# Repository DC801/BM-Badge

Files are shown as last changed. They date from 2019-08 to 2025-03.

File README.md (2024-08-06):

# DC801 Black Mage Badge

The DC801 Badge Platform for DC28+, featuring a [playable web build](https://dc801.github.io/BM-Badge/) to increase ease of access for content authorship workflows, as well as for archival access to the game when for the hardware is no longer available.

## Introducing Chapter 2 (for DC32)

A new expansion for the game has been added! Chapter 2 introduces King Gibson's castle and the badge's built-in USB-C serial interface. More characters, more puzzles, and more puns!

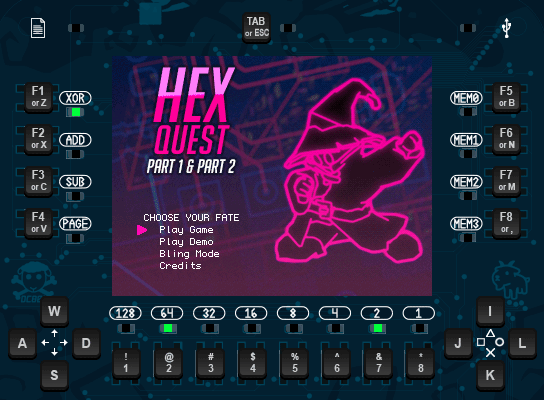
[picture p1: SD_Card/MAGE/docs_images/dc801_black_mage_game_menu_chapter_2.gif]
DC801 Black Mage Game 2024 main menu


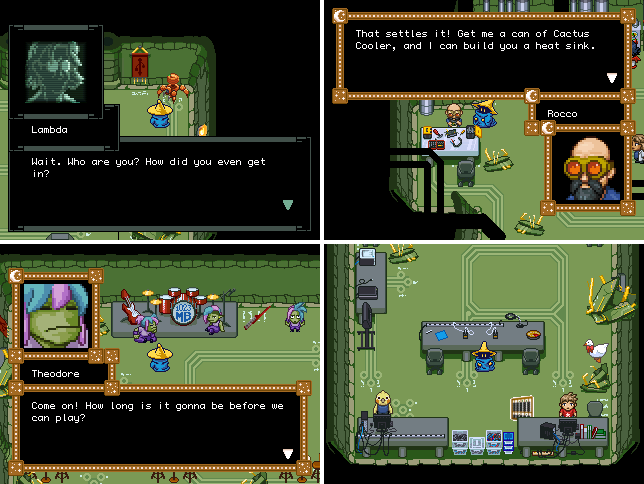
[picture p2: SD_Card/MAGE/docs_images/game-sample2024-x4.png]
DC801 Black Mage Game 2024 sample gameplay (screen only)


Use the terminal to engage with the world and solve puzzles:

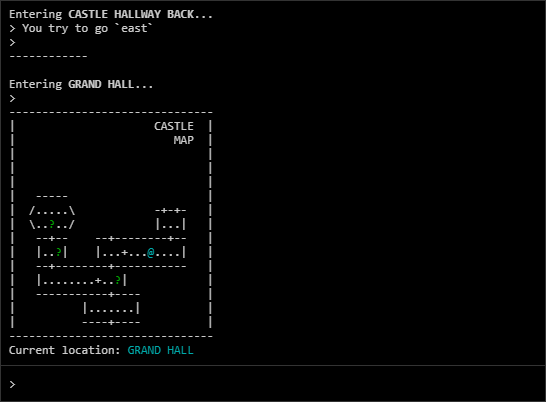
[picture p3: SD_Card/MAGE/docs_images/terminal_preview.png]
DC801 Black Mage Game 2024 sample terminal


Chapter 1 content is still available with this release, and both chapters are accessible from the main menu.

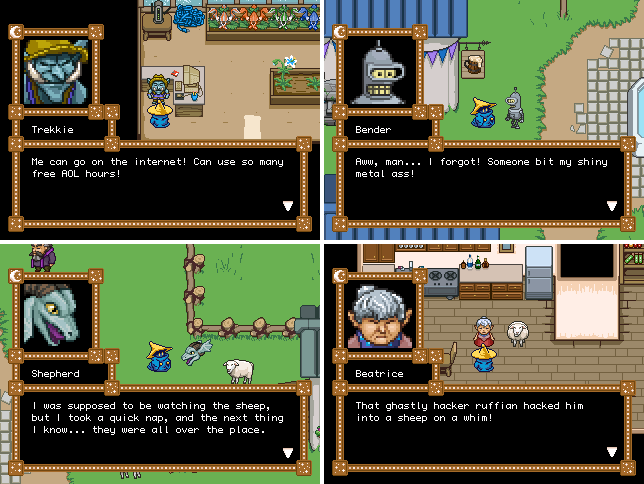
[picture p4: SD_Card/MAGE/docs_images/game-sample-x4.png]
DC801 Black Mage Game 2020 sample gameplay (screen only)


## Videos about the project

<a href="https://www.youtube.com/watch?v=QbsCsldlNKE" target="_blank">
Alex Chaveriat holds the DC801 Black Mage Badge up for your inspection<br />Watch Alex Chaveriat's review of the DC801 Black Mage Badge</a>

----

<a href="https://www.youtube.com/watch?v=-YtiRvzJ-uo" target="_blank">
Alex Chaveriat interviews Hamster at DEFCON 29 about the DC801 Black Mage Badge<br />Watch Alex Chaveriat interview Hamster at DEFCON 29 about the DC801 Black Mage Badge</a>

----

<a href="https://www.youtube.com/watch?v=cmqgIxQA0Sg" target="_blank">
Alex Chaveriat interviews Admiral Potato and Alamedyang about building the DC801 Black Mage Badge<br />Watch Alex Chaveriat interview Admiral Potato and Alamedyang about building the DC801 Black Mage Badge</a>

## Hardware

The DC801 BM-Badge brings you an expandable iteration of our robust platfom.

 - Core CPU is the Nordic nRF52840 SoC, on the u-blox BMD-340 module
   - [https://www.u-blox.com/en/product/bmd-34-series-open-cpu](https://www.u-blox.com/en/product/bmd-34-series-open-cpu)
   - 256k RAM, 1M internal flash, ARM® Cortex™ M4F CP @ 64Mhz
   - Bluetooth 5 with Bluetooth mesh and Zigbee support
   - Temperature sensor
 - 27 buttons with NKRO via a dedicated controller
   - Microchip ATiny1617 microcontroller, with UPDI programming support
   - [https://www.microchip.com/wwwproducts/en/ATtiny1617](https://www.microchip.com/wwwproducts/en/ATtiny1617)
 - 19 LEDs
 - SD card socket
 - 32MB of quad-spi flash
 - NAU8810 audio codec and speaker
 - 2.4" 240x320 TFT LCD screen with touch panel
 - LiPo battery with on-board charging
 - USB-C interface supporting USB endpoints
 - SAO 1.69bis and Saintcon MiniBadge expansion headers
 - Support for the DC801 ART front board expansion
 - JTAG via both standard ARM interface as well as Tag Connect
 - USB drag-and-drop programming via a UF2 interface (based on the [adafruit bootloader](https://github.com/adafruit/Adafruit_nRF52_Bootloader))
 - Exciting new artwork and sandwich design

Board design is in KiCad

See the [HW](/HW) directory for more info, schematics and etc

### ART - Asymmetric Resistive Token
Since this badge is a sandwich platform badge, we've include a template so that you can design your own front boards.

Check out the [Template](/HW/ART/Template) that you can create a new project in KiCad with.

## Software
 - Environment is GNU ARM GCC with your choice of IDE (We're currently using CLion and VSCode)
 - Need a J-Link Segger JTAG programmer to program the chip directly.
 - Custom game engine purpose-built for the badge that can automatically load custom games from the SD Card.
 - Included in the [SD_Card/MAGE](/SD_Card/MAGE) directory is a binary encoder that allows you to generate your own games with our engine using open source tools such as the Tiled Map Editor and our custom json scripting language.
 - Instructions to set up your own dev environment and desktop testing build of our game engine in [EnvironmentSetup.md](/EnvironmentSetup).
 - [Comprehensive engine documentation and content creation guide](SD_Card/MAGE/README.md)

## Gameplay Videos

<a href="https://vimeo.com/487527877" target="_blank">DC28 DC801 SAFEMODE badge, 2020-12-04 development update</a>

[DC28 DC801 SAFEMODE badge, 2020-12-04 development update](https://vimeo.com/487527877): Watch almost 6 minutes of 100% in-engine gameplay in our 2020-12-04 development update video!

<a href="https://vimeo.com/515088170" target="_blank">DC28 DC801 SAFEMODE badge, 2021-02-21 development update</a>

[DC28 DC801 SAFEMODE badge, 2021-02-21 development update](https://vimeo.com/515088170):
Watch one of our puzzles and see some of our new narrative focused engine scripting capabilities in our 2021-02-21 development update video!

----

## DC32 dev team

### Hardware

#### PCB Electronics
- @hamster

#### PCB Art
- corfidbizna
- alamedyang

#### Badge Design
- @admiral_potato
- @hamster

#### Art Board
- redactd

#### Joystick Covers
- @_Pexie

#### Software

#### Engine Lead
- @admiral_potato

#### Script System
- @admiral_potato

#### Script Tooling
- alamedyang
- @admiral_potato
- nibley

#### Programming Support
- Tawnos
- Solra Bizna
- Youssef Moosa
- Cedric Hutchings (cedric_h)

### Graphics

#### 2D Art
- alamedyang
- corfidbizna
- Hippi3Hack3r

#### 3D Art
- @admiral_potato
- nthday

### Story

#### Writing
- alamedyang
- Hippi3Hack3r

#### Scripting
- alamedyang
- ThatDeadGuy and CJDJ
- nibley
- mmedei
- korinakuma

#### Goose Facts Consultant
- lys

### Special Thanks
- 7thdrxn
- Aaron Freed
- anonbecause
- courtyen
- DisplayGFX
- flame3722
- HeyItsWaters
- hipu
- HumanDLC
- korinakuma
- laughdat
- Liam "junkmail" Thomas
- @MuxLuxx
- NewGnu
- @_Pexie
- Solra Bizna
- Spooks
- TuckleberryWinn
- And all the playtesters who we missed!

----

## DC28 dev team

Project owner
- [@nemus](https://twitter.com/Nemus801)

Software Team
- [@_bashNinja](https://twitter.com/_bashNinja)
- [@admiral_potato](https://twitter.com/admiral_potato)
- [@corfidbizna](https://twitter.com/corfidbizna)
- [kiyoshigawa](https://twa.ninja/)
- [@newzie1](https://twitter.com/newzie1)
- [@tazmodius](https://twitter.com/tazmodius)
- @alamedyang

Hardware Team
- [@dvdfreitag](https://twitter.com/dvdfreitag)
- [@hamster](https://twitter.com/hamster)

Honorable Mention
- [@pips801](https://twitter.com/pips801)

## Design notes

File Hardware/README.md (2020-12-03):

We will provide the hardware schematics and KiCAD files once we ship the final badge designs.

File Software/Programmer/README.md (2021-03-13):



## DC801 Production Badge Programmer ##

This app is designed to program both the attiny1617 and the BMD-340 using an Atmel ICE and a JLink device respectively

Programming is accomplished by running batch files in the data directory

Firmware is also in the data directory and is currently hard coded to use a certain version

### Usage

You can either just run the app in the Release\DC801 Badge Programmer directory, or use the installer to install a local application on your PC

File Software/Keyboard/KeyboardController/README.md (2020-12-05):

# Keyboard Controller

This is the keyboard controller for the DC801 BM-Badge platform.

# Hardware

The microcontroller is an [attiny1617](https://www.microchip.com/wwwproducts/en/ATTINY1617) ([datasheet](http://ww1.microchip.com/downloads/en/devicedoc/attiny3217_1617-data-sheet-40001999b.pdf))

Connected to this microcontroller is a 5x6 grid of physical buttons, one capacitive touch button, and a 4 wire resistive touch screen.

Communication with the main processor is via a GPIO for an interrupt line, and a I2C bus, configured as a slave device.

# Key Scanning

The grid consists of 5 rows and 6 columns, but there is only 26 buttons present.  Please refer to the board schematic for the specific layout.

The method for scanning the buttons is pretty simple:

- Set all rows as outputs and to a 'high' state
- Set all cols as inputs with pull up resistors
- Set one row to a 'low' state
- Scan all the cols for state
- If the stored state is different than the current state, emit a key interrupt on the GPIO
- Save the new state
- Lather, rinse, and repeat

# Cap Touch

The wizard's hat is configured as a capacitive touch button using the native Atmel PTC stuff.  There is a 1k resistor between the device and the button.

The button is read every scan for a touch, and will emit a key interrupt if the state changes.

# Resistive touch screen

The touch screen consists of 4 lines, labeled X+, X-, Y+, and Y-.  These lines are connected in a star pattern.  To determine a touch position:

- Set X+ high, and X- low
- Set Y+ and Y- as inputs with no pullups
- Configure the ADCMUX to sense with the Y+ pin
- Measure the voltage present on Y+

To measure for X, swap the X and Y lines in the above and read again.

Basically, you are setting up a voltage gradient across the screen, and where your finger touches the screen forms a voltage divider in proportion to the position across the gradient.

# Software

The software skeleton was created using [Atmel START](https://start.atmel.com/).  From there it was customized in [Atmel Studio](https://www.microchip.com/mplab/avr-support/atmel-studio-7) to support the specific functions required.

# Usage

The chip listens on I2C slave address 0x23.  You don't need to set a register or write to the device first, just start reading data.

The data returned is a snapshot of the current state of the buttons and touch panel.  It is in the format of 6 bytes - the first 4 are treated as a 32 bit value.  Each bit offset in this value describes the state of a button.

See the bm_board.h file for the bit offsets.

Bytes 5 and 6 are the X and Y positions of the touch screen.  Note that even when not touching, it will return a value that is not zero.

You don't need to read all 6 bytes if you don't care about the touch screen, just read 4 bytes.

The Key Interrupt GPIO will strobe low when a key changes state.  It is typically at a 'high' level.  
It will stay low for at least 10ms.  You will then need to read the I2C bus to find out the key state.  In practice it takes about 50ms to toggle a button on and off tapping as quick as you can.

Since the Key Interrupt is tied to the nRF52840 pin for nRESET, it is set to be normally high.  If you don't want your application to reset when a key interrupt comes in, you need to make sure you remove "CONFIG_GPIO_AS_PINRESET" from your application Makefile. See [this page](https://devzone.nordicsemi.com/f/nordic-q-a/18170/how-can-i-disable-reset-of-p0-21) for further info.

Keypresses are not stored or buffered, you must read the state before it changes or ignore the keypress.

Touch screen touch events do not generate an interrupt.

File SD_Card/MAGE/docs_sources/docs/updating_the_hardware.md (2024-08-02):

# Updating the Hardware

Steps for updating a physical Black Mage Game badge.

::: tip Note
The `game.dat` engine version must match the Mage Game Engine (MGE) being run. If you update the engine without updating the `game.dat`, for example, the badge will bluescreen.
:::

## Game Engine

Perform this step if you must upgrade the game engine itself. This is necessary if testing new engine features or if you are updating your badge from Chapter 1 to Chapter 2. (If you are testing new scenario data on the same engine version, this step is not necessary.)

::: warning
Purple "bootleg" badges do not carry the firmware to update in this way. Instead, you will need to have a JTAG Programmer, and will need to know how to use it. Please contact the DC801 Black Mage Badge game team if you want help updating a purple badge.
:::

To start the game in bootloader mode, hold down the hex digit `1` button while you power on the hardware. If bootloader mode was successfully triggered, the screen will be white and the LEDs will blink in a circular pattern.

If the hardware is plugged into a computer while it is in bootloader mode, it will appear as a drive called `DC801BOOT` or `NRF52BOOT`. Copy the new game engine UF2 (the filename doesn't matter) onto the drive.

Once the UF2 is copied, the drive will disconnect. If the badge does not restart automatically at this point, you may restart it now.

### Tips

- Plug into the badge on the USB-C port. This port is on the front, on the upper right side, near the capacitive button that looks like a hat. Do not use the micro USB port (available on some back plates) as this is for programming the lights.
- If the copy seems to be taking a long time (more than 2 minutes) or appears to suffer from other kinds of I/O problem, try using a different USB-C cable.
- Macs with Apple Silicon may display an error message when the drive unmounts, like `The operation can’t be completed because the device disappeared` or `The Finder can’t complete the operation because some data in “bm_badge.uf2” can’t be read or written. Error code -36` You may ignore these.

## `game.dat`

To install new scenario data on the hardware, prepare a microSD card (FAT32) with a folder called `MAGE` in the root directory. Copy the new `game.dat` into `MAGE/`, then insert the card into the slot on the hardware. (The microSD card slot is on the top of the badge, opposite the USB-C port.)

If the hardware determines its `game.dat` is different from the one on the microSD card (or if you hold `MEM3` when turning on the badge), you will see:

```
The file `game.dat` on your SD card does not match
what is on your badge ROM chip.

 SD hash: [game.dat checksum #1]
ROM hash: [game.dat checksum #2]

Would you like to update your scenario data?
------------------------------------------------

> Press MEM0 to cancel

> Press MEM3 to update the ROM
```

Press `MEM3` (the lowest button on the right side of the screen) to tell the hardware to flash the new data. The time it takes to copy will depend on the size of the `game.dat` file, but it may take a few minutes. (The Chapter 2 `game.dat`, released August 2024, takes about 90 seconds.)

The badge should reboot automatically once the write is completed.

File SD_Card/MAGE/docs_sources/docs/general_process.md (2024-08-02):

---
tags: [ 'spritesheets', 'json', 'entities', 'entity', 'animations', 'character', 'tile', 'tileset', 'tiled', 'portraits', 'entity_type', 'collisions', 'vector objects', 'scripts', 'dialogs', 'serial dialogs', 'doors', 'doorways', 'cutscenes', 'encoder' ]
---

# General Process

An example production pipeline. The exact order can vary a bit, and previous steps might be revisited at any point.

## Entities

Prepare entities. For each entity:

1. Acquire or produce [spritesheets](tilesets).
2. In Tiled, [make a tileset JSON file](tilesets#creating-a-tileset-json-file).
	1. Put it in `scenario_source_files/entities/`.
	2. For [character entities](entity_types#character-entity), set the `Class` property for all tiles to what you want the entity's `entity_type` name to be.
	3. Set frames and timings for your [animations](animations), if any.
		1. For [character entities](entity_types#character-entity), prepare [animations](animations) for at least idle, walking, and action.
3. For each [character entity](entity_types#character-entity):
	1. Use the [web encoder](encoder#web-encoder) to [assign animations and NSEW directions](tilesets/entity_management_system).
	2. Paste updated entity data into [`entity_types.json`](mage_folder#entity_types-json).
4. Prepare dialog portraits.
	1. In Tiled, [make a tileset JSON file](tilesets#creating-a-tileset-json-file) for the talk portrait images.
		1. Put it in `scenario_source_files/entities/`.
	2. Prepare [`portraits.json`](mage_folder#portraits-json).
	3. Assign portraits to their entities in [`entity_types.json`](mage_folder#entity_types-json) if the portrait name does not match an [entity_type](entity_types#character-entity) name.

## Maps

Prepare map(s). For each map:

1. Acquire or produce [tilesets](tilesets).
2. In Tiled, [make a tileset JSON file](tilesets#creating-a-tileset-json-file).
	1. Put it in `scenario_source_files/tilesets/`.
	2. Set [tile collisions](tilesets#tile-collisions) for each tile.
3. In Tiled, [create a map](maps) using the tileset(s) from above.
4. Place entities on the map.
	1. Set [entity properties](entity_properties), e.g.
		1. `Name`
		2. `is_player`
		3. [`on_tick`](script_slots#on-tick) script
		4. [`on_interact`](script_slots#on-interact) script
		5. [`on_look`](script_slots#on-look) script
5. [Draw vector shapes](vector_objects), (see [Doors](techniques/doors)) e.g.
	1. Walk paths
	2. Doorways
	3. "Walking out the door" paths
	4. Camera targets
6. Add the map to [`maps.json`](mage_folder#maps-json), and supply properties like its [`on_load`](script_slots#on-load) and [`on_tick`](script_slots#on-tick) scripts.

## Dialog Skins

Prepare dialog skin(s). For each skin:

1. Acquire or produce [tilesets](tilesets).
2. In Tiled, [make a tileset JSON file](tilesets#creating-a-tileset-json-file).
	1. Put it in `scenario_source_files/tilesets/`.
3. Add dialogSkin file(s) to [`scenario.json`](mage_folder#scenario-json).

## Game Logic

Prepare game behavior. You can either use MGS or JSON for this, or even a mix.

1. For MGS files: write [MGS Natlang](mgs/mgs_natlang). (See the natlang docs!)
2. For JSON files (note: you must also add each JSON file to [`scenario.json`](mage_folder#scenario-json) or the game encoder won't see it):
	1. Prepare [dialogs](dialogs) inside `scenario_source_files/dialogs/`.
	2. Prepare [serial dialogs](serial_dialogs) inside `scenario_source_files/serial_dialogs/`.
	3. Prepare [scripts](scripts) inside `scenario_source_files/scripts/`.
		1. Plan logic with flowcharts (optional)

## Encode Game

Encode the `game.dat` using the [encoder](encoder) (either the [web](encoder#web-encoder) version or the [CLI](encoder#cli-encoder) version).

## Play Test

Test the game in one of three ways:

1. [Web build](web_build):
	1. Remember to use the web build appropriate for the version of the encoder you're using!
	2. Drag the new `game.dat` into the browser window.
	3. Run the game.
2. Desktop build (see [MGE VM](mge_vm)):
	1. Move `game.dat` to the right place.
	2. Run the game.
3. Verify on real badge hardware. See: [Updating the Hardware](updating_the_hardware)
	1. Copy `game.dat` onto a microSD card.
	2. Insert the microSD card into hardware.
	3. Flash the game.
	4. Run the game.

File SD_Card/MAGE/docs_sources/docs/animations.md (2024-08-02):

---
tags: [ 'spritesheets', 'tilesets', 'tiled', 'entity', 'entity management system', 'entity_types.json', 'handlers', 'frames' ]
---

# Animations

In Tiled, animations are assigned to tiles within a [spritesheet](tilesets). To an assign an animation to a tile, select a tile — preferably something indicative of what the animation will be, such as a first step for a walking animation — and press the button for the animation editor, which looks like a movie camera:

the fourth icon is a movie camera

You will then see a second window for assigning frames to your animation. Set the frame duration (in milliseconds), then double click on the desired tile to add it as a frame to the animation. You can adjust the timing of the frames or move/remove frames as you like, and you'll be able to see your changes live in the preview directly below.

## MGE Animation Considerations

For [character entities](entity_types#character-entity), you need not prepare an animation for all cardinal directions — e.g. there is only a fright/shock animation in *Chrono Trigger* for the south direction.

The [encoder](encoder) accommodates animation flipping with its [entity management system](entity_management_system), so you don't need sprite tiles for both left-facing and right-facing sprites if you're comfortable with mirroring your left-facing and right-facing sprites.

The Mage Game Engine (MGE) animation system requires that each animation have at least two frames, though, so for animations that aren't actually "animated," you might set two of the same frame back-to-back. #researchthis

## Animation Types

Three types of animations are built into the MGE for [character entities](entity_types#character-entity), and they are triggered in straightforward and predictable ways. [`entity_types.json`](mage_folder#entity_types-json) defines which animations are of which type, and they can be defined and adjusted within the [encoder](encoder) or manually with a text editor.

### Idle

This is what the character entity does by default.

Usually the idle consists of long periods of stillness, followed by a brief fidget: a blink, a small movement of the head, a sheep chewing its cud etc. For flying entities, the idle will likely consist of the entity hovering in place.

The idle animation does not include things like turning around to face different things, nor should it include multiple kinds of fidgets that interact with complex timing. If you want an entity to do more complex behaviors when idle, including facing somewhere specific or playing back other kinds of animations once in a while (a sheep that performs a chewing animation twice a second but lowers its head to chomp a fresh mouthful of grass every 15 seconds), consider using an [`on_tick`](script_slots#on-tick) script to [handle](techniques/handlers) this instead.

Entities look far more alive with an idle animation, even if it's just an occasional blink. Regardless, while the entity need not *appear* to have an idle animation, the MGE still expects one, so you should define one, even if it's just the same two frames back-to-back.

Idle animations are expected to loop seamlessly.

::: tip Best Practice
To avoid robotic synchronization between entities, try to stagger their animation timings by setting the `current_frame` property for that entity on their Tiled map or via [SET_ENTITY_CURRENT_FRAME](actions/SET_ENTITY_CURRENT_FRAME) inside a [script](scripts).
:::

### Walking

This animation plays when entities move within the game. For flying or hovering entities without an explicit walk cycle, you can simply re-use the idle animation.

Walking animations are expected to loop seamlessly.

### Action

This animation plays for the player character when the player presses the "action" button. It can also be deliberately triggered for arbitrary character entities via a script.

::: tip Best Practice
The engine uses the modulo of the animation index for playback, so if there is no action animation defined, likely the idle animation will play instead. If the idle animation is quite long, this means the entity will be frozen in place, doing apparently nothing, for some time. (For the player character, this also prevents the player from moving or doing anything else until the animation is finished.) Therefore, it's best to provide an action animation, even if there aren't sprite tiles prepared specifically for an action animation. Our recommendation is to copy the fidget portion of the idle and to keep it brief.
:::

Action animations are not expected to loop. Instead they are expected to interrupt the idle/walk animation, play once, and then the idle/walk animation will resume.

### Additional Animations

You can add additional animations after the first three, too, as you like.

These animations can only be triggered by scripts, either for an arbitrary number of loops with [PLAY_ENTITY_ANIMATION](actions/PLAY_ENTITY_ANIMATION), or indefinitely with [SET_ENTITY_CURRENT_ANIMATION](actions/SET_ENTITY_CURRENT_ANIMATION).

Any animation set this way will be overridden by the walk animation if the character entity is compelled to move, and the entity will return to its idle after the walk motion is completed. (Teleports are an exception because entities don't switch animations when teleported.)

## Animation Transitions and Vamping

An action animation cannot be started and held (or [vamped](https://en.wikipedia.org/wiki/Ostinato#Musical_theater)) for an indeterminate length of time. If you want an action animation to behave this way, you'll need to split the animation into three pieces: the start transition, the "vamp," and the end transition. Trigger each with a script:

- [PLAY_ENTITY_ANIMATION](actions/PLAY_ENTITY_ANIMATION) with a `play_count` of `1` for the start transition
- [SET_ENTITY_CURRENT_ANIMATION](actions/SET_ENTITY_CURRENT_ANIMATION) for the "vamp," or the portion you want to repeat for an indeterminate amount of time
- [PLAY_ENTITY_ANIMATION](actions/PLAY_ENTITY_ANIMATION) with a `play_count` of `1` for the end transition

See Strong Bad in the Bob-Only Club cutscene in Chapter 1 of the Black Mage Game for an example of this approach.

## MGE Animation Timing

Requirements:

- Animations must have less than 256 frames.
- Frames must be less than 65,535 milliseconds long.
- (Don't worry, these are very difficult limits to hit!)

Animation frames will play for a minimum of one game frame regardless of duration (which, on the badge hardware, is currently in the ballpark of 130 ms, or 8 fps), so animations might play back very slowly in practice if you are frequently using short durations.

::: tip Best Practices
Because animations are not aborted when a character entity faces a new direction (it picks up where it left off in the new direction), it is beneficial to keep each animation of the same type completely uniform in terms of frame count and frame duration. This includes animations with fewer unique frames than others of its type, such as an animation from behind (where the face is obscured).

In addition, we recommend making sure each animation of the same type uses the same tile rows for each frame, even if some of the tiles within the column are technically identical, so that future changes to any of the previously identical frames will not create the need for timing adjustments.
:::

## Assigning Animations to Character Entities

For [character entities](entity_types#character-entity), animations are assigned to an animation type (idle, walk, etc.) and a cardinal direction (north, east, etc.) elsewhere; this cannot be done with Tiled. The [entity management system](entity_management_system) in the [web encoder](encoder#web-encoder) can help you assign animations to character entities if you don't want to do it by hand.

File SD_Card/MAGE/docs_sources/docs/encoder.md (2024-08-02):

---
next: hex_editor.md
---

# Encoder

There are two versions of the encoder, but both produce exactly the same `game.dat` file.

What gets encoded:

1. Everything listed in [`scenario.json`](mage_folder#scenario-json):
	- [scripts](scripts)
	- [dialogs](dialogs)
	- [serial dialogs](serial_dialogs)
	- dialogSkins
3. Portraits found in [`portraits.json`](mage_folder#portraits-json)
4. Entities found in [`entity_types.json`](mage_folder#entity_types-json)
5. Maps found in [`maps.json`](mage_folder#maps-json)
6. All [MGS files](mgs/mgs_natlang) within [`scenario_source_files`](mage_folder#scenario_source_files)

These items are encoded if they're being used by the game in some way; a script that isn't used by any maps, entities, or referenced any included script will be ignored. In other words, entities must be placed on at least one map to be encoded.

Superfluous JSON properties are completely ignored by the encoder. This is the only way documentation or notes can be written in JSON, since JSON doesn't support comments.

```json
"show_dialog-example": [
  {
    "name": "SHOW_DIALOG",
    "dialog": "dialog-example-start",
    "summary": "Oh, hi player! This is an example dialog summary!"
  },
  {
    "name": "SET_ENTITY_INTERACT_SCRIPT",
    "entity": "%SELF%",
    "script": "show_dialog-example-end",
    "to do": "redo with save flags so the branching persists"
  }
]
```

## `game.dat`

The `game.dat` file is the binary file containing all your game scenario content, including images.

Note that [save data](variables#save_data) will persist when using the same `game.dat` file. (Will reflashing the `game.dat` on the hardware wipe the save data explicitly? Probably. #verifyme — this is correct on the web at least.)

There is currently no way to bring save data from an old version of the `game.dat` to a new one, as the data structure of the save data is unlikely to be consistent between versions.

#### Run Your `game.dat`

- [Web build](web_build): Open the web build in your browser, then drag the `game.dat` into the browser window.
	- NOTE: If you play the game a little then drag the same `game.dat` in again, the game will appear to restart afresh — but in fact, save flags and the like may not be reset, **even when you didn't explicitly save inside the game**. Refresh the browser window to wipe existing game state.
- [Desktop build](desktop_build): If you use the [CLI encoder](#cli-encoder) to build the game, the `game.dat` will already be in the appropriate place to run the game. Otherwise, you must move your new `game.dat` to the [`MAGE` folder](mage_folder).
- Badge: see [Updating the Hardware](updating_the_hardware)

Also see: [debug tools](debug_tools)

## CLI Encoder

If you have Node.js installed, you can run the shell script `regenerate_dat_file.sh` to generate a new `game.dat` file. There are two versions of this file:

1. BM-Badge version:
	- `cd` into `MAGE/`.
	- Run the shell script. The `game.dat` will be made from the `scenario_source_files/` in `MAGE/`.
2. [Sample repo](mge_vm) version:
	- first argument: the `scenario_source_files/` folder to read from
	- second argument: where to write the `game.dat`
	- This version of the shell script also launches the game automatically.

This encoder is more useful than the web version when you want to test rapid iterations of your game data, as it is less involved. It is also much faster due to its ability to cache encoded graphics.

## Web Encoder

Open `SD_Card/MAGE/editor/index.html` with a web browser.

Once the page is open, you can either:

1. Drag your [`scenario_source_files`](mage_folder#scenario_source_files) folder into the window.
2. Click the "browse" button and choose the `scenario_source_files` using your operating system's file browser.

Confirm that you want to upload the contents of the folder to your browser, and the encoder will do its magic. If successful, click the "Download game.dat" button, and you're done!

The `game.dat` will be sent to your default download location, so to play it on the desktop build, you'll first have to move it to the correct place by hand or run the shell script `replace_dat_file_with_downloaded.sh`. (`cd` into the `SD_Card/MAGE/` folder before using the shell script!)

This encoder is more useful for times you need to [debug something](debug_tools), or when you want to manage an entity's animations (see below).

### Entity Manager

A special feature of the web version of the encoder is the [entity management system](tilesets/entity_management_system), which you can use to assign animations to [character entities](entity_types#character-entity).

## Debugging

(Don't forget that the game has a built-in [hex editor](hex_editor), too!)

### Encoder Console

Both versions of the encoder will tell you when something has gone wrong during the encoding process, and many errors should be self explanatory, e.g. `"No object named X could be found on map Y!"`

The error `Script: X could not be found in scenario.json` does not necessarily mean there is something wrong with [`scenario.json`](mage_folder#scenario-json), only that the encoder couldn't find a [script](scripts) by that name in any MGS file or in any of the script JSON files `scenario.json` knows about.

If you get the error "unexpected token" it means one of your files has invalid JSON, and you'll need to check your JSON files for invalid syntax. (A good text editor should have some kind of color coding to help you spot such errors.)

### Inspecting WIP Data

You can use the web encoder and your browser's JavaScript console to inspect various aspects about how the encoder interpreted your game files. (You could even interrupt the encoder *while* it collects and processes the data.)

- List of all [save flags](variables#save-flags)
- Number of colors in each tileset's pallet. If trying to reduce the file size of your `game.dat`, it can help to identify which tilesets have more colors than intended.
- …all the rest #expandme

This is most useful when the encoder throws an exception, because you can examine the state of data involved in triggering the error — the console messages alone might not identify which script or variable was causing the problem.

### Kaitai

Kaitai ([ide.kaitai.io](https://ide.kaitai.io)) is a tool that can parse and analyze binary data formats.

Available inside your [`MAGE` Folder](mage_folder) is a file called `mage_dat.ksy`. You can drag this in a Kaitai window, along with your `game.dat`, to analyze in great detail the encoded structure of your game.

This tool lets you easily see the relationship between the hex value of a script/entity_type/dialog/etc. and its name. E.g. if an [entity](entities)'s [`on_tick`](script_slots#on-tick) was being changed unexpectedly, but you only knew the hex value that it's being changed to (perhaps using the [hex editor](hex_editor), using Kaitai to find the name of the script in question can help you track down the problem.

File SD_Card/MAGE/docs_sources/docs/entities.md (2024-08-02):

---
tags: [ 'entity types', 'entity properties', 'hex editor', encoder', 'maps' ]
prev: vector_objects.md
---

# Entities

Entities are a basic element of the Mage Game Engine (MGE).

- All animated graphics must be entities, as ordinary [map](maps) tiles cannot change appearance or move.
- Any single tile object placed in one of a [map](maps)'s object layers will be one of the three [entity types](entity_types), automatically determined by the type of tile being placed.
- All entities have all the same [entity properties](entity_properties) available to them (visible as a pair of rows on the [hex editor](hex_editor) in the game — 32 bytes total). They will all therefore have an [`on_interact`](script_slots#on-interact) and [`on_tick`](script_slots#on-tick) [script slot](script_slots), various render flags, etc.
	- These properties are defined when placed in a Tiled map, but they can be modified during gameplay with [script](scripts) [actions](actions) or by the player via the [hex editor](hex_editor).
- Entities need not have a name, nor a unique name. Scripts targeting an entity by name will simply use the first the [encoder](encoder) found with that name.
- All entity state (apart from the player's name) is reset when a [map load](map_loads) occurs.

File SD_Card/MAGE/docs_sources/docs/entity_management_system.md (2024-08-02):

---
tags: [ 'entity_types.json', 'game.dat', 'character entity', 'entities', 'web encoder', 'idle', 'walk', 'action' ]
next: 'maps.md'
---

# Entity Management System

The Entity Management System is a tool to assign [animations](animations) (created with Tiled) to [character entities](entity_types#character-entity). This allows entity behavior to change its current animation, e.g. walking vs idle, pointing north/east/south/west.

To use the Entity Management System, launch the [web encoder](encoder#web-encoder) and upload your [`scenario_source_files`](mage_folder#scenario_source_files) folder.

::: warning
Changes you make using these tools are not automatically perpetuated to the encoded `game.dat`, nor are they automatically saved to your filesystem. To make your changes permanent:

1. Click the "Copy" button in the red box to put the new [`entity_types.json`](mage_folder#entity_types-json) content into your clipboard.
2. Manually paste into your [`entity_types.json`](mage_folder#entity_types-json) file, replacing all previous content.
3. Run the encoder again.
:::

## New `entity_type`

To assign animations to a new [character entity](entity_types#character-entity):

1. Place a tile from the tileset somewhere in one of your game maps. This ensures the encoder will find it.
2. Open the Entity Management System.
3. In the "Entity Type Editor," type the name of the new `entity_type` (character entity) you wish to create, then click "Create."
4. Select the tileset you wish to use from the drop-down list.
5. The animations pane and tileset pane will now appear.

## Existing `entity_type`

To edit an existing `entity_type` ([character entity](entity_types#character-entity)), choose one with the drop-down list, and then the animation and tileset panes will appear.

## Animations Pane

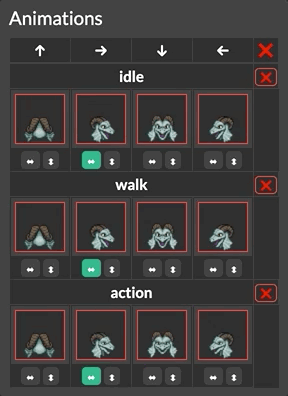
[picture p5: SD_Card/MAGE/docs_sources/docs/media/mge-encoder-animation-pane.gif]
the web encoder's animations pane


- There is one animation tile slot for each cardinal direction: north, east, south, west.
- You can click the arrows underneath the tile to horizontally or vertically flip it. Click again to reverse the flip.
- An entity's first three animations will be interpreted as their idle, walk, and action animations. Each entity should have at least these three.
	- To add another animation, press the "Add Animation" button at the bottom of the animations pane. Note that the Entity Management System will not add more after a certain point, but more may be added by hand, and these *can* be managed with the Entity Management System.
	- Click the red X at the right of an animation to remove it.
- Animation names cannot be changed with this tool.
	- Scripts cannot target animations by name, so naming them is not strictly necessary. It's often useful to be able to identify which one is which, however, so you may want to edit their names by hand.

## Tileset Pane

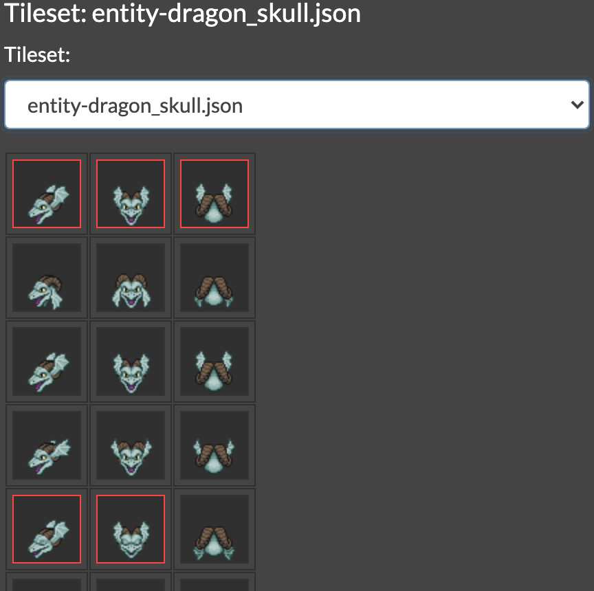
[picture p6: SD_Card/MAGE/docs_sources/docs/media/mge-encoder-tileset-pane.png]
the web encoder's tileset pane


The tileset pane will show every tile in the tileset JSON file. Animation tiles are outlined in red.

You can change the tileset at any time with the drop-down list.

## Assigning Animations

Animations will use the first tile in the tileset by default.

To assign tiles to entity animation slots, click on animation tile in the animations pane (on the left), then click a tileset tile in the tileset pane (on the right).

Selected tiles are outlined in green.

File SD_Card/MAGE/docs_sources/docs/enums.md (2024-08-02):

---
tags: [ 'joystick', 'actions', 'badge', 'hardware', 'lights', 'operators', 'mutate', 'multiply', 'add', 'subtract', 'divide', 'modulo', 'rng' ]
---

# Enums

Some [actions](actions) will only be satisfied by a value from a limited set of words. In such cases, invalid values are reported by the [encoder](encoder).

## Button IDs

[Enum](enums) for [actions](actions) that check the button state.

::: warning INFO
We found that the joystick clicks were aggressive on the hardware, and would trigger at what felt like arbitrary times. While the engine is capable of detecting these clicks, we recommend not using them.
:::

- `MEM0`
- `MEM1`
- `MEM2`
- `MEM3`
- `BIT128`
- `BIT64`
- `BIT32`
- `BIT16`
- `BIT8`
- `BIT4`
- `BIT2`
- `BIT1`
- `XOR`
- `ADD`
- `SUB`
- `PAGE`
- `LJOY_CENTER`
- `LJOY_UP`
- `LJOY_DOWN`
- `LJOY_LEFT`
- `LJOY_RIGHT`
- `RJOY_CENTER`
- `RJOY_UP`
- `RJOY_DOWN`
- `RJOY_LEFT`
- `RJOY_RIGHT`
- `TRIANGLE`
- `X` or `CROSS`
- `O` or `CIRCLE`
- `SQUARE`
- `HAX` (capacitive touch button on the PCB)
- `ANY`

## LED IDs

[Enum](enums) for [actions](actions) that involve the badge lights.

- `LED_XOR`
- `LED_ADD`
- `LED_SUB`
- `LED_PAGE`
- `LED_BIT128`
- `LED_BIT64`
- `LED_BIT32`
- `LED_BIT16`
- `LED_BIT8`
- `LED_BIT4`
- `LED_BIT2`
- `LED_BIT1`
- `LED_MEM0`
- `LED_MEM1`
- `LED_MEM2`
- `LED_MEM3`
- `LED_HAX` (capacitive touch button on the PCB)
- `LED_USB`
- `LED_SD`
- `LED_ALL` (will turn on/off all the lights)

## Comparators

[Enums](enums) used with certain `CHECK_` [actions](actions). (See: [Conditional Gotos](conditional_gotos))

symbol | meaning
---|---
`<`  | less than
`<=` | less than or equal to
`==` | equal to
`>=` | greater than or equal to
`>`  | greater than

There is no `!=` comparator as far as the JSON is concerned. To invert a `==`, set the `expected_bool` to `false`.

## Operations

[Enums](enums) used with the [MUTATE_VARIABLE](actions/MUTATE_VARIABLE) and [MUTATE_VARIABLES](actions/MUTATE_VARIABLES) [actions](actions).

op | meaning
---|---
`SET` | set the variable to that value
`ADD` | add that value to the variable
`SUB` | subtract that value from the variable
`MUL` | multiply that value with the variable
`DIV` | divide that variable by the value (integer division; rounds down to whole number)
`MOD` | apply that modulo to the variable (≈ division remainder)
`RNG` | set that variable to a random number between 0 and 1 + the given value

::: warning
Seriously, don't forget to subtract one when using `RNG`! If you want a random number between `0` and `9`, you want to put `RNG 10`!)
:::

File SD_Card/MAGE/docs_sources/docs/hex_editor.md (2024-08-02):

---
prev: encoder.md
---

# Hex Editor

The hex editor is a unique feature of the Mage Game Engine (MGE) that allows you to view and edit [entity properties](entity_properties) for [entities](entities) in the live game.

If hex editor control is turned off, the hex editor will not open and values cannot be changed.

## Opening the Hex Editor

Press the capacitive button (the hat) on the top of the physical badge to open the hex editor. (On the web, press `ESC` or `TAB` or click the button in the upper-left corner.) Repeat to close the hex editor again.

Remember that you can select a byte in the hex editor and watch its value change (or change it yourself) live in the overworld — you need not open the hex editor all the time to monitor a single value while playing the game.

## Selecting a Value

There are several methods:

1. Once inside the hex editor, use the arrow joystick (on the web, use the arrow keys or the WSAD keys) to control which byte is selected.
2. In the overworld, you can face an entity and press the triangle button to open the hex editor and jump to the first byte of that entity's struct.
3. Use the `MEM0` through `MEM3` buttons to jump to a saved byte offset within the currently-selected entity struct.
	- These saved offsets can be changed by holding `PAGE` and pressing the target `MEM` button.

## Changing a Value

The `XOR`, `ADD`, and `SUB` buttons on the left side of the screen change the operator mode for the bit buttons below the screen. E.g. to add 4 to the value, set the mode to `ADD` and press the `4` bit button.

While inside the hex editor you can also increment and decrement the selected value by 1 using the triangle and X buttons.

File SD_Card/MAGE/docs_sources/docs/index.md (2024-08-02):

# Mage Game Engine (MGE) Documentation and Content Creation Guide

Content creation guide for the "Mage Game Engine" (MGE), and other information for working with the "Black Mage Game" for DC801's party badge.

## Table of Contents

- [What You'll Need](what_youll_need)
- [General Process](general_process)
- [`MAGE` Folder](mage_folder)

### Assets

- [Tilesets](tilesets)
	- [Animations](animations)
	- [Entity Management System](tilesets/entity_management_system)
- [Maps](maps)
	- [Map Loads](map_loads)
	- [Map Properties](map_properties)
	- [Vector Objects](vector_objects)
- [Entities](entities)
	- [Entity Properties](entity_properties)
	- [Entity Types](entity_types)
	- [Relative References](entities/relative_references)

### Structure

- [Comments](comments)
- [Variables](variables)
	- [Printing Current Values](variables#printing-current-values)
	- [Enums](enums)
- [Dialogs](dialogs)
- [Serial Dialogs](serial_dialogs)
- [Scripts](scripts)
	- [Script Slots](script_slots)
	- [null_script](scripts#null_script)
	- [Scripting Techniques](techniques/scripting_techniques)
		- [Actors](techniques/actors)
		- [Coordinate Considerations](techniques/coordinate_considerations)
		- [COPY_SCRIPT Uses](techniques/copy_script_uses)
		- [Cutscenes](techniques/cutscenes)
		- [Doors](techniques/doors)
		- [Handlers](techniques/handlers)
		- [Hiding an Entity](techniques/hiding_an_entity)
		- [Map Initialization Scripts](techniques/map_initialization_scripts)
		- [One Script, Multiple Behaviors](techniques/one_script_multiple_behaviors)
		- [Spawn Points](techniques/spawn_points)
- [Action Dictionary](actions)

### MGS Natlang

- [MGS Natlang](mgs/mgs_natlang)
	- [MGS Natlang Structure](mgs/mgs_natlang_structure)
		- [Blocks](mgs/blocks)
		- [Variables (MGS)](mgs/variables_mgs)
	- [Advanced Syntax](mgs/advanced_syntax)

### Technical

- [Encoder](encoder)
- [Debug Tools](debug_tools)
- [Updating the Hardware](updating_the_hardware)

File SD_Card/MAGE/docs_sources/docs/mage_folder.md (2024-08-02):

---
tags: [ 'web encoder', 'game.dat', 'shell script', 'mage_dat.ksy', 'mgs natlang', 'tiled', 'json', 'tiles', 'tilesets', 'map properties' ]
next: 'tilesets.md'
---

# `MAGE` Folder

There'll be a bunch of stuff in the `MAGE/` folder, but relevant to creating new content are:

| File | Purpose |
|:--|:--|
| `editor/index.html` | The [web encoder](encoder#web-encoder).
| `game.dat` | Encoded game data. Your `game.dat` must be here for the [desktop build](desktop_build) to see it. (The [CLI encoder](encoder#cli_encoder) will update the `game.dat` in place.)
| `replace_dat_file_with_downloaded.sh` | Grabs the latest `game.dat` from your Downloads folder and moves it to your current directory.
| `regenerate_dat_file.sh` | The [CLI encoder](encoder#cli-encoder). There are two versions depending on which repo you started with; the version from the [MGE VM](mge_vm) is slightly different. Requires `node.js`.
| `mage_dat.ksy` | For debugging your `game.dat` with [Kaitai](encoder#kaitai).
| `scenario_source_files/` | Raw game assets, scripts, etc. (See below!)

## `scenario_source_files`

::: tip JSON at its core
[MGS Natlang](mgs/mgs_natlang) has dramatically simplified game scripting, but JSON remains the true underlying structure of game scenario data.
:::

The folders described below provide the only means for the encoder to tell JSON files apart. (In contrast, MGS files contain multiple types of data, so all MGS files anywhere in the `scenario_source_files` folder are treated the same way.)

JSON file names should be prefixed with the type of MGE data they contain, even when they're placed inside the corresponding folder. This will make them easier to debug.

Make sure all Tiled files are in the correct place before working on them or references to them will break when you move them.

## Folders

Folders inside `scenario_source_files`:

| folder | file types | purpose |
|---|---|---|
| `dialog/` | MGE [dialog](dialogs) files (JSON) | RPG-style dialog messages for the main game screen |
| `entities/` | Tiled [tilesets](tilesets) (JSON), [spritesheets](tilesets) (PNG/GIF) | [entity](entities) assets |
| `maps/` | Tiled [maps](maps) (JSON) | map data (not including tilesets) |
| `mgs/` | [MGS Natlang](mgs/mgs_natlang) files (MGS) | these files need not be anywhere specific, but they're best kept together if nothing else |
| `serial_dialog/` | MGE [serial dialog](serial_dialogs) files (JSON) | words to be printed on the serial terminal |
| `scripts/` | MGE [script](scripts) files (JSON) | determines the bulk of the behavior of the game |
| `tilesets/` | Tiled [tilesets](tilesets) (JSON), [spritesheets](tilesets) (PNG/GIF) | non-entity assets, such as graphics for maps, dialog borders, etc. |

## Files

JSON files inside `scenario_source_files`:

### `scenario.json`

This file tells the [encoder](encoder) which JSON files to include for its scripts, dialogs, maps, and dialogSkins processing.

It will look something like this:

```json
{
  "scriptPaths": [
    "scripts/script-example-1.json",
    "scripts/script-example-2.json"
  ],
  "dialogPaths": [
    "dialog/dialog-example.json",
    "dialog/dialog-definitely-an-example.json",
    "dialog/dialog-examples-for-days.json"
  ],
  "serialDialogPaths": [
    "serial_dialog/serial_dialog-example.json"
  ],
  "dialogSkins": {
    "default": "tilesets/tileset-dialog_moon.json",
    "codec": "tilesets/tileset-dialog_codec.json",
    "menu": "tilesets/tileset-dialog_transparent_menu.json"
  }
}
```

`scriptPaths`, `dialogPaths`, and `serialDialogPaths` each contain a list (JS array) of all file paths you want the game encoder to see.

`dialogSkins` is a list (JS object) of dialog skin names mapped to the file path of their tileset JSON file. The "name" is what you'll use to target that dialog skin. A `dialogSkin` called `default` is mandatory.

### `entity_types.json`

Identifies [character entities](entity_types#character-entity) and assigns them various properties, such as:

- `tileset`: their tileset JSON file path
- `portrait`: the name of their portrait image, if not the same as their `entity_type` name (optional)
- `animations`: their [animation assignments](tilesets/entity_management_system) (idle, walk, action, etc. — and north, south, west, east)

As an example (keeping in mind that the animation arrays have been closed so the overall structure is more clear):

```json
{
  "mage": {
    "tileset": "entity-mage.json",
    "animations": {
      "idle": [],
      "walk": [],
      "action": []
    }
  },
  "bender_sadbutt": {
    "tileset": "entity-bender_sadbutt.json",
    "portrait": "bender",
    "animations": {
      "idle": [],
      "walk": [],
      "action": [],
      "bite": []
    }
  }
}
```

Animations are much easier to do using the [web encoder](encoder#web-encoder)'s [entity management system](entity_management_system), but if you want to make changes to an entity's animations by hand, the structure is as follows:

```json
"idle": [
  { "tileid": 18, "flip_x": false },
  { "tileid": 16, "flip_x": true },
  { "tileid": 17, "flip_x": false },
  { "tileid": 16, "flip_x": false }
]
```

When animations are created within Tiled, they are assigned to a tile on the tileset. So for the above definitions, `tileid` refers to which tile the animation has been assigned to.

To find the `tileid`, count left-to-right and top-to-down, but remember to count starting from 0 instead of 1. Alternatively, you can select the correct tile in Tiled and see the tile ID that way.

`flip_x` will flip the sprites horizontally (and `flip_y` will flip vertically), but will otherwise make no changes to the animation on that tile.

The order of the object literals in the animation is fixed:

- North
- East
- South
- West

Each character entity should at least have an idle, walk, and action animation. (See: [Animations](animations))

### `maps.json`

This file is new for the chapter 2 version of the MGE.

[Map properties](map_properties) defined in a map's Tiled JSON file (as was done in chapter 1) are still honored (for now!), but it's recommended to move such properties to this file for easier access.

The first map given is the map run when the game is opened.

```json
{
  "sample1": {
    "path": "maps/map-sample1.json",
    "on_load": "on_load-sample",
    "on_look": "on_look-sample",
    "on_tick": "on_tick-sample",
    "directions": {
      "north": "on_go-sample-map",
      "south": "on_go-sample-map"
    }
  },
  "sample2": {
    "path": "maps/map-sample2.json"
  }
}
```

### `portraits.json`

Data for portraits, which reference tileset JSON files from the `entities/` folder. Portrait names should match associated [entity_type](entity_types#character-entity) names, if any.

```json
{
  "baker": {
    "tileset": "portraits-people.json",
    "emotes": {
      "default": {
        "tileid": 15,
        "flip_x": true
      }
    }
  },
  "bender": {
    "tileset": "portraits-people.json",
    "emotes": {
      "default": {
        "tileid": 21,
        "flip_x": true
      },
      "laugh": {
        "tileid": 22,
        "flip_x": true
      }
    }
  }
}
```

`tileset` is the file path for the [tileset JSON file](tilesets) with the portrait image.

`tileid` is how you define which tile in the tileset you want to use. You can simply count the tiles in the tileset left-to-right and top-to-down, beginning from `0`, but it might be easier to select the appropriate tile within Tiled and see what it says the "ID" is.

Game portraits are determined to be in their default position when alignment is `BOTTOM_LEFT` (or `TOP_LEFT`). For normal RPG-style contexts, you'll want your entities facing the center of the screen, which means your graphics should face the right in the tileset file. (These graphics are flipped automatically when used in the `BOTTOM_RIGHT` or `TOP_RIGHT` position.) If the portraits in your tileset image aren't facing the right, you should set `flip_x` to `true`.

You should at least have a `default` emote, but you can define any others as you like. Emotes are currently identified by their index / `id`.

The MGE supports animated emotes. To animate an emote, create an animation for that tile the same way you would [make an entity animation](animations).

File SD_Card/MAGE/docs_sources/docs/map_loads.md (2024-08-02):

---
tags: [ 'maps.json', 'cutscene', 'on_load', 'debug mde', 'save data', 'entity', 'entities', 'script slots', 'terminal', 'serial', 'COPY_SCRIPT' ]
---

# Map Loads

The first [map](maps) listed in [`maps.json`](mage_folder#maps-json) is the map the game will load when first turned on.

Maps can be assigned an [`on_load`](script_slots#on-load) [script](scripts), which will run once when a map is loaded.

## To Reload the Current Map

Do one of the following to reload the current map:

1. Toggle [debug mode](debug_tools#debug-mode): `XOR` + `MEM1` (or `F1` + `F6` on desktop)
2. Soft reset current map: `XOR` + `MEM3` (or `F1` + `F8` on desktop)
3. Target the current map with [LOAD_MAP](actions/LOAD_MAP). (This behavior is equivalent to #2)

## Game State

### Preserved

[Save data](variables#save_data), including the player name, persists between map loads.

### Not Preserved

All [entity](entities) state is reset (apart from the player name). This includes every entity's appearance, [script slots](script_slots) (both their script assignments and their progress within their scripts), and location.

All registered [terminal](terminal) [commands](commands) are reset. For a command that needs to persist throughout the game, you must initialize them afresh at the beginning of the map load. (We recommend using [COPY_SCRIPT](actions/COPY_SCRIPT) on a separate [map initialization script](techniques/map_initialization_scripts) so that such logic checks can be shared between all relevant maps.)

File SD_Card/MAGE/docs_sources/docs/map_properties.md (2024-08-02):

---
tags: [ 'maps.json', 'tiled', 'save flags', 'doors', 'game tick', 'entities', 'entity', 'doorways', 'terminal', 'command', 'look', 'register', 'go', 'exits', 'registration' ]
---

# Map Properties

Map properties reside either inside [`maps.json`](mage_folder#maps-json) (preferred) or inside a JSON map file (legacy). (To see the map's properties within Tiled, go to "Map > Map Properties….")

Example `maps.json`:

```json
{
  "sample1": {
    "path": "maps/map-sample1.json",
    "on_load": "on_load-sample",
    "on_look": "on_look-sample",
    "on_tick": "on_tick-sample",
    "directions": {
      "north": "on_go-sample-map",
      "south": "on_go-sample-map"
    }
  },
  "sample2": {
    "path": "maps/map-sample2.json"
  }
}
```

## `path`

Where the map JSON file is located and what it's called.

## `on_load`

The [`on_load`](script_slots#on-load) script plays when the map is first loaded, and will only run once.

This is best used for checking [save flags](variables#save-flags) and restoring state that is meant to be permanently changed.

## `on_tick`

The [`on_tick`](script_slots#on-tick) script will execute, allow all other scripts to take a turn, and then execute again on the next game tick.

Because the player cannot use the [hex editor](hex_editor) to directly alter which script is run in a map's `on_tick` slot like they can an entity's `on_tick` slot, this slot is fairly well protected — useful for doors.

## `on_look`

The [`on_look`](script_slots#on-look) script plays when you run the `look` [command](commands) in the [terminal](terminal) without any arguments.

NOTE: You can override this script if you [register](actions/REGISTER_SERIAL_DIALOG_COMMAND_ARGUMENT) a `look` command manually.

## `directions`

These scripts run when the command `go` is run with the named argument, e.g. `go north`.

These directions will be listed after a maps `on_look` script is triggered (e.g. `exits are...`). Unfortunately, this can result in confusion if you want multiple names per exit (e.g. `go north` and `go tunnel`), so here you should only include directions you want explicitly printed, and use manual [registrations](actions/REGISTER_SERIAL_DIALOG_COMMAND_ARGUMENT) for everything else.

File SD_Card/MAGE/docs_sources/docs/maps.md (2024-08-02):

---
tags: [ 'tiled', 'json', 'animations', 'doors', 'doorways', 'coordinate overflow', 'entity properties' ]
prev: 'entity_management_system.md'
---

# Maps

## Creating a Map JSON File

Within Tiled:

1. Go to "File > New Map…"
2. Set the following properties:
	- Orientation: Orthogonal
	- Tile layer format: CSV
	- Tile render order: Right Down
3. Map size can be changed later, so don't worry about setting it correctly right now.
	- The map size limit for the MGE is quite large. Don't worry about surpassing this limit. (What is the limit though? #researchthis )
4. For Tile size, use the tile size for the tileset you intend to use for this map. (Black Mage Game tilesets are 32x32.)
5. Save the map file:
	- Set the format to JSON.
	- Make sure the file name ends with `.json`.
	- Set the correct destination folder: `scenario_source_files/maps/`. (Careful, as Tiled will default to the file path of the last file currently open. You don't want to move this file later!)

You will be using the Tileset view a lot when working on a map, which you can make visible (if invisible) via "View > View and Toolbars > Tileset."

For MGE maps, you'll be using tile layers and object layers alone:

## Tile Layers

Placing tiles is fairly intuitive, but know that you can press **X** to flip and **Z** to rotate a tile you are about to place. See [Tiled's documentation](https://doc.mapeditor.org/en/stable/manual/editing-tile-layers/) for more information.

In the MGE, the topmost tile layer is drawn on top of entities. All others are drawn underneath. (Entities themselves are Y-indexed when drawn.)

::: warning Appearance in Tiled vs MGE
Animations placed on a tile layer will *not* play back within the MGE, regardless of how things may appear within Tiled.

Similarly, placing a tile of the incorrect size on a map will result in divergent behavior between Tiled and the MGE. Make sure all tiles placed are the same size as the map's tileset.
:::

### MGE Tile Layer Considerations

Each additional layer adds overhead to the draw time. Currently, it's recommended to limit tile layers to three or less: one for the top (to appear above entities), and one or two for underneath (to appear below entities).

For the Black Mage Game, we use two base layers: one for the base terrain, and one for terrain doodads with alpha.

In addition, because each tile increases the draw time, it's best to remove tiles that are completely obscured by fully opaque tiles.

## Object Layers

Vector polygons and points are placed on object layers, but tiles can be placed this way, too, if you use the "Insert Tile" button on the vector section of the toolbar (shortcut **T**) — and this is how entities are added to a map.

Vector objects are susceptible to [coordinate overflow](vector_objects#coordinate-overflow), so try to keep objects and all their vertices inside the map coordinate space (unless you actually want to yeet an entity to outer space).

::: tip Best Practice
Particularly on maps with a lot going on, it's best to place objects on separate layers so you can easily hide or reveal specific objects, e.g.:

- the entities themselves
- door and exit paths
- cutscene paths and camera points

It doesn't matter how many layers there are in terms of accommodating the [encoder](encoder), but it's best to place the layer for entities just below the topmost tile layer, at least, for the most accurate visual preview.
:::

### Placing Entities

Entities are placed as tiles on an object layer with the "Insert Tile" button (shortcut **T**). The [type of entity](entity_types) placed and a few of its [entity properties](entity_properties) are determined by which tile you use, but other entity properties must be explicitly set.

Entities are Y-indexed in the MGE, meaning they are rendered in front of or behind other entities according to their Y position. For entities being used as environment props, this can result in odd behavior (e.g. the player appearing underneath a bundle of cables if they walk too far behind it).

Each map can have a maximum of 64 entities.

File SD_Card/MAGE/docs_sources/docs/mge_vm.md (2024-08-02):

---
tags: [ 'google drive', 'visual studio code', 'chromium', 'repo' ]
---

# MGE VM

::: warning
This VM image was prepared for the Chapter 1 version of the Mage Game Engine (MGE), back before there was a web build to use.

Seriously, just use the [web build](web_build) now! It's so much easier!
:::

## Download the VM image

The [VM image](https://drive.google.com/file/d/1S3qmwfSq9DD3EdxqE4Bh8B2QsWe1d85-/view?usp=sharing), available to download from Google Drive, is approximately 6GB.

In case you need to `sudo` anything:

```
username: dc801
password: helga
```

## VirtualBox

1. Install [VirtualBox](https://www.virtualbox.org/).
2. Go to File > Import Appliance, then find the .ova file you downloaded previously.
	- The expanded VM image will be about 12GB, but can become as large as 32GB (depending on what you do inside it), so keep that in mind when choosing where to put it.

## To Run the Game

### First Time

Double click `pull_latest_and_build.sh` to download and compile the latest version of the MGE. The game will launch itself. Close the window when finished.

### Thereafter

To run the game without compiling it again, double click `start_game.sh`.

## Game Development

You could do all your game development in your host OS, but you might have to be a bit clever to get the encoded `game.dat` inside the VM environment. Instead, consider doing your game development 100% inside the VM:

- Double click `open_ide.sh` to launch Visual Studio Code, which has been set up for you.
- Launch Chromium by clicking the "whisker menu" in the top-left corner of the screen, then click "Web Browser." (You'll need Chromium to use the [web encoder](encoder#web-encoder).)

## Raw Game Data Folders

The VM already contains the raw game data for the Black Mage Game, which you could copy to use as a template for your own project, but we have also prepared a bare-bones [sample project repo](https://github.com/AdmiralPotato/mage_game-external_scenario_source_files), which has all of the necessary structure but without the bloat of the finished game.

The [encoder](encoder) is capable of generating a `game.dat` file from an arbitrary `scenario_source_files/` folder, so having multiple project folders is not a problem.

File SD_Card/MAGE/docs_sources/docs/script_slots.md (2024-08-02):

---
tags: [ 'entity', 'entities', 'game tick', 'scripts', 'command', 'null_script', 'terminal', 'RUN_SCRIPT' ]
next: actions.md
---

# Script Slots

Multiple [scripts](scripts) can run at the same time (strictly speaking, they all take turns one after the other during any single game tick), but you cannot arbitrarily run an indefinite number of scripts. Instead, entities and maps have "script slots" that are each able to run one script.

- Each [entity](entities) has:
	- one [`on_interact`](#on-interact) slot
	- one [`on_tick`](#on-tick) slot
	- one [`on_look`](#on-look) slot
- The currently-loaded [map](maps) has:
	- one [`on_load`](#on-load) slot
	- one [`on_tick`](#on-tick) slot
	- one [`on_look`](#on-look) slot
- There is also [command](commands) slot for the serial [terminal](terminal).

#verifyme — do the `on_look` slots use the `command` slot? They have their own space on the entity struct, so....

## `on_interact`

If the player presses the interact button and the interact hitbox hits another entity, that entity's `on_interact` script will run. (You can watch this happen with [vector view](debug_tools#vector-view).)

Scripts run in the `on_interact` slot will stop once they reach the end of their list of actions. Very commonly, a [character entity](entity_types#character-entity)'s `on_interact` script will be the start script of their [dialog](dialogs) tree.

If the script in this slot jumps to another script at some point, interacting with that entity again will result in the last-used script being run again, not whatever the original `on_interact` script was. Therefore, if you wish an entity to begin all interactions with the first script in its interact tree, you must explicitly [reset](actions/SET_ENTITY_INTERACT_SCRIPT) its `on_interact` script at the end of each of its script [branches](techniques/beginnings_middles_and_ends).

## `on_tick`

`on_tick` scripts continuously evaluate every game tick. Once an `on_tick` script reaches the end of its list of [actions](actions), the script will return to the beginning of the currently set script and run again on the next game tick.

::: danger
This means that if you [goto](actions/RUN_SCRIPT) the same script you started from as the `on_tick` script's last action, the script slot will NEVER give up its turn! You probably want to use [SET_ENTITY_TICK_SCRIPT](actions/SET_ENTITY_TICK_SCRIPT) or [SET_MAP_TICK_SCRIPT](actions/SET_MAP_TICK_SCRIPT) instead, which will set the target script for that slot but NOT immediately execute like [RUN_SCRIPT](actions/RUN_SCRIPT) would.
:::

A map's `on_tick` script slot is a logical place for a script that watches for whether the player enters a [doorway](techniques/doors), but `on_tick` scripts are useful for other kinds of watch scripts, too, such as changing an entity's idle behavior after a condition has been met.

`on_tick` slots are what you should use if you want to be able to interrupt or abort a script at an arbitrary place or time e.g. with a button press, or when the player crosses a [collision trigger](vector_objects), etc.

To terminate an `on_tick` script, it must [goto](actions/RUN_SCRIPT) [null_script](scripts#null_script) as one of its actions, or another script must tell it to switch to `null_script`.

## `on_load`

A maps's `on_load` script runs when a map is first loaded. Like an `on_interact` script, once the script reaches the end of its list of actions, the script stops.

These are useful for identifying and re-implementing the "permanent" changes the player has done on that map, as well as making decisions as to whether a [cutscene](techniques/cutscenes) should be played on that map upon [load](map_loads) (e.g. at the beginning of the game).

## `on_look`

`on_look` scripts are run when the player uses the `look` command in the [terminal](terminal).

`look` on its own triggers the maps's `on_look` script. `look` + the [current name](variables#printing-current-values) of an entity will trigger that entity's `on_look` script.

`on_look` scripts can be overridden with a manual [command](commands) registration.

## One Slot, One Script

Importantly, a script slot can only run one script — if a script jumps to another script (either with [RUN_SCRIPT](actions/RUN_SCRIPT) or by [script jumping via some kind of logic check](conditional_gotos)) the current script is *completely abandoned* and the new script is run instead. It is therefore important to check the order in which actions are given, as any action listed after a script jump will be ignored.

There is no call stack — no means for a script to jump to another script and then pick back up where it left off.

Nor is it possible to do more than one logic check simultaneously. If you want to check multiple conditions at once, you must branch to a different script for each aspect of the fail condition and let the remainder of the original script contain the actions for the success condition. [MGS Natlang](mgs/mgs_natlang) simplifies this by allowing multiple conditions to be written per behavior block, but these conditions can only be linked with OR (`||`) not AND (`&&`) for this reason.

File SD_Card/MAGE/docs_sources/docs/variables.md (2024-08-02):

---
tags: [ 'action', 'script', 'map loads', 'save data', 'strings', 'booleans', 'integers', 'negative numbers', 'doors', 'spawn points', 'cutscenes', 'on_load', 'given name' ]
prev: relative_references.md
---

# Variables

There are only a few Mage Game Engine (MGE) variables available for [scripts](scripts) to use. All variables are equally accessible to all scripts at all times (globals).

Variables don't have to be declared before they can be used; simply using an [action](actions) that sets or checks one will cause the encoder to include it in the `game.dat`.

::: warning
This means that typos in variable names can be hard to spot. If you set `birthdayparty` but check `birthday_party`, the encoder will create and store both variables as if they were separate things.

If you find a variable isn't triggering logic checks in the ways you expect, check your spelling!
:::

All variables are persistent between [map loads](map_loads) because all are all included in the [save data](variables#save-data).

::: details For some dubious alternatives...
Every [property](entity_properties) on every [entity](entities) is available for scripts to read and/or change, and might be used like normal variables. However, in practice, these might have limited utility because the player can [change these values directly](hex_editor) and these values are reset upon [map load](map_loads).
:::

## `warp_state`

This is a single **string** that is designated for controlling player spawn behavior on a map's [`on_load`](script_slots#on-load) script. When you [leave a room](techniques/doors) (or otherwise trigger a new [map](maps) to load), the `warp_state` string should be set to something that indicates the exit/entrance point so the next map can teleport the player entity to the appropriate [spawn point](techniques/spawn_points).

Handling player spawn points is the original purpose for `warp_state`, but there's nothing stopping you from using it for other things, too.

## Integer Variables

**Integer** variables are `uint16_t`, meaning they can be any whole number between `0` and `65535`. (No negative numbers, no `NaN`.) You may have up to 255 of these.

The default value is `0`.

## Save Flags

Save flags are **booleans** with arbitrary names (strings) that can be used for various logic checks. You may have up to 65535 of these.

Common use cases for save flags include tracking whether the player has:

- heard specific entities' backstories
- seen specific [cutscenes](techniques/cutscenes)
- completed specific puzzles
- found specific secrets

You will likely need to employ [chains of small checks](techniques/chains_of_small_checks) at the beginning of your [map](maps)'s [`on_load`](script_slots#on-load) [script](scripts) to initialize the map based on the states of save flags like those above.

## Printing Current Values

The values of [integer variables](variables#integer-variables) and the **current names** of any [entity](entities) can be inserted into a dialog message, dialog label, or similar places.

### Current Variable Value

Enclose the name of the variable in dollar signs, like this: `$appleCount$`

```mgs
exampleScript {
  mutate appleCount = 10;
  show serial dialog { "I have $appleCount$ apples for sale today!" }
}
```

The above script will produce:

```
I have 10 apples for sale today!

>_
```

[MGS Natlang](mgs/mgs_natlang) will wrap text automatically, but if wrapping by hand, it's recommended to count these as taking up 5 characters.

### Current Entity Name

Wrap an entity's **given name** (the name assigned to it in Tiled) in percent signs (`%`) to insert the entity's name as it currently exists in RAM: `"Hi, there! My name is %Bob%!"`

Unlike with [relative entity references](entities/relative_references) (like [`%SELF%`](relative_references#self) and [`%PLAYER%`](relative_references#player)), this usage will not work when trying to target an entity with an action.

[MGS Natlang](mgs/mgs_natlang) will wrap text automatically, but if wrapping by hand, it's recommended to count these as taking up 12 characters.

## Other State

These states are not preserved in game saves, but do persist through map loads (#verifyme). Control these with the actions listed:

- **player control**: whether the player can move, interact with entities, use the hex editor, or perform other actions ([SET_PLAYER_CONTROL](actions/SET_PLAYER_CONTROL))
- **hex editor control**: whether the player can open the hex editor ([SET_HEX_EDITOR_CONTROL](actions/SET_HEX_EDITOR_CONTROL))
- **hex editor clipboard control**: whether the player can use the hex editor clipboard ([SET_HEX_EDITOR_CONTROL_CLIPBOARD](actions/SET_HEX_EDITOR_CONTROL_CLIPBOARD))
- **auto lights control**: whether the LEDs around the screen are controlled automatically or manually ([SET_LIGHTS_CONTROL](actions/SET_LIGHTS_CONTROL))
- **serial dialog control**: whether the player can enter anything into the serial console ([SET_SERIAL_DIALOG_CONTROL](actions/SET_SERIAL_DIALOG_CONTROL))

A few other states can be checked and manipulated, but due to their nature, these are not included in game save data, nor do they persist between map loads:

- whether a dialog is open
- whether a serial dialog is open
- whether debug mode is on

## Save Data

The state that is preserved when a game is saved includes:

- The [warp_state](variables#warp-state) value
- All [save flag](variables#save-flags) values (booleans)
- All [integer variable](variables#integer-variables) values (uint16)
- The player's name (string)
- `MEM` button offsets (the player can change the `MEM` button mapping)
- hex editor clipboard contents (up to 32 bytes)
- current map id (NOTE: this is saved, but not currently used upon load; player position is captured and restored manually in the Black Mage Game)

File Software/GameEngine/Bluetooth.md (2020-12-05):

# Defcon Badge Bluetooth Protocol

So you might have noticed that multiple badges talked to each other this year.  How did we do that?  Well, the magic is in the BLE advertising packet.

This packet can be up to 31 bytes long, and consists of a series of 'blocks'.  Each block starts with a byte that indicates how many bytes follow in this block, next byte is the block type, then the rest of the bytes are the block content.

The key parts of the Defcon Badge protocol before it are the Appearance value, according the table below, and the manufacturer block, which defines which badge this is.  The rest of the packet can be whatever you want it to be.

Badge year (appearance value)
 - Defcon 25 - 0xDC19
 - Defcon 26 - 0xDC26
 - Defcon 27 - 0xDC27
 - Defcon 28 - 0xDC28

Here's a visual of a packet that my DC801 badge broadcasted:

Advertising Layout

Let's break this down:

General notes:  This is the order the DC801 badge sent the blocks, but in reality the order doesn't matter.

First off, Appearance. 4 total bytes, but the length byte doesn't count, so 03 bytes long.  Type is 0x19 to indicate this is a BLE Appearance block, then the Appearance ID of DC26.  If it was a DC25 badge, the ID would be DC19 - yeah, we changed it up a little

Next up, Flags.  The Flags mark what kind of advertisement this is.  With our flags of 06 we indicate we are general connectable and that we'll show up in bluetooth scans.  Open your phone and look for nearby devices - your DC801 badge will show up there.  We don't offer any actual services, so connecting to the badge is a bit of a honeypit to slow down people attempting to figure out the game protocol.

Next block, Manufacturer.  This block is a little special.  The first two bytes is the manufacturer ID, which is byte swapped 'on the wire' as it were: 0108 is 0801.  Some groups actually registered with the BLE group and got a real ID - check out Bender or Queercon.  We didn't get the paperwork done in time, so we used a fake ID that was not in use for 0801.  Now, there are some bytes that follow.  Those bytes can be any length (up to the 31 total, remember), and can mean anything you want them to mean.  In our case for Defcon 25:

0108 - DC801 is the manufacturer
8 bytes - which contains your score, your clan, and a checksum of your score with some bytes scrambled:
 - 0: Command to DCFurs badges - 0x35 indicates rabies infection
 - 1: Score byte 0
 - 2: Score byte 3
 - 3: CRC high byte
 - 4: Score byte 2
 - 5: CRC low byte
 - 6: Score byte 1
 - 7: Clan ID
 
The score can be as big as 32 bytes, unsigned.  I put it through a 'custom' CRC seeded with the polynum 0x0801 to verify that the score hasn't been tampered with - but I know someone is gonna figure that out, but I'm slowing you down a little.  Same for swapping up the bytes of the score.

However, bytes 1-6 are different if the badge is a 'god mode' badge sending a command - see [godmode.c](godmode.c) for more specific info, but we support these commands:

 - Sheep mode - user badge gets stuck in a loop showing sheep pictures
 - Party mode - user badge gets stuck showing an animated sheep and some LEDs
 - Score points - send the user badge some points, + or -
 - Score modifier - send the user a score percentage modifier
 - Beep - make the user badge beep

Last block is a type 09, which is the Long Name.  This part of the BLE stack will show up as the name if you scan for a device.  Again, it's 8 chars, always, padded with 00 if shorter.  Other badges didn't even look at this, it was just for showing up in bluetooth scans.  68616d7374657200 is ASCII 'hamster'.

How did you like it?  Let me know!  [@hamster](http://twitter.com/hamster)

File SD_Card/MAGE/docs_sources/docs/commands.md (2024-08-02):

---
tags: [ 'alias', 'aliases', 'register', 'unregister', 'command', 'verb', 'argument', 'arguments' ]
---

# Commands

Commands can be [registered](actions/REGISTER_SERIAL_DIALOG_COMMAND), after which the player can type the command into the serial [terminal](terminal) to run a script.

The first word is considered to be the command itself, a.k.a. the **verb**. Everything afterward is considered to be the command's **argument**. (You may register a script to be run in the event a command is attempted with an invalid argument.)

All custom command registrations are lost upon a map load.

## MGE Command Interpretation

- Words are split by whitespace when interpreted. The number of spaces does not matter. `GO      NORTH` is equivalent to `GO NORTH`.
- Case is ignored. `go north` is equivalent to `GO NORTH` (and `gO nOrTh`).
- The second word in a command is ignored if it is "AT" or "TO". `LOOK AT BOB` is equivalent to `LOOK BOB`
- Non-ASCII characters are not explicitly handled, so the MGE may interpret complex characters as one (or more) entirely different characters.

## Default Commands

These commands are built into the MGE.

Importantly, none of these default command words are reserved, so you may register custom arguments, e.g. `GO DENNIS` for a map without a "DENNIS" exit. Just know that these custom registrations will not appear in the list of exits provided by LOOK.

### Universal

- **HELP**: lists all commands that are currently registered, excluding:
    - Commands that have been [hidden](actions/SET_SERIAL_DIALOG_COMMAND_VISIBILITY)
    - Command aliases (e.g. `I` for `INVENTORY`)

### Per Map

A map's exits and script slots are defined in the map's [`maps.json` definition](mage_folder#maps-json).

- **LOOK**: runs the map's `on_look` script, and prints the names of exits associated with that map.
- **LOOK + entity's current name**: runs the script in that entity's `on_look` slot.
- **GO + name of one of the map's exits**: runs the script associated with that exit name.
    - Abbreviations of the cardinal directions are built into GO, so `GO N` will try to run `GO NORTH`. This also applies to the diagonals, e.g. `GO SW` for `GO SOUTHWEST`.

## Relevant actions

- [REGISTER_SERIAL_DIALOG_COMMAND](actions/REGISTER_SERIAL_DIALOG_COMMAND)
- [UNREGISTER_SERIAL_DIALOG_COMMAND](actions/UNREGISTER_SERIAL_DIALOG_COMMAND)
- [REGISTER_SERIAL_DIALOG_COMMAND_ARGUMENT](actions/REGISTER_SERIAL_DIALOG_COMMAND_ARGUMENT)
- [UNREGISTER_SERIAL_DIALOG_COMMAND_ARGUMENT](actions/UNREGISTER_SERIAL_DIALOG_COMMAND_ARGUMENT)
- [REGISTER_SERIAL_DIALOG_COMMAND_ALIAS](actions/REGISTER_SERIAL_DIALOG_COMMAND_ALIAS)
- [UNREGISTER_SERIAL_DIALOG_COMMAND_ALIAS](actions/UNREGISTER_SERIAL_DIALOG_COMMAND_ALIAS)
- [SET_SERIAL_DIALOG_COMMAND_VISIBILITY](actions/SET_SERIAL_DIALOG_COMMAND_VISIBILITY)

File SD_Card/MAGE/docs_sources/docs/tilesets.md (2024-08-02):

---
tags: [ 'dialog skins', 'dialogskins', 'transparent', 'colors', 'tiled', 'encoder', 'entity', 'entity_type', 'vertex', 'vertices', 'vector objects', 'pixels' ]
prev: 'mage_folder.md'
---

# Tilesets

A tileset is a series of images on a grid of uniform size used to modularly create larger images.

## Map Tilesets

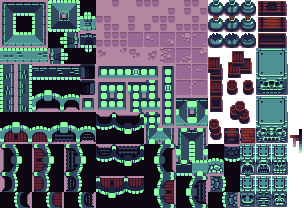
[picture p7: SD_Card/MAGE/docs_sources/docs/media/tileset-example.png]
example tileset


Map tilesets contain square blocks of terrain which can be used for building the [world](maps). There is no required structure for how the tiles should be arranged, but ordinarily, similar tiles are placed near each other. A map tileset is not expected to be animated.

All **tileset tiles need to be perfect squares** because tiles can be rotated or flipped on either axis when building maps.

## Spritesheets

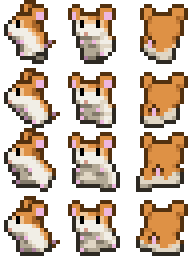
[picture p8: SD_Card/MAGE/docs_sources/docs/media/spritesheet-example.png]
example spritesheet


**Spritesheets** are tilesets that contain every iteration of a sprite needed for its animations.

Spritesheets are handled like tilesets within Tiled and the [encoder](encoder). They are not required to be square, strictly speaking, but non-square spritesheets currently (as of August 2024) crash the game when the tile goes partially offscreen, so best to keep everything square for now.

## Other Kinds of Tilesets

You'll need to make tilesets in Tiled for dialog box skin(s) and entity talk portraits, too.

Beyond making sure the tiles are the right size, you do not need to do anything special to these files.

Put dialogSkin files in `tilesets/` and entity portraits in `entities/`. (See: [`scenario_source_files`](mage_folder#scenario_source_files))

## MGE Considerations

### Tile Size

For tilesets and spritesheets, tiles **should not exceed 128x128 in size** or the game may not run on the badge hardware.

If you need to play animations larger than this, such as an animated logo on a menu screen, you can split the tile into several pieces and place them on a map in such a way that they appear to be a single unit. (This may work poorly for entities that need to move around on their own, however.)

### Transparency

**You cannot have partially transparent pixels**. Semi-transparent pixels are assigned by the encoder to be either fully opaque or fully transparent at a 50% threshold.

To encode alpha, the MGE repurposes the least-significant green bit in the RGB565 color encoding scheme. Because of this, the color 0x0200 (hex #004000, or rgb 0,64,0) will actually manifest as transparent within the MGE. Avoid using this color (or any color that becomes 0x0200 when converted to RGB565).

### Pallet

The [encoder](encoder) indexes the pallets of each image, and there is therefore a **maximum of 255 colors per tileset image** (excluding transparency, which is always included, making it 256 colors total). The encoder will let you know if one of your tilesets is over the color limit.

::: tip
If you're having trouble keeping your pallets under control, consider using the PNG-8 and GIF file formats, as they cannot contain more than 256 colors. Just remember that at least one of these colors must be transparent!
:::

If you need extra colors, consider splitting the tileset into multiple files — maps will quite happily use tiles from multiple tilesets with no trouble, provided the tiles are of uniform size.

::: tip Best Practice
On embedded, pixel data is streamed from the ROM chip, but the tileset pallets must be held in RAM. Because RAM is very, very precious, **please combine tilesets if there isn't a compelling reason to keep them in separate files**. Entity sprite sheets are typically kept separate, for instance, but you might combine spritesheets for similar entities, or combine all character entity portraits. (And naturally, tilesets with differing tile sizes must be separate!)
:::

### Updating Tileset Images on the Fly

When you save changes to an image that Tiled is actively using, including changing its dimensions, the graphical changes are instantly reflected in all maps, tilesets, etc. within Tiled. This way, you can rapidly iterate on how something looks.

However, changes in image dimensions are *not* automatically perpetuated to the tileset's declared properties, and since the [encoder](encoder) relies on those values to determine the tileset's size, this will cause problems: for tiles past the tileset's declared bounds, the pixel data will behave correctly, but random [tile collisions](tilesets#tile-collisions) will be applied.

**Solution**: Make any change whatsoever to the tileset inside of Tiled to have it recalculate those properties, then save. Alternatively, change the numbers yourself in a text editor.

## Creating a Tileset JSON File

The [encoder](encoder) cannot use image files outright — there must be an associated JSON file (made with Tiled) that explicitly defines the image file path and various other properties.

Within Tiled:

1. Go to "File > New Tileset…"
2. Name the file. Prefix the name with `tileset-` or `entity-` as appropriate.
3. For "source," use the file explorer to choose the sprite sheet or tileset you want to use. (Please make sure the image file is in its final destination ahead of time. Moving it after assigning it can be a bit of a hassle.)
4. Set the tile width and height to the tile size of your image.
5. Save the tileset file:
	- Set the format to JSON.
	- Set the correct destination folder: `scenario_source_files/entities/` for entities and their portraits, and `scenario_source_files/tilesets/` for everything else. (Keep in mind that Tiled will default to the file path of the last file currently open!)

**Alternative method (advanced)**: if you are making pallet variations of the same sprite, and every other aspect (apart from the name and the image) are the same, you might copy the original tileset JSON file and manually change whatever is different between them.

### For Character Entities

All tiles within a [character entity](entity_types#character-entity) tileset must have the `Class` (formerly `Type`) property set to its `entity_type` name. You can find the "Class" property in the Properties view (i.e. panel/pane/frame), which you can make visible (if currently invisible) via "View > View and Toolbars > Properties."

::: tip
You can skip this part if you don't need the entity to be a character entity — if you want to leave it as an animation entity, such as a flickering candle or waving grass, it doesn't need to have an `entity_type` name at all.

See: [Entity Types](entity_types)
:::

### Tile Collisions

[Map](maps) [tilesets](tilesets) should have collision polygons set for each relevant tile. This is done by selecting a tile and clicking the collision editor within Tiled:

the second icon is a pair of polygons

For the MGE, each tile can have only one vector shape, and each vertex must fall within the bounds of the tile itself. (Vertices falling outside the tile will cause erratic collision behavior.)

It's helpful to turn on pixel snapping before drawing collision polygons ("View > Snapping > Snap to Pixels").

::: tip Best Practices
Precise collision shapes are possible, but avoid very concave shapes and avoid diagonals for tiles that are expected to be placed adjacent to other tiles with collision.

When defining your collision polygons and designing your maps, test the tiles in their map contexts and determine whether the player character is able to push themselves inside one of these shapes.
:::

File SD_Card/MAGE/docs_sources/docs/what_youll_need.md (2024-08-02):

---
tags: [ 'VSCode', 'VS Code', 'Visual Studio Code', 'word processor', 'mac', 'windows', 'aseprite', 'opengameart.org', 'json', 'sublime merge', 'jetbrains' ]
---

# What You'll Need

The MGE is data driven, meaning you won't need special hardware or a compiler to generate game content for your Black Mage Badge. All you'll need are:

## Text Editor

You will need a text editor. (NOTE: a word processor like Apple's Pages or Microsoft Word will not suffice!)

What will work best is an IDE with project management features like syntax parsing and Git integration. Our recommendation, especially for beginners, is [Visual Studio Code](https://code.visualstudio.com/) (Mac, Linux, or Windows), which is free and open source. Importantly, we have prepared a VSCode Marketplace plugin for [MGS Natlang](mgs/mgs_natlang) [syntax highlighting](mgs/mgs_natlang#syntax-colors), which will make it much easier to work with MGS game script files.

`.mgs` syntax highlighting can be manually added to a handful of other text editors, too. (See [Syntax Colors](mgs/mgs_natlang#syntax-colors) for up-to-date details and instructions.) The following can manage decent support as of August 2024:

- [Sublime Text](https://sublimetext.com)
- [JetBrains' IDEs](https://www.jetbrains.com/) (excellent IDE but not inexpensive)
- [TextMate](https://macromates.com) (Mac only)

## Graphics Editor

Any graphics program capable of pixel art can be used to make sprite sheets or [tilesets](tilesets). But if you need custom [animation](animations), we recommend investing in [Aseprite](https://www.aseprite.org/), which is about $20. It specializes in sprite animations, and it makes previewing animations and exporting sprite sheets quite painless.

If you don't want to make art from scratch, a good source of premade tilesets is [OpenGameArt.org](https://OpenGameArt.org).

## Tiled

Tiled, which can be found at [mapeditor.org](https://www.mapeditor.org), is a free, cross-platform map and [tileset](tilesets) editor that can export and edit JSON files. This how the bulk of [maps](maps), [tilesets](tilesets), [entity](entities) [animations](animations), [tile collisions](tilesets#tile-collisions), and [geometry](vector_objects) for [choreography](techniques/cutscenes) are defined.

::: warning Use Tiled 1.9.2!
Newer versions of Tiled use a slightly different file structure that is not compatible with the current [encoder](encoder)! Please make sure to download version 1.9.2 specifically. Get it from their [Github releases](https://github.com/mapeditor/tiled/releases/tag/v1.9.2).
:::

## Git

~~While strictly optional, it's always nice to version control your projects,~~ If you are not using Git to version control your projects, you bring dishonor and suffering on your house, especially if working with multiple people. We recommend [Sublime Merge](https://www.sublimemerge.com/) if you're just getting started with Git, particularly if you're using VSCode, as VSCode's version control interface is limited. If you're already using one of [JetBrains' IDEs](https://www.jetbrains.com/), you can use their excellent built-in Git tools.

## Web Browser

The [web encoder](encoder#web-encoder) can be run with Node.js (see below) or in a web browser. They will both take the game files from your [`scenario_source_files`](mage_folder#scenario_source_files) folder and export a `game.dat` for the Mage Game Engine to use.

The web version of the encoder, however, also has an [entity management system](entity_management_system) for managing animation assignments, so while you might use the Node encoder most of the time, chances are you'll still want to use the web version regularly.

You will likely also want to use the [web build](web_build) of the MGE to test your game data, as this is much simpler than setting up a Linux environment to run the game natively and much faster than using a microSD card to test the `game.dat` on the real badge after every revision.

## Node.js (optional)

If you find yourself constantly making small changes to your content and regenerating your `game.dat` very frequently, it may be worthwhile to install [Node.js](https://nodejs.org) so you can use the [CLI version of the encoder](encoder#cli-encoder) instead.

We recommend using Node's long-term support (i.e. even numbered) versions.

## MicroSD Card (optional)

To put a new `game.dat` onto the badge, you'll need a microSD card formatted to FAT32. (This is only necessary if you're using the real badge hardware; the [web build](web_build) is sufficient for most cases.)

## Linux (optional)

The tools listed above can be run in any environment, but at the moment (August 2024), you need Linux to run the game natively on your computer.

A virtual machine will be sufficient for this. For your convenience, we have prepared a VM image with project files and tooling in place for you to start a new MGE project (see: [MGE VM](mge_vm)) — but know that you will likely need to update everything, as the VM was prepared for the chapter 1 engine.

## `MAGE/` Folder

Content creation will involve creating, modifying, and using files within the `MAGE` folder (inside the `SD_Card` folder, inside the project repo). See: [`MAGE` Folder](mage_folder)

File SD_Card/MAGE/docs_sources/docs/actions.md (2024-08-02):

---
prev: script_slots.md
---

# Actions

**Actions** are a basic element of the Mage Game Engine (MGE).

Actions are individual units of script behavior, such as a logic check or state management, given one after the other within a single [script](scripts). They each have predefined arguments, and their names are written in "SCREAMING_SNAKE_CASE." In the final encoded data, they are 8 bytes apiece.

Through [MGS Natlang](mgs/mgs_natlang), they can be written as one or more "natural language" patterns.

## Game Management

Handle the general state of the game, such as [loading maps](map_loads), timing game actions, enabling and disabling player input, and managing save states.

- [BLOCKING_DELAY](actions/BLOCKING_DELAY)
- [NON_BLOCKING_DELAY](actions/NON_BLOCKING_DELAY)
- [SET_PLAYER_CONTROL](actions/SET_PLAYER_CONTROL)
- [LOAD_MAP](actions/LOAD_MAP)
- [SLOT_SAVE](actions/SLOT_SAVE)
- [SLOT_LOAD](actions/SLOT_LOAD)
- [SLOT_ERASE](actions/SLOT_ERASE)
- [SHOW_DIALOG](actions/SHOW_DIALOG)
- [CLOSE_DIALOG](actions/CLOSE_DIALOG)
- [SET_LIGHTS_CONTROL](actions/SET_LIGHTS_CONTROL)
- [SET_LIGHTS_STATE](actions/SET_LIGHTS_STATE)

## Hex Editor

Enable or disable player control of specific game features, and otherwise manage the hex editor state.

- [SET_HEX_EDITOR_STATE](actions/SET_HEX_EDITOR_STATE)
- [SET_HEX_EDITOR_DIALOG_MODE](actions/SET_HEX_EDITOR_DIALOG_MODE)
- [SET_HEX_EDITOR_CONTROL](actions/SET_HEX_EDITOR_CONTROL)
- [SET_HEX_EDITOR_CONTROL_CLIPBOARD](actions/SET_HEX_EDITOR_CONTROL_CLIPBOARD)

## Serial Console

Manage serial features and create serial output.

- [SET_SERIAL_DIALOG_CONTROL](actions/SET_SERIAL_DIALOG_CONTROL)
- [SHOW_SERIAL_DIALOG](actions/SHOW_SERIAL_DIALOG)
- [CLOSE_SERIAL_DIALOG](actions/CLOSE_SERIAL_DIALOG)
- [SET_CONNECT_SERIAL_DIALOG](actions/SET_CONNECT_SERIAL_DIALOG)
- [REGISTER_SERIAL_DIALOG_COMMAND](actions/REGISTER_SERIAL_DIALOG_COMMAND)
- [UNREGISTER_SERIAL_DIALOG_COMMAND](actions/UNREGISTER_SERIAL_DIALOG_COMMAND)
- [REGISTER_SERIAL_DIALOG_COMMAND_ARGUMENT](actions/REGISTER_SERIAL_DIALOG_COMMAND_ARGUMENT)
- [UNREGISTER_SERIAL_DIALOG_COMMAND_ARGUMENT](actions/UNREGISTER_SERIAL_DIALOG_COMMAND_ARGUMENT)
- [SET_SERIAL_DIALOG_COMMAND_VISIBILITY](actions/SET_SERIAL_DIALOG_COMMAND_VISIBILITY)
- [REGISTER_SERIAL_DIALOG_COMMAND_ALIAS](actions/REGISTER_SERIAL_DIALOG_COMMAND_ALIAS)
- [UNREGISTER_SERIAL_DIALOG_COMMAND_ALIAS](actions/UNREGISTER_SERIAL_DIALOG_COMMAND_ALIAS)

## Camera Control

Manipulate the camera's position or perform tricks like shaking the camera or fading the screen in and out to an arbitrary color.

- [SET_CAMERA_TO_FOLLOW_ENTITY](actions/SET_CAMERA_TO_FOLLOW_ENTITY)
- [TELEPORT_CAMERA_TO_GEOMETRY](actions/TELEPORT_CAMERA_TO_GEOMETRY)
- [PAN_CAMERA_TO_ENTITY](actions/PAN_CAMERA_TO_ENTITY)
- [PAN_CAMERA_TO_GEOMETRY](actions/PAN_CAMERA_TO_GEOMETRY)
- [PAN_CAMERA_ALONG_GEOMETRY](actions/PAN_CAMERA_ALONG_GEOMETRY)
- [LOOP_CAMERA_ALONG_GEOMETRY](actions/LOOP_CAMERA_ALONG_GEOMETRY)
- [SET_SCREEN_SHAKE](actions/SET_SCREEN_SHAKE)
- [SCREEN_FADE_OUT](actions/SCREEN_FADE_OUT)
- [SCREEN_FADE_IN](actions/SCREEN_FADE_IN)

## Script Control

Set a specific [`on_tick`](script_slots#on-tick) or [`on_interact`](script_slots#on-interact) script, run another script, or recursively copy the actions inside another script.

- [RUN_SCRIPT](actions/RUN_SCRIPT)
- [GOTO_ACTION_INDEX](actions/GOTO_ACTION_INDEX)
- [COPY_SCRIPT](actions/COPY_SCRIPT)
- [SET_MAP_TICK_SCRIPT](actions/SET_MAP_TICK_SCRIPT)
- [SET_ENTITY_INTERACT_SCRIPT](actions/SET_ENTITY_INTERACT_SCRIPT)
- [SET_ENTITY_TICK_SCRIPT](actions/SET_ENTITY_TICK_SCRIPT)
- [SET_ENTITY_LOOK_SCRIPT](actions/SET_ENTITY_LOOK_SCRIPT)
- [SET_SCRIPT_PAUSE](actions/SET_SCRIPT_PAUSE)

## Entity Choreography

Move entities around the map using [vector objects](vector_objects) placed with Tiled.

NOTE: These actions can behave erratically if any of the vertices in the geometry object are subject to coordinate underflow.

- [SET_ENTITY_PATH](actions/SET_ENTITY_PATH)
- [TELEPORT_ENTITY_TO_GEOMETRY](actions/TELEPORT_ENTITY_TO_GEOMETRY)
- [WALK_ENTITY_TO_GEOMETRY](actions/WALK_ENTITY_TO_GEOMETRY)
- [WALK_ENTITY_ALONG_GEOMETRY](actions/WALK_ENTITY_ALONG_GEOMETRY)
- [LOOP_ENTITY_ALONG_GEOMETRY](actions/LOOP_ENTITY_ALONG_GEOMETRY)

## Entity Appearance

Many of these actions (the ones that don't have an explicit duration) will happen instantly. Therefore, if several are used back-to-back, they will all resolve on the same frame. If this is not intended behavior, you should pad them with [non-blocking delay](actions/NON_BLOCKING_DELAY).

- [PLAY_ENTITY_ANIMATION](actions/PLAY_ENTITY_ANIMATION)
- [SET_ENTITY_CURRENT_ANIMATION](actions/SET_ENTITY_CURRENT_ANIMATION)
- [SET_ENTITY_CURRENT_FRAME](actions/SET_ENTITY_CURRENT_FRAME)
- [SET_ENTITY_DIRECTION](actions/SET_ENTITY_DIRECTION)
- [SET_ENTITY_DIRECTION_RELATIVE](actions/SET_ENTITY_DIRECTION_RELATIVE)
- [SET_ENTITY_DIRECTION_TARGET_ENTITY](actions/SET_ENTITY_DIRECTION_TARGET_ENTITY)
- [SET_ENTITY_DIRECTION_TARGET_GEOMETRY](actions/SET_ENTITY_DIRECTION_TARGET_GEOMETRY)
- [SET_ENTITY_MOVEMENT_RELATIVE](actions/SET_ENTITY_MOVEMENT_RELATIVE)
- [SET_ENTITY_GLITCHED](actions/SET_ENTITY_GLITCHED)

## Set Entity Properties

Set a specific property on a specific [entity](entities).

- [SET_ENTITY_NAME](actions/SET_ENTITY_NAME)
- [SET_ENTITY_X](actions/SET_ENTITY_X)
- [SET_ENTITY_Y](actions/SET_ENTITY_Y)
- [SET_ENTITY_TYPE](actions/SET_ENTITY_TYPE)
- [SET_ENTITY_PRIMARY_ID](actions/SET_ENTITY_PRIMARY_ID)
- [SET_ENTITY_SECONDARY_ID](actions/SET_ENTITY_SECONDARY_ID)
- [SET_ENTITY_PRIMARY_ID_TYPE](actions/SET_ENTITY_PRIMARY_ID_TYPE)

## Set Variables

Manipulate MGE variables or set them to an arbitrary value.

- [SET_SAVE_FLAG](actions/SET_SAVE_FLAG)
- [SET_WARP_STATE](actions/SET_WARP_STATE)
- [MUTATE_VARIABLE](actions/MUTATE_VARIABLE)
- [MUTATE_VARIABLES](actions/MUTATE_VARIABLES)
- [COPY_VARIABLE](actions/COPY_VARIABLE)

## Check Entity Properties

These actions check whether one of an [entity](entities)'s [properties](entity_properties) matches a specific state. If the condition is met (or not met), then the script will jump: either to a specific point in the same script or the top of an entirely different script.

You can use [`%SELF%`](relative_references#self) to target the entity running the script and [`%PLAYER%`](relative_references#player) to target the player entity. Otherwise, you must use the entity's given name (its name in Tiled).

You can use the condition portion of these following actions with [if and else](mgs/advanced_syntax#if-and-else).

- [CHECK_ENTITY_NAME](actions/CHECK_ENTITY_NAME)
- [CHECK_ENTITY_X](actions/CHECK_ENTITY_X)
- [CHECK_ENTITY_Y](actions/CHECK_ENTITY_Y)
- [CHECK_ENTITY_INTERACT_SCRIPT](actions/CHECK_ENTITY_INTERACT_SCRIPT)
- [CHECK_ENTITY_TICK_SCRIPT](actions/CHECK_ENTITY_TICK_SCRIPT)
- [CHECK_ENTITY_LOOK_SCRIPT](actions/CHECK_ENTITY_LOOK_SCRIPT)
- [CHECK_ENTITY_TYPE](actions/CHECK_ENTITY_TYPE)
- [CHECK_ENTITY_PRIMARY_ID](actions/CHECK_ENTITY_PRIMARY_ID)
- [CHECK_ENTITY_SECONDARY_ID](actions/CHECK_ENTITY_SECONDARY_ID)
- [CHECK_ENTITY_PRIMARY_ID_TYPE](actions/CHECK_ENTITY_PRIMARY_ID_TYPE)
- [CHECK_ENTITY_CURRENT_ANIMATION](actions/CHECK_ENTITY_CURRENT_ANIMATION)
- [CHECK_ENTITY_CURRENT_FRAME](actions/CHECK_ENTITY_CURRENT_FRAME)
- [CHECK_ENTITY_DIRECTION](actions/CHECK_ENTITY_DIRECTION)
- [CHECK_ENTITY_GLITCHED](actions/CHECK_ENTITY_GLITCHED)
- [CHECK_ENTITY_PATH](actions/CHECK_ENTITY_PATH)
- [CHECK_IF_ENTITY_IS_IN_GEOMETRY](actions/CHECK_IF_ENTITY_IS_IN_GEOMETRY)

## Check Variables

Check whether one of the MGE variables matches a specific value. If the condition is met (or not met), then the script will jump: either to a specific point in the same script or the top of an entirely different script.

You can use the condition portion of these following actions with [if and else](mgs/advanced_syntax#if-and-else).

- [CHECK_VARIABLE](actions/CHECK_VARIABLE)
- [CHECK_VARIABLES](actions/CHECK_VARIABLES)
- [CHECK_SAVE_FLAG](actions/CHECK_SAVE_FLAG)
- [CHECK_FOR_BUTTON_PRESS](actions/CHECK_FOR_BUTTON_PRESS)
- [CHECK_FOR_BUTTON_STATE](actions/CHECK_FOR_BUTTON_STATE)
- [CHECK_WARP_STATE](actions/CHECK_WARP_STATE)
- [CHECK_DIALOG_OPEN](actions/CHECK_DIALOG_OPEN)
- [CHECK_SERIAL_DIALOG_OPEN](actions/CHECK_SERIAL_DIALOG_OPEN)
- [CHECK_DEBUG_MODE](actions/CHECK_DEBUG_MODE)

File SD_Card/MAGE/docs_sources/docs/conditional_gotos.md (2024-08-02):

---
next: mgs/mgs_natlang.md
---

# Conditional Gotos

Consists of actions from the check [entity properties](entity_properties) and check [variables](variables) categories. The "conditions" portion of each of those [actions](actions) can be inserted into any of the following patterns:

1. [Zigzag](#zigzag-if--else) macro: `if ( ... ) { }`
	- NOTE: This expands to the label jump pattern automatically.
2. Script jump version: `if ... then goto (script) _`
3. Label jump version: `if ... then goto label _`
	- This pattern is to be used with bareword [labels](#labels).
4. Index jump version: `if ... then goto index _`
	- Refers to the target action by the absolute index within the script.
	- This is not recommended for scripts written by hand, as `COPY_SCRIPT` and automatic syntax expansion may result in an unexpected number of actions in your scripts.

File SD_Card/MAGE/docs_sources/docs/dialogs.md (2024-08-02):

---
tags: [ 'mgs natlang', 'dialog names', 'actions', 'SHOW_DIALOG', 'BOTTOM_LEFT', 'BOTTOM_RIGHT', 'TOP_LEFT', 'TOP_RIGHT', 'player', 'self', 'given name', 'current name', 'character entity', 'encoder', 'portrait.json', 'text wrap', ]
---

# Dialogs

Dialogs are a visual novel or RPG style dialog system for the screen. These include portrait images, dialog box labels, and dialog messages.

Dialogs do nothing on their own. To show them, you must use the [SHOW_DIALOG](actions/SHOW_DIALOG) action within a [script](scripts).

[Scripts](scripts) running a dialog cannot simultaneously perform other [actions](actions). If an [entity](entities) must change their behavior partway through a dialog, you must split the dialog into multiple pieces and insert those actions between the pieces, or use another [script slot](script_slots) to control the entity's behavior.

Dialog names must be unique throughout the entire game project. (Dialogs written with [MGS Natlang](mgs/mgs_natlang) need not be named; their names are auto generated based on the file and line number when not defined.)

## Properties

Dialogs must, at bare minimum, have `messages`. If no `name` or `entity` is provided (or if the `name` is set to an empty string `""`), no dialog box label will appear.

### `alignment`

`alignment` controls the position of the dialog box and its portrait/label boxes. Valid choices:

- `BOTTOM_LEFT`
- `BOTTOM_RIGHT`
- `TOP_LEFT`
- `TOP_RIGHT`

In [MGS Natlang](mgs/mgs_natlang), these can be abbreviated to `BL`, `TR`, etc.

[MGS Natlang](mgs/mgs_natlang) will use `BOTTOM_LEFT` if this property is not provided. A default can also be set for each MGS file individually using `settings for dialog {}`, or in multiple files when combined with `include!()`.

::: tip Black Mage Game Usage
For the Black Mage Game, dialog alignment should be `BOTTOM_RIGHT` for the player character, and `BOTTOM_LEFT` for everything else. `TOP_LEFT` and `TOP_RIGHT` are only used when an entity is positioned in such a way that it would most likely be obscured by the dialog box itself.

Put `include!("header.mgs")` at the top of new `.mgs` files to include these and other default project settings.
:::

### `entity`

Optional. `entity` refers to a specific entity by its **given name** (the name it was given within Tiled). This is technically optional, but you will almost certainly want to include it.

This property can be any of the following:

1. [`%PLAYER%`](relative_references#player), which refers to the player entity
2. [`%SELF%`](relative_references#self), which refers to the entity running the script
3. the **given name** of an entity (no percent signs)

The MGE will use the referenced entity's [current name](variables#printing-current-values) for the dialog label automatically.

For the `entity` property, you must not use percent signs to refer to entities, or the [encoder](encoder) will give you a message in the vein of `No entity named %Helga% found on map default!` If you don't want to use an entity's [current name](variables#printing-current-values) in the dialog label, you must use the `name` property, which can print a string literally.

If the referenced entity is a [character entity](entity_types#character-entity), the [encoder](encoder) will use [`entity_types.json`](mage_folder#entity_types-json) to automatically determine the portrait image.

### `name`

Optional. `name` provides a string for dialog box label, and if included, it will override any names inherited from `entity` above.

This property can be any of the following:

1. [`%PLAYER%`](relative_references#player), which refers to the player entity
2. [`%SELF%`](relative_references#self), which refers to the entity running the script
3. an arbitrary ASCII string up to 12 characters long
4. the **given name** of an entity, but enclosed in percent signs: `%Entity Name%`

If you use the entity's given name without percent signs, it will behave as a static string #3. This will appear to behave the same as #4 in most cases, but #4 will allow inherited dialog labels to reflect the [entity's name as it currently exists in RAM](variables#printing-current-values) and not the name it was originally assigned.

### `portrait`

Optional.  This is the name of the portrait defined in [`portraits.json`](mage_folder#portraits-json) you want to use for the dialog. This will override any portraits inherited from `entity` above.

If the dialog cannot find a portrait to use (either via `portrait` or `entity`), then the dialog will display no portrait box.

### `border_tileset`

Optional. This is name of the dialog box tileset you want the dialog box to use, if not the default. (Default is the first border tileset listed in [`scenario.json`](mage_folder#scenario-json).) (Or is it the one named "default"? #researchme)

### `emote`

Optional. Allows you to select a specific emote within the entity's entry in [`portraits.json`](mage_folder#portraits-json). The default emote (`0`) will display if not specified. (While emotes can have assigned names, you must use integers to control them here.)
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

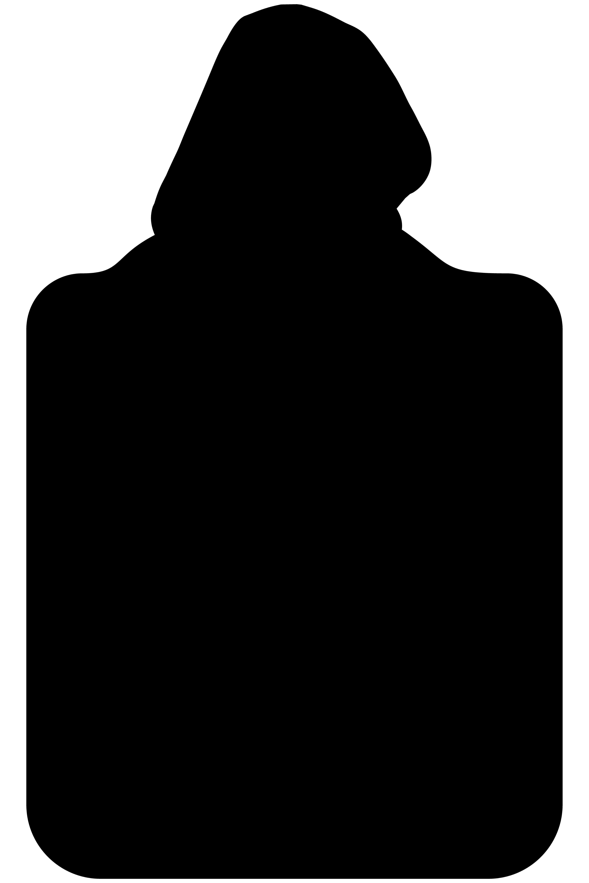
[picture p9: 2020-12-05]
Hardware/BackBoard/images/back-board_Outline.png

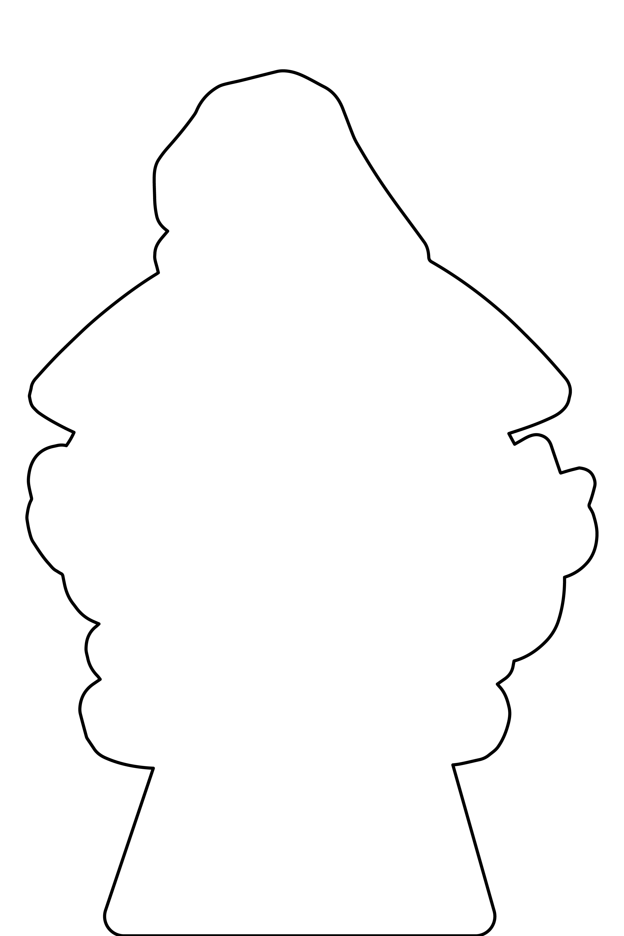
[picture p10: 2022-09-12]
Hardware/SAOs/2022 MiniMage/images/SAO-2022_spells_1_Outline.png

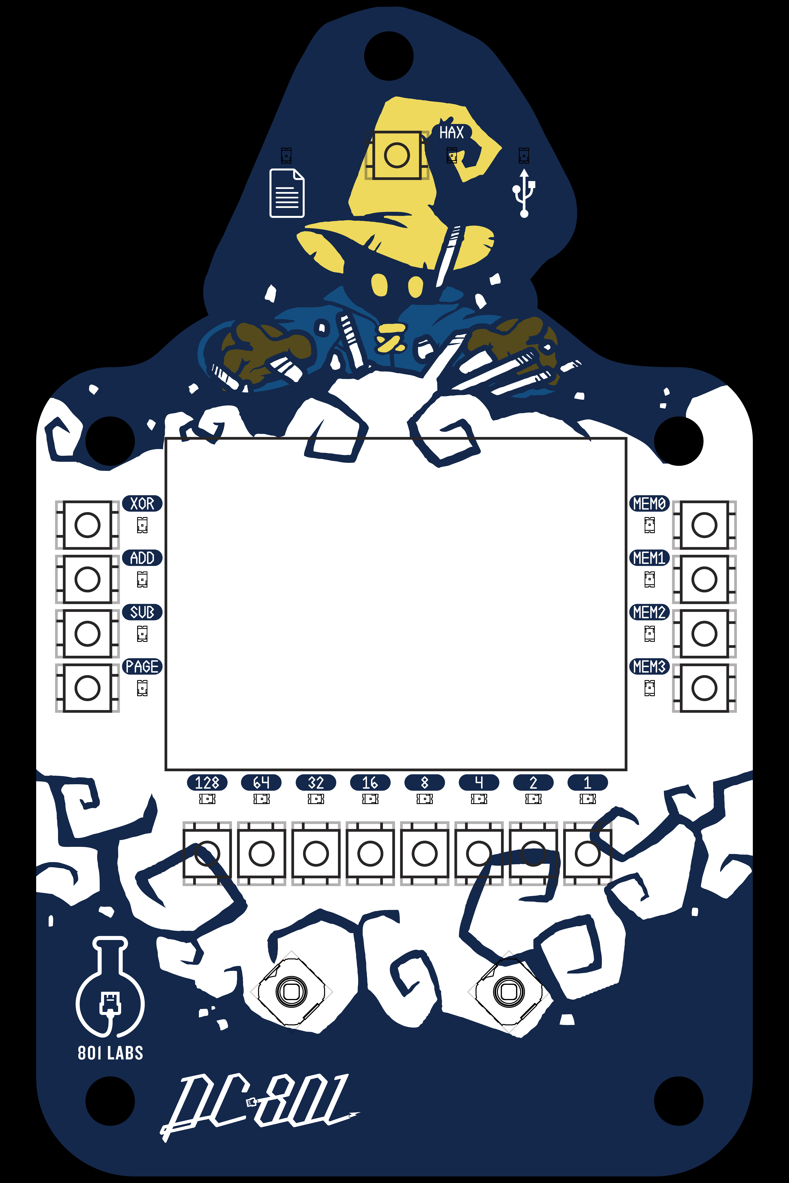
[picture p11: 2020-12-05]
Hardware/BackBoard/images/back-board-01.png

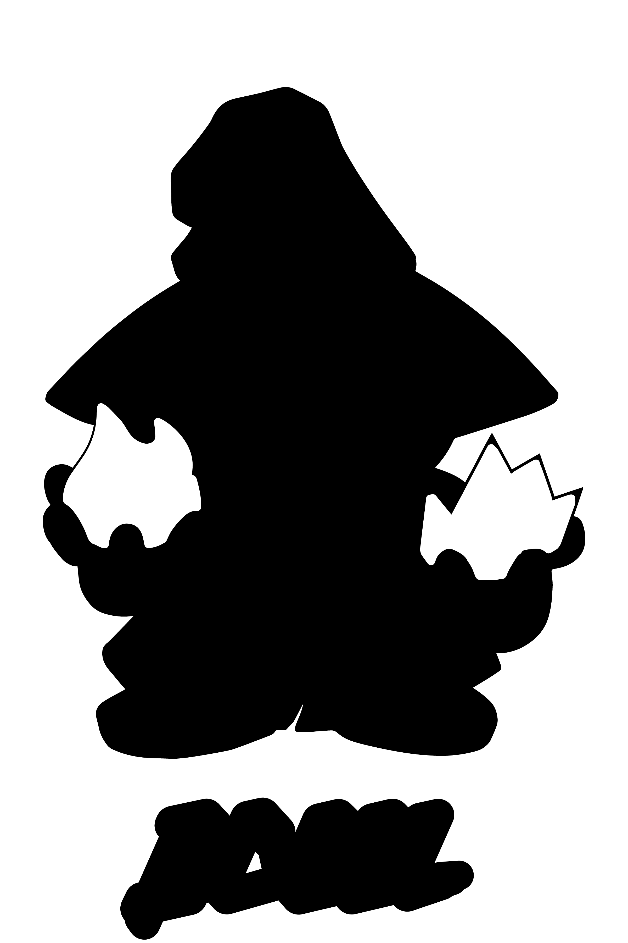
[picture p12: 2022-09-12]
Hardware/SAOs/2022 MiniMage/images/SAO-2022_spells_1_Back Copper.png

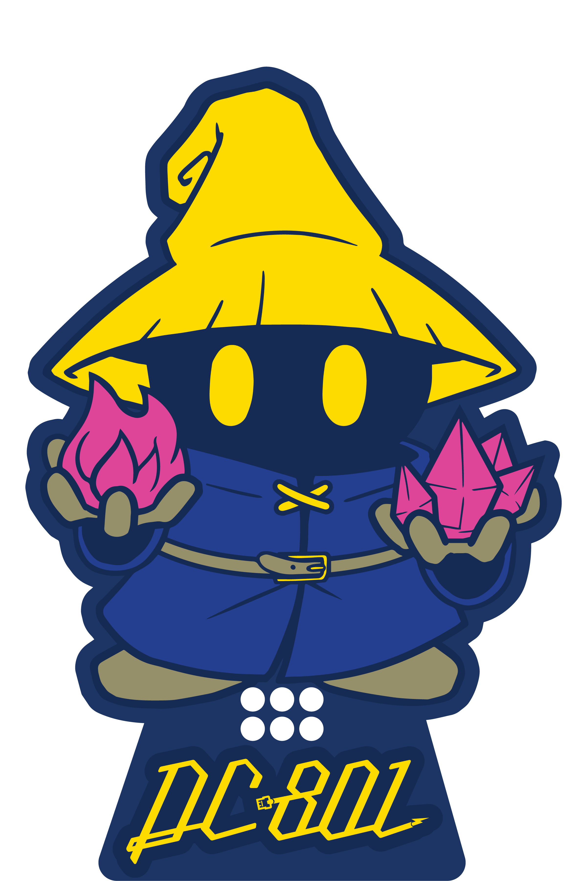
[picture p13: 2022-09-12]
Hardware/SAOs/2022 MiniMage/images/SAO-2022_spells_1-01.png

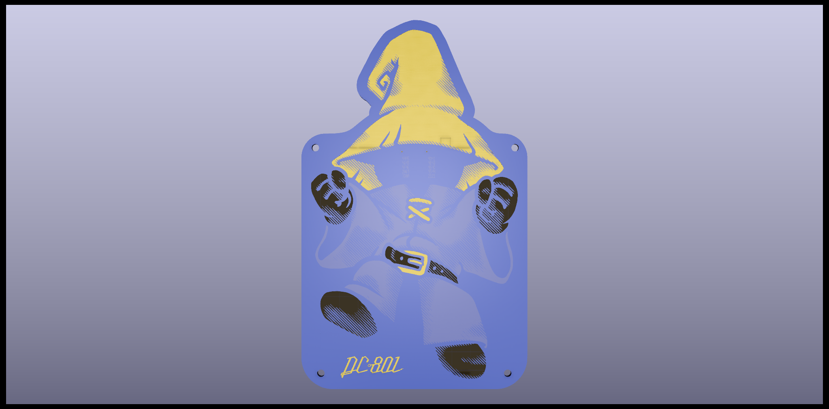
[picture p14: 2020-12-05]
Hardware/ART/2020/images/ART-2020-front.png

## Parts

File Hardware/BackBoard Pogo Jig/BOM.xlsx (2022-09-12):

Ref Des | Description | Mfg Part # | Package | Supplier | Supplier Part # | QTY per badge | Cost ea | Cost badge
C1,C14,C25 | 0.1uF Cap |  | 0603 | Digikey | 478-06036C104KAT4ACT-ND | 3 | 0.0178 | 0.0534
C10,C11 | 47pF Cap |  | 0603 | Digikey | 732-7750-1-ND | 2 | 0.0232 | 0.0464
C26 | 10uF cap |  | 0603 | Digikey | 587-6017-1-ND | 1 | 0.0644 | 0.0644
D1,D2 | Schottky diode | VS-10MQ040-M3/5AT |  | Digikey | 112-VS-10MQ040-M3/5ATDKR-ND | 2 | 0.12972 | 0.25944
D3,D5 | LEDs |  | 0603 | Digikey | 160-1435-1-ND | 2 | 0.0846 | 0.1692
D4 | TVS Diode | SP0503BAHTG | SOT-143-4 | Digikey | F2715DKR-ND | 1 | 0.4622 | 0.4622
DNS | 2.4" TFT 320x240 LCD display |  |  | buydisplay | https://www.buydisplay.com/color-2-4-inch-tft-lcd-module-display-touch-panel-240x320-dot-serial-spi | 1 | 4.82 | 4.82
J15 | USB-C | 1054500101 |  | Digikey | WM12856CT-ND | 1 | 1.8718 | 1.8718
J16 | FPC connector | 62684-50210E9ALF | Top Contact, 50 pin | Digikey | 609-5388-1-ND | 1 | 0.8245 | 0.8245
R12 | 10k Resistor |  | 0603 | Digikey | RMCF0603JT10K0CT-ND | 2 | 0.0056 | 0.0112
R10,R11 | 5.1k Resistor |  | 0603 | Digikey | RMCF0603JG5K10CT-ND | 2 |  | 0
R13 | 33R Resistor |  |  | Digikey | RMCF0603JT33R0CT-ND | 1 | 0.0056 | 0.0056
R1,R2 | 470R Resistor |  | 0603 | Digikey | RMCF0603JT470RCT-ND | 2 | 0.0056 | 0.0112
R7,R8 | 27R Resistor |  | 0603 | Digikey | RMCF0603JT27R0CT-ND | 2 | 0.0056 | 0.0112
SW1 | Power switch | JS102011SAQN |  | Digikey | 401-1999-1-ND | 1 | 0.50908 | 0.50908
J1, J19, J2, J22, J23, J24, J28, J29, J3, J30, J31, J32, J33, J34, J35, J4, J5, J6, J8 | Pogo Socket |  |  | Digikey | ED1012-ND | 19 | 0.39 | 7.41
U1 | USB to serial | FT230XS | 16SSOP | Digikey | 768-1135-1-ND | 1 | 2.04 | 2.04
 |  |  |  |  |  | Total Parts |  | Cost Per
 |  |  |  |  |  | 39 |  | 18.46982

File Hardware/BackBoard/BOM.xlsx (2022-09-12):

Ref Des | Description | Mfg Part # | Package | Supplier | Supplier Part # | QTY per badge | Cost ea | Cost badge | Total Needed | Total Cost | Qty to PCBX |  |  |  | QOH | Needed | 300 | To order | Cost
C1,C13,C14,C15,C17,C20,C23,C24,C25 | 0.1uF Cap |  | 0603 | Digikey | 478-06036C104KAT4ADKR-ND | 9 | 0.0178 | 0.1602 | 2790 | 49.662 | 5000 | 44.95 |  |  | 0 | 2700
 |  |  |  |  | 478-06036C104JAT2ADKR-ND | 9 | 0.01455 | 0.13095 | 2790 | 40.5945 |  |  |  |  |  |  |  | 4000 | 40.88
C10,C11 | 47pF Cap |  | 0603 | Digikey | 732-7750-6-ND | 2 | 0.0232 | 0.0464 | 620 | 14.384 | 1000 | 27.52 |  |  | 0 | 600 |  | 1000 | 29
C16,C18,C21,C22 | 0.47uF Cap |  | 0603 | Digikey | 1292-1453-6-ND | 4 | 0.032 | 0.128 | 1240 | 39.68 | 1500 | 31.51 |  |  | 0 | 1200 |  | 1500 | 29.51
C19 | 22uF Cap |  | 0603 | Digikey | 490-10476-6-ND | 1 | 0.1279 | 0.1279 | 310 | 39.649 | 500 | 48.05 |  |  | 0 | 300 |  | 500 | 36.54
C2,C4,C5,C8,C9,C12 | 4.7uF Cap |  | 0603 | Digikey | 1276-1045-6-ND | 6 | 0.0203 | 0.1218 | 1860 | 37.758 | 2000 | 28.12 |  |  | 0 | 1800 |  | 4000 | 32.72
C3,C26 | 10uF cap |  | 0603 | Digikey | 587-6017-6-ND | 2 | 0.0644 | 0.1288 | 620 | 39.928 | 1000 | 45.88 |  |  | 0 | 600 |  | 1000 | 42.7
C6 | 22uF cap |  | 0805 | Digikey | 1276-6780-6-ND | 1 | 0.1476 | 0.1476 | 310 | 45.756 | 500 | 57.44 |  |  | 0 | 300 |  | 500 | 50.89
C7 | 1nF Capacitor |  | 0603 | Digikey | 1292-1381-6-ND | 1 | 0.0128 | 0.0128 | 310 | 3.968 | 1000 | 13.53 |  |  | 0 | 300 |  | 4000 | 20.44
D1,D2 | Schottky diode | VS-10MQ040-M3/5AT |  | Digikey | 112-VS-10MQ040-M3/5ATDKR-ND | 2 | 0.12972 | 0.25944 | 620 | 80.4264 | 700 | 81.9 | Mouser |  | 0 | 600 |  | 1000 | 102.82
D24-49 | Keyboard Ghosting Diode | BAT60JFILM | SOD-323 | Digikey | 497-3707-2-ND | 26 | 0.09528 | 2.47728 | 8060 | 767.9568 | 9000 | 324 | Mouser |  | 0 | 7800 |  | NS |  | v1 part
D24-49 | Keyboard Ghosting Diode | RB520S30T5G | SOD-523 | Digikey | RB520S30T5GOSDKR-ND | 26 | 0.06064 | 1.57664 | 8060 |  |  |  |  |  |  | 7800 |  | 9000 | 233.84 | v2 part
D3,D5-D23 | LEDs |  | 0603 | Digikey | 160-1435-2-ND | 19 | 0.0846 | 1.6074 | 5890 | 498.294 | 8000 | 300.8 |  |  | 0 | 5700 |  | 8000 | 300.8
DNS D4 | TVS Diode | SP0503BAHTG | SOT-143-4 | Digikey | F2715DKR-ND | 1 | 0.4622 | 0.4622 | 310 | 143.282 | 350 | 184.8 |  |  | 0 | 300 |  |  |  | v1 part, v2 removed
DNS J13 | Saintcon Addon Header |  |  |  |  | 1 |  | 0 | 310 | 0 |  |  |  |  | 0 | 300
DNS X1 | Shitty Addon socket |  |  |  |  | 1 |  | 0 | 310 | 0 |  |  |  |  | 0 | 300
DNS | Board to board - front board |  |  | Digikey |  | 0 |  | 0 | 0 | 0 |  |  |  |  | 0 | 0
DNS | Speaker | SP-1504 |  | Digikey | 433-1106-ND | 1 | 1.301 | 1.301 | 310 | 403.31 |  |  | Order to DC801 |  |  | 300
DNS | 2.4" TFT 320x240 LCD display |  |  | buydisplay | https://www.buydisplay.com/color-2-4-inch-tft-lcd-module-display-touch-panel-240x320-dot-serial-spi | 1 | 4.82 | 4.82 | 310 | 1494.2 |  |  | Have on hand |  |  | 300
J14 | JST-PH surface mount | S2B-PH-SM4-TB(LF)(SN) |  | Digikey | 455-1749-1-ND | 1 | 0.4194 | 0.4194 | 310 | 130.014 | 350 | 141.75 | Future | https://www.futureelectronics.com/p/6882450 | 0 | 300 |  | 325 | 52.325 | https://www.zaikostore.com/zaikostore/en/stockDetail?stockID=st49957207
J15 | USB-C | 1054500101 |  | Digikey | WM12856DKR-ND‎ | 1 | 1.8718 | 1.8718 | 310 | 580.258 | 350 | 545.86 |  |  | 0 | 300 |  | 325 | 619.95
J16 | FPC connector | 62684-50210E9ALF | Top Contact, 50 pin | Digikey | 609-5388-6-ND | 1 | 0.8245 | 0.8245 | 310 | 255.595 | 350 | 257.39 |  |  | 0 | 300 |  | 325 | 265.27
J17 | Board to board - back board | 61031021821 |  | Digikey | 732-13382-6-ND | 1 | 1.586 | 1.586 | 310 | 491.66 | 350 | 562.1 |  |  | 0 | 300 |  | 325 | 556.58
J18 | Micro SD socket | ST11S008V4HR2000 | MicroSD | Digikey | 670-2695-6-ND | 1 | 1.87264 | 1.87264 | 310 | 580.5184 | 350 | 602.84 |  |  | 0 | 300 |  | 325 | 585.27
L1 | Inductor, 4.7uH | LQM21PN4R7MGHL | 0805 |  | 490-16633-6-ND | 1 | 0.1622 | 0.1622 | 310 | 50.282 | 350 | 58.63 |  |  | 0 | 300 |  | 325 | 57.35 | v1 part
L1 | Inductor, 1uH | 490-16633-6-ND | 1008 | Digikey | 490-12068-6-ND | 1 | 0.17231 | 0.17231 | 310 |  |  |  |  |  |  |  |  | 325 | 56.5 | v2 part
Q1 | P-Channel mosfet | FDN360P | SSOT3 | Digikey | FDN360PDKR-ND | 1 | 0.16732 | 0.16732 | 310 | 51.8692 | 350 | 69.72 |  |  | 0 | 300 |  | NS |  | v1 part
Q1 | P-Channel mosfet | AO3409 | SOT-23-3 | Digikey | 785-1007-6-ND | 1 | 0.21487 | 0.21487 | 310 |  |  |  |  |  |  |  |  | 500 | 72.78 | v2 part
R1,R12 | 10k Resistor |  | 0603 | Digikey | ‎RMCF0603FT10K0TR-ND‎ | 2 | 0.0056 | 0.0112 | 620 | 3.472 | 5000 | 9.5 |  |  | 4000 | 0
R10,R11 | 5.1k Resistor |  | 0603 | Digikey | RMCF0603JG5K10CT-ND | 2 | 0.0053 | 0.0106 | 620 | 3.286 | 5000 | 8.55 |  |  | 4000 | 0
R13 | 33R Resistor |  | 0603 | Digikey | ‎RMCF0603FT33R0TR-ND‎ | 1 | 0.0056 | 0.0056 | 310 | 1.736 | 5000 | 9.5 |  |  | 4000 | 0
R14 | 100k Resistor |  | 0603 | Digikey | ‎CR0603-JW-104ELFTR-ND‎ | 1 | 0.0056 | 0.0056 | 310 | 1.736 | 5000 | 8.55 |  |  | 4000 | 0
R15 | 20k Resistor |  | 0603 | Digikey | RMCF0603JT20K0TR-ND | 1 | 0.0056 | 0.0056 | 310 | 1.736 | 5000 | 8.55 |  |  | 4000 | 0
R16 | 1k Resistor |  | 0603 | Digikey | RMCF0603JT1K00TR-ND‎ | 1 | 0.0053 | 0.0053 | 310 | 1.643 | 5000 | 8.55 |  |  | 4000 | 0
R2,R3 | 4.7k Resistor |  | 0603 | Digikey | RMCF0603JT4K70TR-ND | 2 | 0.0053 | 0.0106 | 620 | 3.286 | 5000 | 8.55 |  |  | 4000 | 0
R4 | 806k Resistor |  | 0603 | Digikey | RMCF0603FT806KTR-ND | 1 | 0.0063 | 0.0063 | 310 | 1.953 | 5000 | 9.5 |  |  | 4000 | 0
R5 | 2M Resistor |  | 0603 | Digikey | 2019-RK73B1JTTD205JTR-ND | 1 | 0.0056 | 0.0056 | 310 | 1.736 | 5000 | 8.55 |  |  | 4000 | 0
R6 | 470R Resistor |  | 0603 | Digikey | RMCF0603FT470RTR-ND | 1 | 0.0056 | 0.0056 | 310 | 1.736 | 5000 | 9.5 |  |  | 4000 | 0
R7,R8 | 27R Resistor |  | 0603 | Digikey | RMCF0603JT27R0TR-ND | 2 | 0.0056 | 0.0112 | 620 | 3.472 | 5000 | 8.55 |  |  | 4000 | 0
R9 | 2.0k Resistor |  | 0603 | Digikey | RMCF0603JT2K00TR-ND | 1 | 0.0056 | 0.0056 | 310 | 1.736 | 5000 | 8.55 |  |  | 4000 | 0
R17 | 540k |  | 0603 | Digikey | ‎RMCF0603FT536KTR-ND‎ | 1 | 0.0059 | 0.0059 | 310 | 1.829 | 5000 | 9.5 |  |  | 4000 | 0 |  |  |  | v1 part, v2 removed
R18 | 120k |  | 0603 | Digikey | RMCF0603FT120KTR-ND‎ | 1 | 0.0059 | 0.0059 | 310 | 1.829 | 5000 | 9.5 |  |  | 4000 | 0 |  |  |  | v1 part, v2 removed
SW1 | Power switch | JS102011SAQN |  | Digikey | 401-1999-6-ND | 1 | 0.50908 | 0.50908 | 310 | 157.8148 | 350 | 168.98 |  |  | 0 | 300 |  | 325 | 165.11
SW18,SW19 | Joystick | SKRHABE010 |  | Mouser | 688-SKRHAB | 2 | 1.69 | 3.38 | 620 | 1047.8 | 650 | 1098.5 | Mouser |  | 0 | 600 |  | 625 | 1256.25
SW2-17 | Buttons | PTS 647 SM50 SMTR2 LFS | 4.5x4.5x5.0, 1.8N | Digikey | PTS647SM50SMTR2LFSTR-ND | 16 | 0.07677 | 1.22832 | 4960 | 380.7792 | 9000 | 855 | Mouser |  | 4000 | 800 |  | 1500 | 187.79
U1 | Audo codec | NAU8810YG | 20QFN | Digikey | NAU8810YG-ND | 1 | 1.52004 | 1.52004 | 310 | 471.2124 |  |  |  |  | 0 | 300 |  | 325 | 559
U2 | Vreg buck converter | PAM2305AABADJ | SOT23-5 | Digikey | PAM2305AABADJDIDKR-ND‎ | 1 | 0.37 | 0.37 | 310 | 114.7 | 350 | 118.3 |  |  | 0 | 300 |  | NS |  | v1 part
U2 | Vreg buck converter | SC189ZULTRT | 6-UFDFN Exposed Pad | Digikey | SC189ZULDKR-ND | 1 | 0.8181 | 0.8181 | 310 | 253.611 |  |  |  |  | 0 | 300 |  | 325 | 265.54 | v2 part
U3 | Rigado BMD-340 | BMD-340-A-R | BMD-340 | Digikey | 672-BMD-340-A-RTR-ND | 1 | 9.61596 | 9.61596 | 310 | 2980.9476 |  |  | NS |  | 300 | 0 |  | At PCBX
U4 | LiPo charger, 500mA | MCP73832T-2ACI/OT |  | Digikey | MCP73832T-2ACI/OTDKR-ND | 1 | 0.42 | 0.42 | 310 | 130.2 | 350 | 161 |  |  | 0 | 300 |  |  |  | v1 part
 |  |  |  |  | MCP73831T-2DCI/OTDKR-ND | 1 | 0.71154 | 0.71154 | 310 |  |  |  |  |  |  |  |  | 325 | 231.25 | v2 part
U5 | Flash memory | S25FL256S |  | Digikey | 2015-S25FL256SDSMFV013CT-ND | 1 | 1.37 | 1.37 | 310 | 424.7 | 350 | 500.5 |  |  | 61 | 239 |  | 240 | 844.08 | https://www.arrow.com/en/products/s25fl256sagmfir01/cypress-semiconductor?region=nac
U6 | I2C LED Driver | IS31FL3736-QFLS4-TR | 40QFN | Digikey | 706-1510-1-ND | 1 | 1.225 | 1.225 | 310 | 379.75 | 350 | 461.47 |  |  | 0 | 300 |  |  |  | v1 part
 |  |  |  |  | 2521-IS31FL3736B-QFLS4-DKR-ND | 1 | 2.33875 | 2.33875 | 310 |  |  |  |  |  |  |  |  | 325 | 558.2 | v2 part
U7 | Keyboard Controller | ATTINY1617-MNR | 24VQFN | Digikey | ATTINY1617-MNRCT-ND | 1 | 0.75 | 0.75 | 310 | 232.5 | 350 | 262.5 | Mouser |  | 310 | 0 |  |  |  | v1 part
 |  |  |  |  | ATTINY1617-MNRCT-ND | 1 | 1.16154 | 1.16154 | 310 |  |  |  |  |  |  |  |  | 325 | 377.5 | v2 part
 |  |  |  |  |  | 145 |  | 45.72493 | 44950 | 12260.2768 |  | 7178.44 |  |  |  |  |  | 7253.385
 |  |  |  |  |  |  | Badges |  | Color | Qty
 |  |  |  |  |  |  |  |  | Red | 10
 |  |  |  |  |  |  |  |  |  | 300
 |  |  |  |  |  |  |  |  |  | 310

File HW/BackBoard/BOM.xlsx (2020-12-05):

Ref Des | Description | Mfg Part # | Package | Supplier | Supplier Part # | QTY per badge | Cost ea | Cost badge | For Proto | Total Needed | Total Cost
C1,C13,C14,C15,C17,C20,C23,C24,C25 | 0.1uF Cap |  | 0603 | Digikey | 478-06036C104KAT4ACT-ND | 9 | 0.0178 | 0.1602 | B | 2790 | 49.662
C10,C11 | 47pF Cap |  | 0603 | Digikey | 732-7750-1-ND | 2 | 0.0232 | 0.0464 | B | 620 | 14.384
C16,C18,C21,C22 | 0.47uF Cap |  | 0603 | Digikey | 1292-1453-1-ND | 4 | 0.032 | 0.128 | B | 1240 | 39.68
C19 | 22uF Cap |  | 0603 | Digikey | 490-10476-1-ND | 1 | 0.1279 | 0.1279 | B | 310 | 0
C2,C4,C5,C8,C9,C12 | 4.7uF Cap |  |  | Digikey | 1276-1045-1-ND | 6 | 0.0203 | 0.1218 | B | 1860 | 37.758
C3 | 10uF cap |  | 0603 | Digikey | 587-6017-1-ND | 1 | 0.0644 | 0.0644 | B | 310 | 19.964
C6 | 22uF cap |  | 0805 | Digikey | 1276-6780-1-ND | 1 | 0.1476 | 0.1476 | B | 310 | 45.756
C7 | 1nF Capacitor |  |  | Digikey | 1292-1381-1-ND | 1 | 0.0128 | 0.0128 | B | 310 | 3.968
D1,D2 | Schottky diode | VS-10MQ040-M3/5AT |  | Digikey | 112-VS-10MQ040-M3/5ATDKR-ND | 2 | 0.12972 | 0.25944 | B | 620 | 80.4264
D24-49 | Keyboard Ghosting Diode | BAT60JFILM | SOD-323 | Digikey | 497-3707-1-ND | 26 | 0.09528 | 2.47728 | B | 8060 | 767.9568
D3,D5-D23 | LEDs |  | 0603 | Digikey | 160-1435-1-ND | 19 | 0.0846 | 1.6074 | B | 5890 | 498.294
D4 | TVS Diode | SP0503BAHTG | SOT-143-4 | Digikey | F2715DKR-ND | 1 | 0.4622 | 0.4622 | B | 310 | 143.282
DNS | Saintcon Addon Header |  |  |  |  | 1 |  | 0 | N | 310 | 0
DNS | Shitty Addon socket |  |  |  |  | 2 |  | 0 | N | 620 | 0
DNS | Board to board - front board |  |  | Digikey |  | 0 |  | 0 | N | 0 | 0 | Do not buy for backboard
DNS | Speaker | SP-1504 |  | Digikey | 433-1106-ND | 1 | 1.301 | 1.301 | B | 310 | 403.31
DNS | 2.4" TFT 320x240 LCD display |  |  | buydisplay | https://www.buydisplay.com/color-2-4-inch-tft-lcd-module-display-touch-panel-240x320-dot-serial-spi | 1 | 4.82 | 4.82 | Y | 310 | 1494.2
J14 | JST-PH surface mount | S2B-PH-SM4-TB(LF)(SN) |  | Digikey | 455-1749-1-ND | 1 | 0.4194 | 0.4194 | B | 310 | 130.014
J15 | USB-C | 1054500101 |  | Digikey | WM12856CT-ND | 1 | 1.8718 | 1.8718 | B | 310 | 580.258
J16 | FPC connector | 62684-50210E9ALF | Top Contact, 50 pin | Digikey | 609-5388-1-ND | 1 | 0.8245 | 0.8245 | B | 310 | 255.595
J17 | Board to board - back board | 61031021821 |  | Digikey | 732-13382-1-ND | 1 | 1.586 | 1.586 | B | 310 | 491.66
J18 | Micro SD socket | ST11S008V4HR2000 | MicroSD | Digikey | 670-2695-6-ND | 1 | 1.87264 | 1.87264 | B | 310 | 580.5184
L1 | Inductor | ASPI-3012S-1R0M-T | 3.00mm x 3.00mm | Digikey | 535-15236-6-ND | 1 | 0.2309 | 0.2309 | B | 310 | 71.579
Q1 | P-Channel mosfet | FDN360P | SSOT3 | Digikey | FDN360PCT-ND | 1 | 0.16732 | 0.16732 | B | 310 | 51.8692
R1,R12 | 10k Resistor |  | 0603 | Digikey | RMCF0603JT10K0CT-ND | 2 | 0.0056 | 0.0112 | B | 620 | 3.472
R10,R11 | 5.1k Resistor |  | 0603 | Digikey | RMCF0603JG5K10CT-ND | 2 |  | 0 | Y | 620 | 0
R13 | 33R Resistor |  |  | Digikey | RMCF0603JT33R0CT-ND | 1 | 0.0056 | 0.0056 | B | 310 | 1.736
R14 | 100k Resistor |  | 0603 | Digikey | CR0603-JW-104ELFCT-ND | 1 | 0.0056 | 0.0056 | B | 310 | 1.736
R15 | 20k Resistor |  | 0603 | Digikey | RMCF0603JT20K0CT-ND | 1 | 0.0056 | 0.0056 | B | 310 | 1.736
R16 | 1k Resistor |  | 0603 | Digikey | RMCF0603JJ1K00CT-ND | 1 |  | 0 | Y | 310 | 0
R2,R3 | 4.7k Resistor |  | 0603 | Digikey | RMCF0603JT4K70CT-ND | 2 |  | 0 | Y | 620 | 0
R4 | 806k Resistor |  |  | Digikey | RMCF0603FT806KCT-ND | 1 | 0.0063 | 0.0063 | B | 310 | 1.953
R5 | 2M Resistor |  |  | Digikey | 2019-RK73B1JTTD205JCT-ND | 1 | 0.0056 | 0.0056 | B | 310 | 1.736
R6 | 470R Resistor |  | 0603 | Digikey | RMCF0603JT470RCT-ND | 1 | 0.0056 | 0.0056 | B | 310 | 1.736
R7,R8 | 27R Resistor |  | 0603 | Digikey | RMCF0603JT27R0CT-ND | 2 | 0.0056 | 0.0112 | B | 620 | 3.472
R9 | 2.0k Resistor |  | 0603 | Digikey | RMCF0603JT2K00CT-ND | 1 | 0.0056 | 0.0056 | B | 310 | 1.736
SW1 | Power switch | JS102011SAQN |  | Digikey | 401-1999-1-ND | 1 | 0.50908 | 0.50908 | B | 310 | 157.8148
SW18,SW19 | Joystick | SKRHABE010 |  | Mouser | 688-SKRHAB | 2 | 1.69 | 3.38 | Y | 620 | 1047.8
SW2-17 | Buttons | PTS 647 SM50 SMTR2 LFS | 4.5x4.5x5.0, 1.8N | Digikey | PTS647SM50SMTR2LFSTR-ND | 27 | 0.07677 | 2.07279 | B | 8370 | 642.5649
U1 | Audo codec | NAU8810YG | 20QFN | Digikey | NAU8810YG-ND | 1 | 1.52004 | 1.52004 | B | 310 | 471.2124
U2 | Vreg buck converter | SC189ZSKTRT | SOT23-5 | Digikey | SC189ZSKDKR-ND | 1 | 0.665 | 0.665 | B | 310 | 206.15
U3 | Rigado BMD-340 | BMD-340-A-R | BMD-340 | Digikey | 672-BMD-340-A-RTR-ND | 1 | 9.61596 | 9.61596 | B | 310 | 2980.9476
U4 | LiPo charger, 500mA | MCP73832T-2ACI/OT |  | Digikey | MCP73832T-2ACI/OTCT-ND | 1 | 0.42 | 0.42 | B | 310 | 130.2
U5 | Flash memory | S25FL256S |  | Digikey | 2015-S25FL256SDSMFV013CT-ND | 1 | 1.37 | 1.37 | B | 310 | 424.7
U6 | I2C LED Driver | IS31FL3736-QFLS4-TR | 40QFN | Digikey | 706-1510-1-ND | 1 | 1.225 | 1.225 | B | 310 | 379.75
U7 | Keyboard Controller | ATTINY1617-MNR | 24VQFN | Digikey | ATTINY1617-MNRCT-ND | 1 | 0.75 | 0.75 | B | 310 | 232.5
 |  |  |  |  |  | 122 |  | 39.83665 | Total | 37820 | 12349.3615
 |  |  |  |  |  |  | Badges |  | Purpose | Color | Qty
 |  |  |  |  |  |  |  |  | Prototype | Red | 10
 |  |  |  |  |  |  |  |  | User |  | 300
 |  |  |  |  |  |  |  |  | Total |  | 310

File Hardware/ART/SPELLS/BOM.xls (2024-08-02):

 |  |  |  |  |  | Pricing @ qty 100
Reference | Value | Package | Source | Datasheet | Quantity | Each | Total
C2, C4, C7, C8, C9, C11, C12, C13, C14, C16 | 100n | 0603 | ~ |  | 10 | 0.1 | 1
C1, C3, C10, C15 | 1u | 0603 | ~ |  | 4 | 0.1 | 0.4
C5, C6 | 1pF | 0603 | ~ |  | 2 | 0.1 | 0.2
R8, R9, R10 | 1M | 0603 | ~ |  | 3 | 0.1 | 0.3
R1, R2 | 27 | 0603 | ~ |  | 2 | 0.1 | 0.2
R4, R7 | 10k | 0603 | ~ |  | 2 | 0.1 | 0.2
R3, R5, R6 | 1k | 0603 | ~ |  | 3 | 0.1 | 0.3
D3, D4, D5, D6, D7, D8, D9, D10, D11, D12 | SK6812SIDE-A |  | https://www.digikey.com/en/products/detail/adafruit-industries-llc/4691/13170955 | ~ | 10 | 0.395 | 3.95
D1 | Schottky | SOD-123 |  |  | 1 | 0.5 | 0.5
D2 | Red | 0402 | ~ |  | 1 | 0.03 | 0.03
Q1 | DMG2301L | SOT-23 |  |  | 1 | 0.17 | 0.17
U1 | RP2040 | QFN56 |  |  | 1 | 1.12 | 1.12
U2 | W25Q32JVSS | SOIC-8 |  |  | 1 | 0.38 | 0.38
Y1 | ABLS-12.000MHZ-B4-T |  | https://www.digikey.com/en/products/detail/abracon-llc/ABLS-12-000MHZ-B4-T/2184161 | ~ | 1 | 0.32 | 0.32
SW1, SW2 | SPST |  |  |  | 2 | 0.21 | 0.42
J1 | 2x5 2.54 SMD |  |  |  | 1 | 0.71 | 0.71
J4 | USB Micro Molex |  |  |  | 1 | 0.33 | 0.33
VR1 | AP7366-33W5-7 | SOT-25 | https://www.digikey.com/en/products/detail/diodes-incorporated/AP7366-33W5-7/9867322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 | ~ | 1 | 0.214 | 0.214
BOARD-TO-BOARD | 8.08mm |  | https://www.digikey.com/en/products/detail/amphenol-cs-fci/10129383-910002ALF/7916193 | ~ | 1 | 0.4 | 0.4
PCB+SHIPPING | Prototype |  |  |  | 1 | 3 | 3
 |  |  |  |  |  |  | 14.144

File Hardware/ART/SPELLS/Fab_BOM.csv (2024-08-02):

Reference | Value | Package | Source | Datasheet | Quantity
C2, C4, C7, C8, C9, C11, C12, C13, C14, C16 | 100n | 0603 | ~ |  | 10
C1, C3, C10, C15 | 1u | 0603 | ~ |  | 4
C5, C6 | 1pF | 0603 | ~ |  | 2
R8, R9, R10 | 1M | 0603 | ~ |  | 3
R1, R2 | 27 | 0603 | ~ |  | 2
R4, R7 | 10k | 0603 | ~ |  | 2
R3, R5, R6 | 1k | 0603 | ~ |  | 3
D3, D4, D5, D6, D7, D8, D9, D10, D11, D12 | SK6812SIDE-A |  | https://www.lcsc.com/product-detail/Light-Emitting-Diodes-LED_OPSCO-Optoelectronics-SK6812SIDE-A-RVS_C2890037.html | ~ | 10
D1 | Schottky | SOD-123 | https://www.digikey.com/en/products/detail/micro-commercial-co/SM5819PL-TP/1793253 |  | 1
D2 | Red | 0402 | https://www.lcsc.com/product-detail/Light-Emitting-Diodes-span-style-background-color-ff0-LED-span_Foshan-NationStar-Optoelectronics-NCD0402R1_C130719.html |  | 1
Q1 | DMG2301L | SOT-23 | https://www.digikey.com/en/products/detail/diodes-incorporated/DMG2301L-7/5768820 |  | 1
U1 | RP2040 | QFN56 | https://www.lcsc.com/product-detail/Microcontroller-Units-MCUs-MPUs-SOCs_Raspberry-Pi-RP2040_C2040.html |  | 1
U2 | W25Q32JVSS | SOIC-8 | https://www.lcsc.com/product-detail/NOR-FLASH_Winbond-Elec-W25Q32JVSSIQ_C179173.html |  | 1
Y1 | ABLS-12.000MHZ-B4-T |  | https://www.digikey.com/en/products/detail/abracon-llc/ABLS-12-000MHZ-B4-T/2184161 | ~ | 1
SW1, SW2 | SPST |  | https://www.lcsc.com/product-detail/Tactile-Switches_TE-Connectivity-1825910-6_C428628.html |  | 2
J1 | 2x5 2.54 SMD |  | https://www.digikey.com/en/products/detail/amphenol-cs-fci/10129383-910002ALF/7916193 |  | 1
J4 | USB Micro Molex |  | https://www.digikey.com/en/products/detail/molex/0473460001/1782470?s=N4IgTCBcDaIAwBYDsBmBA2OWCMIC6AvkA |  | 1
VR1 | AP7366-33W5-7 | SOT-25 | https://www.lcsc.com/product-detail/Linear-Voltage-Regulators-LDO_Diodes-Incorporated-AP7366-33W5-7_C526385.html | ~ | 1

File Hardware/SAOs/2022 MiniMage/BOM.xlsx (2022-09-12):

Ref Des | Description | Mfg Part # | Package | Supplier | Supplier Part # | QTY per badge | Cost ea | Cost badge
D1-2 | LED green | LTST-S220GKT | 0805 | Digikey | 160-1218-2-ND | 2 | 0.0618 | 0.1236
D3-4 | LED red | LTST-S220KRKT | 0805 | Digikey | 160-1469-2-ND | 2 | 0.0699 | 0.1398
R1-2 | Resistor 100 ohm | AC0805FR-10100RL | 0805 | Digikey | 13-AC0805FR-10100RLTR-ND | 2 | 0.0195 | 0.039
 |  |  |  |  |  | 6 |  | 0.3024
 |  |  |  |  |  | Run | 200
 |  |  |  |  |  | Cost | 60.48

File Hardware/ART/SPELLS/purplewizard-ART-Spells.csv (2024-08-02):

Source: | D:\GDrive\Projects\KiCad\Badges\BM-Badge\Hardware\ART\2022\purplewizard-ART-Spells.kicad_sch
Date: | 8/2/2022 7:47:15 AM
Tool: | Eeschema (6.0.6)
Generator: | C:\Program Files\KiCad\6.0\bin\scripting\plugins/bom_csv_grouped_by_value_with_fp.py
Component Count: | 50
Ref | Qnty | Value | Cmp name | Footprint | Description | Vendor
C1, C10, C15, | 3 | 1uF | C_Small_12 | Capacitor_SMD:C_0603_1608Metric_Pad1.08x0.95mm_HandSolder | Unpolarized capacitor, small symbol
C2, C4, C7, C8, C9, C11, C12, C13, C14, C16, | 10 | 100n | C_Small | Capacitor_SMD:C_0603_1608Metric_Pad1.08x0.95mm_HandSolder | Unpolarized capacitor, small symbol
C3, | 1 | 1u | C_Small_8 | Capacitor_SMD:C_0603_1608Metric_Pad1.08x0.95mm_HandSolder | Unpolarized capacitor, small symbol
C5, C6, | 2 | 27pF | C_Small_1 | Capacitor_SMD:C_0603_1608Metric_Pad1.08x0.95mm_HandSolder | Unpolarized capacitor, small symbol
D1, | 1 | D_Schottky | D_Schottky | SM5819PL-TP:SM5819PL-TP | Schottky diode
D2, | 1 | LED | LED | LED_SMD:LED_0402_1005Metric_Pad0.77x0.64mm_HandSolder | Light emitting diode
D3, D4, D5, D6, D7, D8, D9, D10, D11, D12, | 10 | SK6812SIDE-A | SK6812SIDE-A | ART-Spells:SK6812SIDE-A | RGB LED with integrated controller
J1, | 1 | ART Expansion | Conn_02x05_Odd_Even | Connector_PinSocket_2.54mm:PinSocket_2x05_P2.54mm_Vertical_SMD | Generic connector, double row, 02x05, odd/even pin numbering scheme (row 1 odd numbers, row 2 even numbers), script generated (kicad-library-utils/schlib/autogen/connector/)
J2, | 1 | 1v | Conn_01x01 | TestPoint:TestPoint_Pad_D1.0mm | Generic connector, single row, 01x01, script generated (kicad-library-utils/schlib/autogen/connector/)
J3, | 1 | 5v | Conn_01x01 | TestPoint:TestPoint_Pad_D1.0mm | Generic connector, single row, 01x01, script generated (kicad-library-utils/schlib/autogen/connector/)
J4, | 1 | USB_B_Micro | USB_B_Micro | Connector_USB:USB_Micro-B_Molex_47346-0001 | USB Micro Type B connector
J5, | 1 | 3v3 | Conn_01x01 | TestPoint:TestPoint_Pad_4.0x4.0mm | Generic connector, single row, 01x01, script generated (kicad-library-utils/schlib/autogen/connector/)
J6, | 1 | GND | Conn_01x01 | TestPoint:TestPoint_Pad_4.0x4.0mm | Generic connector, single row, 01x01, script generated (kicad-library-utils/schlib/autogen/connector/)
Q1, | 1 | DMG2301L | DMG2301L | Package_TO_SOT_SMD:SOT-23 | -3A Id, -20V Vds, P-Channel MOSFET, SOT-23
R1, R2, | 2 | 27 | R_Small_3 | Resistor_SMD:R_0603_1608Metric_Pad0.98x0.95mm_HandSolder | Resistor, small symbol
R3, R5, R6, | 3 | 1k | R_Small_8 | Resistor_SMD:R_0603_1608Metric_Pad0.98x0.95mm_HandSolder | Resistor, small symbol
R4, R7, | 2 | 10k | R_Small_9 | Resistor_SMD:R_0603_1608Metric_Pad0.98x0.95mm_HandSolder | Resistor, small symbol
R8, R9, R10, | 3 | 1M | R_Small | Resistor_SMD:R_0603_1608Metric_Pad0.98x0.95mm_HandSolder | Resistor, small symbol
SW2, | 1 | SW_SPST | SW_SPST | SW_SPST_PTS647:SW_SPST_PTS647 | Single Pole Single Throw (SPST) switch
U1, | 1 | RP2040 | RP2040 | rp2040:QFN40P700X700X90-57N
U2, | 1 | W25Q32JVSS | W25Q32JVSS | Package_SO:SOIC-8_5.23x5.23mm_P1.27mm | 32Mb Serial Flash Memory, Standard/Dual/Quad SPI, SOIC-8
VR1, | 1 | AP7366-33W5-7 | AP7366-33W5-7 | AP7365-33WG-7:AP7365-33WG-7
Y1, | 1 | ABLS-12.000MHZ-B4-T | Crystal_Small | ABLS-12MHZ:XTAL1140X470X420N | Two pin crystal, small symbol

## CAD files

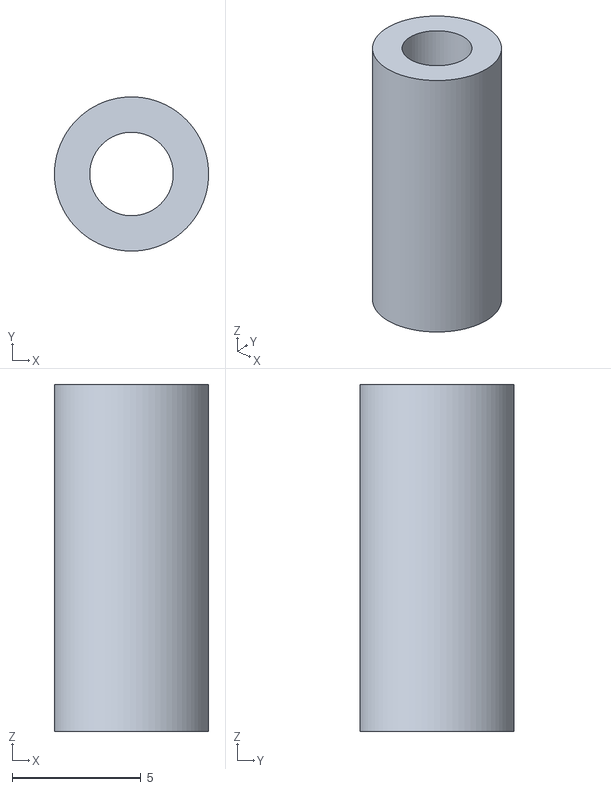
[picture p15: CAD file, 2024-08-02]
Hardware/ART/SPELLS/standoff_135.stl
6.00 x 6.00 x 13.5

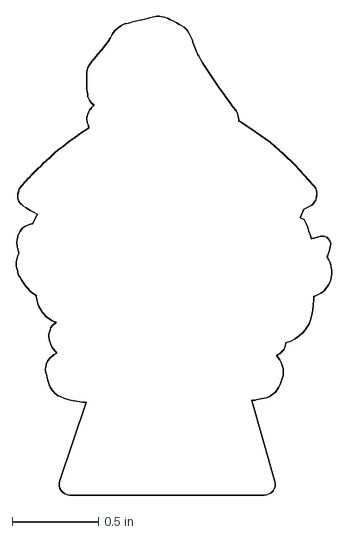
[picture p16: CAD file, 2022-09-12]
Hardware/SAOs/2022 MiniMage/images/outline.dxf
1.83 x 2.77 in

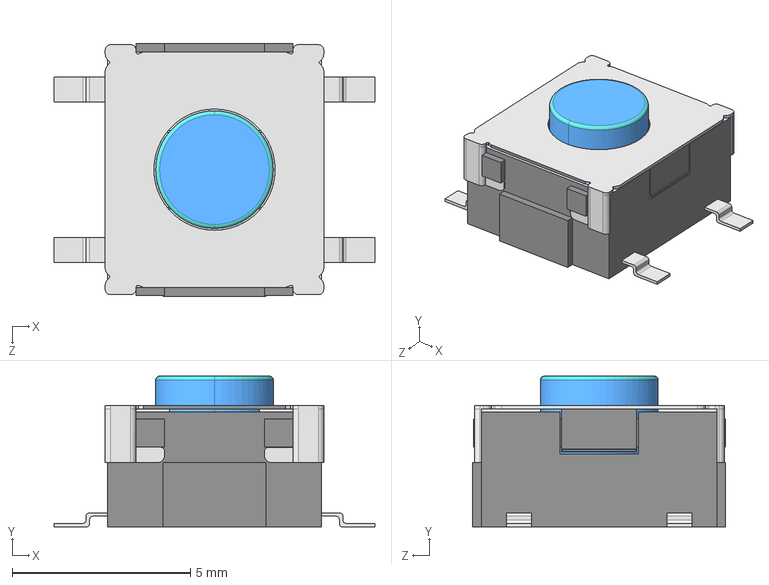
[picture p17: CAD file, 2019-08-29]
HW/BackBoard/3D/01_tactile_push_boton_B3S-1000_newark_52F3560.STEP
9.00 x 4.23 x 7.08 mm

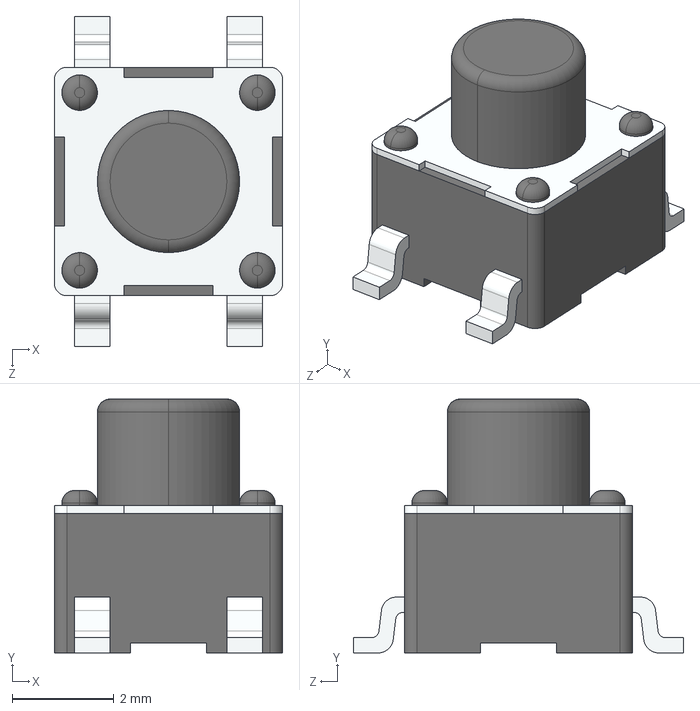
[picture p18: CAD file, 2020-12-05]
Hardware/BackBoard Pogo Jig/3D/CK PTS647.STEP
4.50 x 5.00 x 6.50 mm

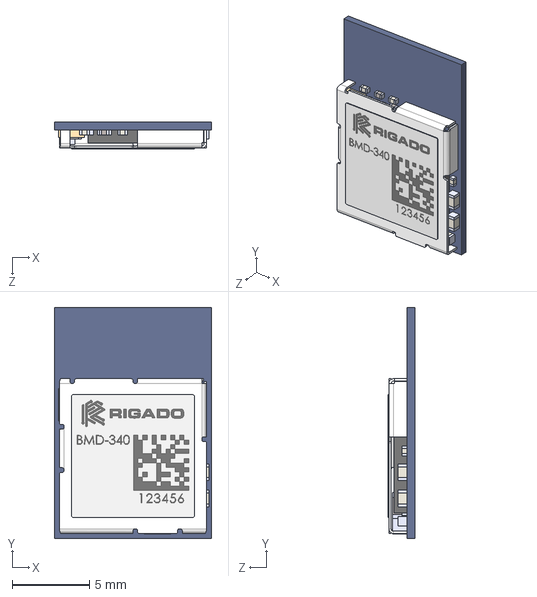
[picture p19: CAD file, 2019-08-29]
Hardware/BackBoard/3D/BMD-340.STEP
10.2 x 15.0 x 1.73 mm

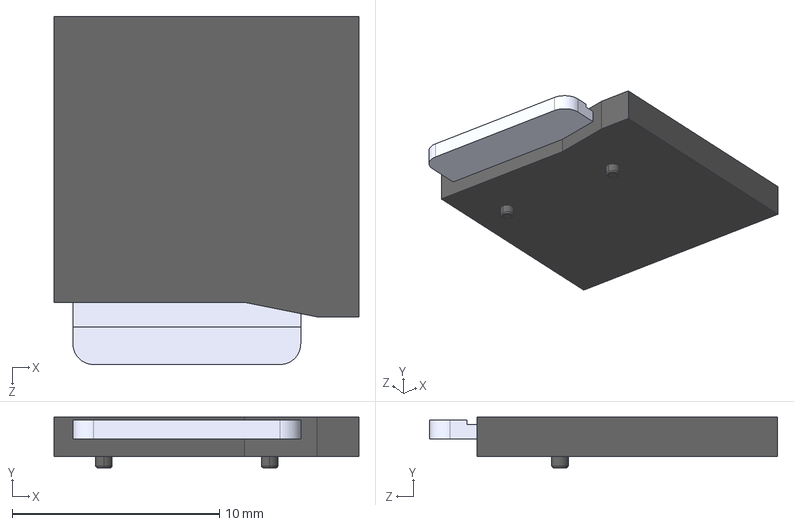
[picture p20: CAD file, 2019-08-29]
HW/BackBoard/3D/MicroSD.STEP
14.7 x 2.45 x 16.8 mm

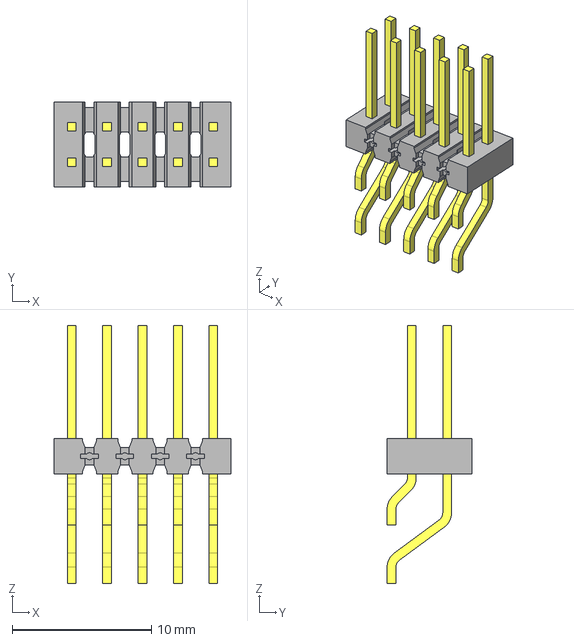
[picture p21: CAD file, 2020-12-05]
Hardware/BackBoard Pogo Jig/3D/TSM-105-02-T-DH.stp
12.7 x 6.10 x 18.5 mm
_TSM-105-02-DH_body
_T-1S6-09(-02-5-DH)

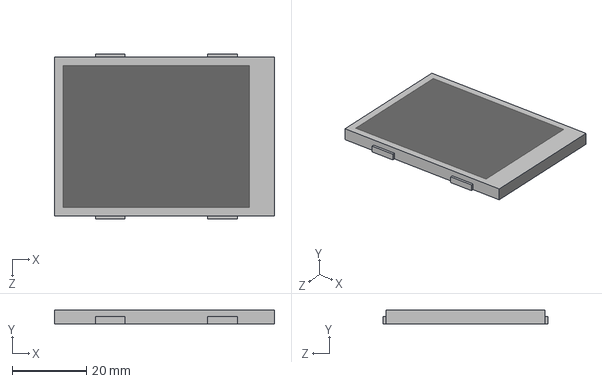
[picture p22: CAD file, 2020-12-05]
Hardware/BackBoard Pogo Jig/3D/LCD ER-TFT024-3.STEP
59.3 x 3.80 x 44.3 mm

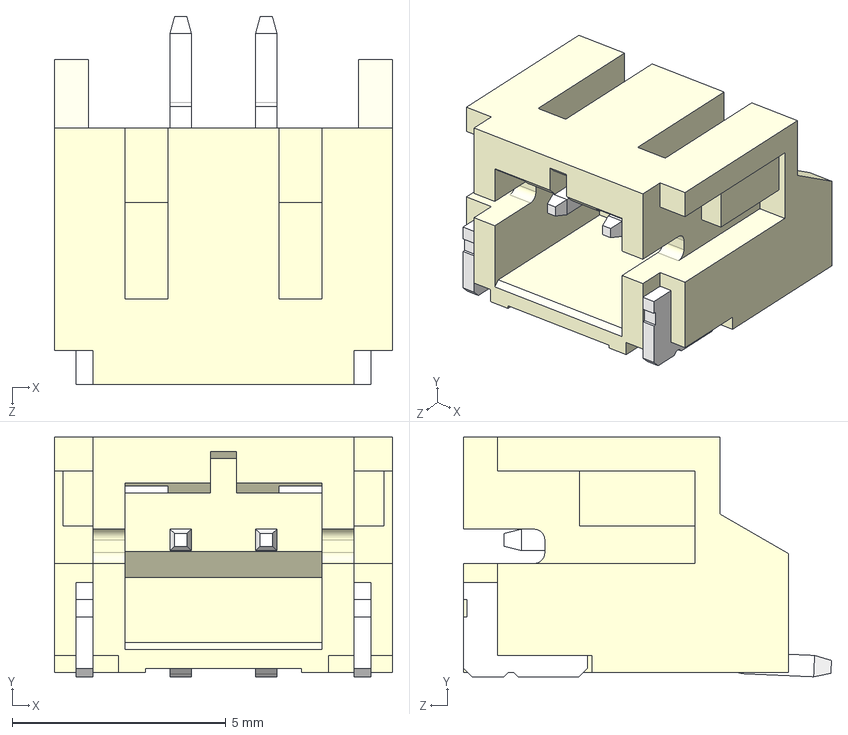
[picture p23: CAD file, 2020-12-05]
Hardware/BackBoard Pogo Jig/3D/S2B-PH-SM4-TB(LF)(SN)--3DModel-STEP-56544.STEP
7.90 x 5.60 x 8.60 mm

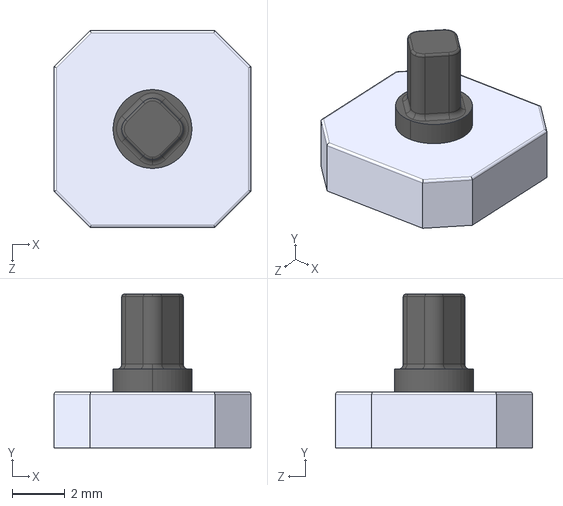
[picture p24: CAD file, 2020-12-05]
Hardware/BackBoard Pogo Jig/3D/SKRHABE010.STEP
7.50 x 5.86 x 7.50 mm

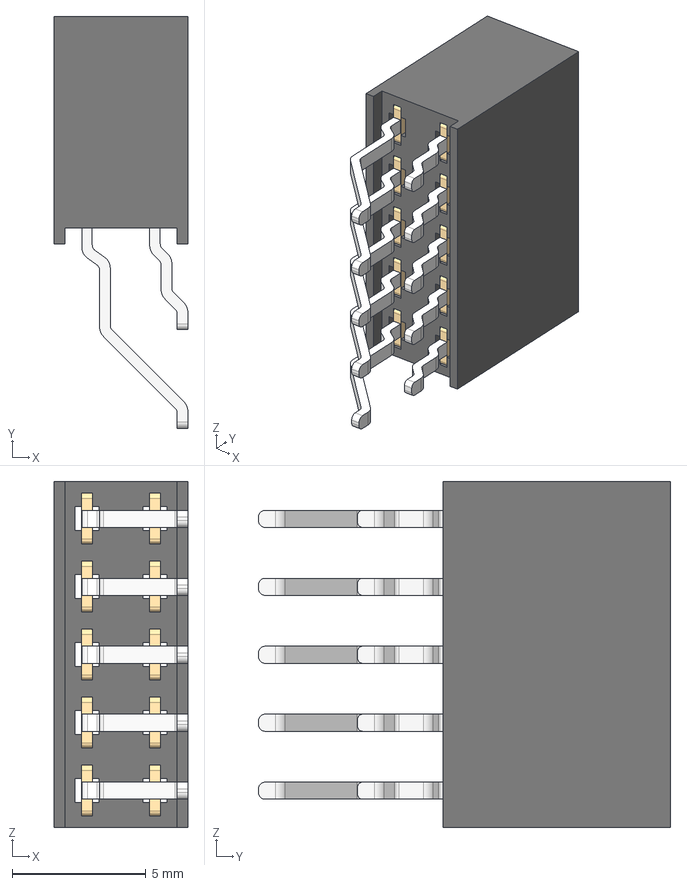
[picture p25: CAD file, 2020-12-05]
Hardware/BackBoard Pogo Jig/3D/m20-7920542_asm.stp
5.00 x 15.4 x 12.9 mm
M20-79205_MOULD
M20-792_CONTACT1 x 5
M20-792_CONTACT2 x 5

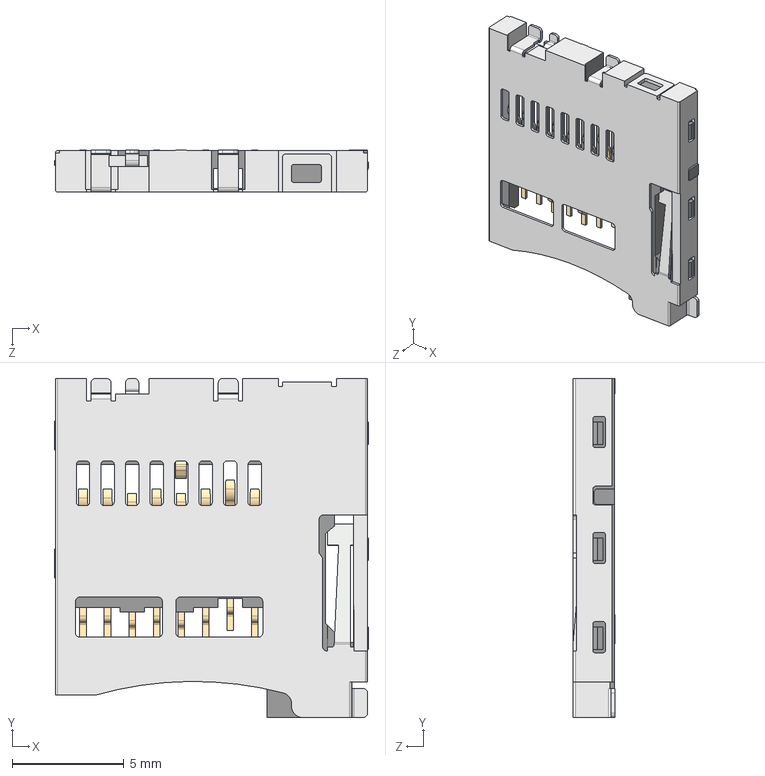
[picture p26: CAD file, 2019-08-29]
Hardware/BackBoard/3D/473521001_microSD.step
14.1 x 15.2 x 1.88 mm

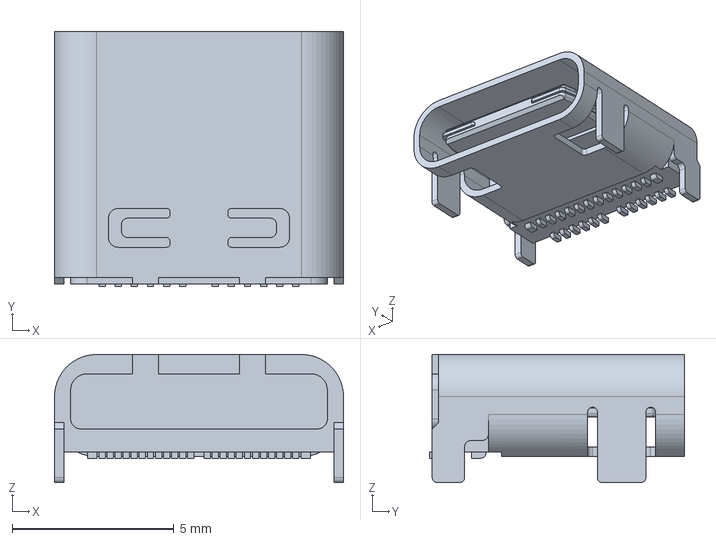
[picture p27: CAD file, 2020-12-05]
Hardware/BackBoard Pogo Jig/3D/1054500101.stp
8.94 x 7.90 x 3.96 mm

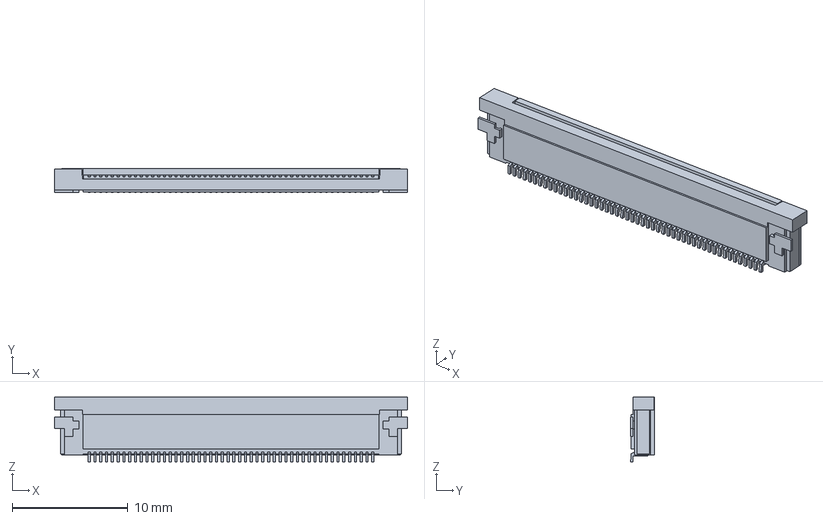
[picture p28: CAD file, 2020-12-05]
Hardware/BackBoard Pogo Jig/3D/s62684-502100alf.stp
30.5 x 2.05 x 5.60 mm

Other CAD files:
HW/BackBoard/3D/01_tactile_push_boton_B3S-1000_newark_52F3560.SLDPRT
HW/BackBoard/3D/MicroSD.SLDPRT
Hardware/BackBoard Pogo Jig/3D/CK PTS647.SLDPRT
Hardware/BackBoard Pogo Jig/3D/JS102011SAQN.SLDPRT
Hardware/BackBoard Pogo Jig/3D/JS102011SAQN.stp
Hardware/BackBoard Pogo Jig/3D/LCD ER-TFT024-3.SLDPRT
Hardware/BackBoard Pogo Jig/3D/SKRHABE010.SLDPRT
Hardware/BackBoard/3D/01_tactile_push_boton_B3S-1000_newark_52F3560.SLDPRT
Hardware/BackBoard/3D/MicroSD.SLDPRT

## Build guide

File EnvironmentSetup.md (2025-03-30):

# Setting up the DC801 Badge Dev Environment

Want to get started developing for the DC801 badge? Read through these instructions and we'll have you up and running in no time!

## Assumptions

You don't have any hardware to develop this on, because it's not done yet.

This guide is written assuming you will be using Ubuntu 20.04 or greater. It will probably work with other versions of Linux, and possibly Windows, but you'll have to figure out those differences yourself.

----

## Desktop Build
Since __**THE HARDWARE ISN'T READY YET**__, you early adopters will have to try out our game on your computer that runs about a thousand times faster than our real badge hardware - so if it seems like it runs a little faster than it should, uhh... get used to it.

### Install most of our software dependencies via package manager

- GIT (https://git-scm.com/)
    - version control
- SDL (https://www.libsdl.org/)
    - desktop build window and framebuffer management, input handling
- pip, Python Package Manager
(https://pypi.org/project/pip/)
    - required for compiledb to create compile-commands.json
- GDB, the Gnu Debugger (https://www.gnu.org/software/gdb/)
    - because writing software without a debugger is for idiots and savants that hate themselves
- The Python package `compiledb` Compilation Database Generator (https://github.com/nickdiego/compiledb)
    - this generates the `Software/GameEngine/compile-commands.json` file that allows VSCode's Intellisence system to understand the relationships between all the `.c` and `.h` files, and gives tab completion, include path stuff, etc.

```shell script
# basic C/C++ build tools and what we need to pull our sources and dependencies
sudo apt install -y \
  build-essential \
  gdb \
  git \
  wget \
  python3-pip

# window/graphics/input management for the desktop and web build of the game
sudo apt install -y \
  libsdl2-2.0-0 \
  libsdl2-dev \
  libsdl2-image-2.0-0 \
  libsdl2-image-dev

pip3 install compiledb --break-system-packages
# pip installs packages into `~/.local/bin`, but doesn't bother
# adding that do your path so you can, you know, use them.
# These echo lines add the user local pip install path to the
# PATH variable so you can run `compiledb`.
echo 'export PATH="$HOME/.local/bin:$PATH"' >> ~/.bashrc
# At this point, you may need to close your terminal, relaunch
# your IDE, or even sign out and back in before you'll be able
# to run the `compiledb` command in the context you need it.
```

### Setup a dev directory structure

The structure of the project files is important for `make`, so try not to deviate from it. You can make it work with a different structure, but I suggest following ours.

```shell script
mkdir -p ~/dev/
mkdir -p ~/dev/installer
```

### Git Clone the badge source code

```shell script
cd ~/dev/
git clone https://github.com/DC801/BM-Badge/
```

This clones the badge source code from git and saves it out to `~/dev/BM-Badge`.

### Install VSCode, if you don't already have it

We're going to be using VSCode and GCC to do our development. There are other options out there like VIM or nice tools like CLion, but sticking with an open source stack means no pesky license fees and more flexibility.

```shell script
sudo snap install --classic code
```

...but if you hate Snap for some reason, you can download VSCode from here: https://code.visualstudio.com/

### Compiling and running the Desktop Build:

- From within VSCode, select (`File` -> `Open Folder...`) and select the `~/dev/BM-Badge` folder.
- Open a terminal (`Terminal` -> `New Terminal`) or use `Ctrl+backtick`
- From within the terminal that appears, run the following (replace `8` with the number of cores your machine has, or the number of cores you have allocated to your VM):
```shell script
cd Software/GameEngine/
make cleanall
compiledb make DESKTOP=1 -j8
```

You should now have everything compiled in the `~/dev/BM-Badge/Software/GameEngine/output` folder. Since we compiled the desktop build above, let's test running it.

From within the VSCode Terminal:
```shell script
cd ~/dev/BM-Badge/Software/GameEngine/output
./bm_badge.out
```

You should now have the badge running on your desktop computer screen!

To debug you need to open the Run/debug menu on the left (`Ctrl+Shift+D`). It looks like it has a triangle and a bug symbol. At the top, make sure that the dropdown says "Debug (Desktop)", and either click the green arrow or hit F5. You're debugging the Desktop build now!

### Desktop Build controls

| Function | Location on board | Key | Alternate Key | Alternate 2 |
|---:|:---|:---:|:---:|:---:|
| `Move Up` | `Left Stick Up` | `W` | `Arrow Up` | |
| `Move Down` | `Left Stick Down` | `S` | `Arrow Down` | |
| `Move Left` | `Left Stick Left` | `A` | `Arrow Left` | |
| `Move Right` | `Left Stick Right` | `D` | `Arrow Right` | |
| `None` | `Left Stick Center`  | `Q` | | `Numpad 7`  |
| `Hack Entity / +`  | `Right Stick Up` | `I` | `Back(tick/slash)` | `Numpad 8`  |
| `Run / -` | `Right Stick Down` | `K` | `Left Shift` | `Numpad 5`  |
| `Action / Paste` | `Right Stick Left` | `J` | | `Numpad 4`  |
| `Interact / Copy`  | `Right Stick Right`  | `L` | `E/Enter/Return` | `Numpad 6`  |
| `None` | `Right Stick Center` | `O` | | `Numpad 9`  |
| `Toggle HexEditor` | `PCB Capacitive Hat` | `Tab` | `Escape` | |
| `Hex XOR` | `Scren Left, XOR` | `F1` | `Z` | `Numpad 1`  |
| `Hex ADD` | `Scren Left, ADD` | `F2` | `X` | `Numpad 2`  |
| `Hex SUB` | `Scren Left, SUB` | `F3` | `C` | `Numpad 3`  |
| `Hex PAGE` | `Scren Left, PAGE` | `F4` | `V` | `Numpad 0`  |
| `Hex MEM0` | `Screen Right, MEM0` | `F5` | `B` | |
| `Hex MEM1` | `Screen Right, MEM1` | `F6` | `N` | |
| `Hex MEM2` | `Screen Right, MEM2` | `F7` | `M` | |
| `Hex MEM3` | `Screen Right, MEM3` | `F8` | `,` | |
| `Quit game` | `Power switch` | `Alt-F4` | | |
| `Reload game.dat`  | `N/A` | `CTRL-R` | | |
| `Window Size -` | `N/A` | `-` | | |
| `Window Size +` | `N/A` | `+` | | |

Hex Bit keys:

| Bit | 128 | 64  | 32  | 16  | 8 | 4 | 2 | 1 |
|-----|:---:|:---:|:---:|:---:|:---:|:---:|:---:|:---:|
| Key | 1 | 2 | 3 | 4 | 5 | 6 | 7 | 8 |

### Optional - Install Tiled

Tiled (https://www.mapeditor.org/) is being used to edit the game map & character files. If you want to edit these, you'll need to install tiled. (The `wget` isn't grabbing the latest. If you want, download it manually to get the newest version of tiled, but you must use v 1.4.2 or later)

```shell script
cd ~/dev/installer
wget https://github.com/mapeditor/tiled/releases/download/v1.9.2/Tiled-1.9.2_Linux_x86_64.AppImage
chmod +x Tiled-*x86_64.AppImage
sudo mkdir -p /usr/share/tiled/
sudo mv Tiled-*x86_64.AppImage /usr/share/tiled/
sudo ln -s /usr/share/tiled/Tiled-*x86_64.AppImage /usr/bin/tiled
```

You can now run `tiled` in the command line to start Tiled.

### Optional - Install Node.js for an automated CLI build for the game.dat
While it is possible to build the `game.dat` file using only a browser, if you find that you are regenerating this file frequently, it may be very productive to use the CLI build for the `game.dat` file.

```sh
wget -O - https://deb.nodesource.com/setup_22.x | sudo -E bash -
sudo apt install -y nodejs
```

With Node installed, you can `cd SD_Card/MAGE` and execute `./regenerate_dat_file.sh` to regenerate the game.dat file for a very seamless editing workflow.

----

# If you don't have the hardware yet, IGNORE EVERYTHING BELOW THIS LINE

----

## Hardware Build

### Additional Software required for the Hardware Build

- Nordic SDK version 15.3.0
- Nordic nrfjprog
- J-Link segger tools

### Hardware required

- J-Link Segger - $20 edu version works fine:  [Segger](https://www.segger.com/j-link-edu.html), [Adafruit](https://www.adafruit.com/product/3571)
- Header - $1.40: [Mouser](https://www.mouser.com/ProductDetail/Wurth-Elektronik/62201021121/?qs=PhR8RmCirEZWrjKrFMt0Bg%3D%3D)
- A badge!

If you have the bootloader pre-installed, we also support upload of new images via USB, which means that unless you want to change out the badge code you won't need a JTAG programmer. JTAG is useful for debugging, however, and future badges will continue to make use of it, so we recommend that you pick one up.

### Install ARM toolchain for GCC

Unfortunately ARM is no longer supporting the PPA we used to use, so we get to install this manually.
If the link in the wget below doesn't work, you can grab the latest from [ARM's website](https://developer.arm.com/tools-and-software/open-source-software/developer-tools/gnu-toolchain/gnu-rm/downloads)

If you're using a distro other than ubuntu, you'll need to figure out how to install the equivalent paths below.

```shell script
cd ~/dev/installer
wget https://armkeil.blob.core.windows.net/developer/Files/downloads/gnu-rm/10-2020q4/gcc-arm-none-eabi-10-2020-q4-major-x86_64-linux.tar.bz2
export EABI_VERSION=10-2020-q4-major
sudo tar xjf gcc-arm-none-eabi-$EABI_VERSION-x86_64-linux.tar.bz2 -C /usr/share/
sudo ln -s /usr/share/gcc-arm-none-eabi-$EABI_VERSION/bin/arm-none-eabi-* /usr/bin
```

Make sure it works:

```shell script
arm-none-eabi-gcc --version
```
You should see:
```shell script
arm-none-eabi-gcc (GNU Arm Embedded Toolchain 10-2020-q4-major) 10.2.1 20201103 (release)
```

If you see the above, you've got it right.

### Get the Nordic SDK 15

[Download from Nordic](https://www.nordicsemi.com/Products/Development-software/nRF5-SDK/Download#infotabs)

If the link in the wget below doesn't work, head to [Nordic's nRF5 SDK page](https://www.nordicsemi.com/Products/Development-software/nRF5-SDK/Download#infotabs) and select the radio button next to version `15.3.0`. Then at the bottom of the page in a blue box, download just the `.zip` from the link `nRF5_SDK_15.3.0_59ac345.zip`.

```shell script
cd ~/dev/installer/
wget https://nsscprodmedia.blob.core.windows.net/prod/software-and-other-downloads/sdks/nrf5/binaries/nrf5sdk153059ac345.zip
unzip nrf5sdk153059ac345.zip
mv nRF5_SDK_*/ ../nordic-sdk15.3.0/
```

Now you need to configure the SDK for the GCC compiler

Edit the file `~/dev/nordic-sdk15.3.0/components/toolchain/gcc/Makefile.posix`

It should read:
```shell script
GNU_INSTALL_ROOT ?= /usr/bin/
GNU_VERSION ?= 10.2.1
GNU_PREFIX ?= arm-none-eabi
```

_Note_: You might find `\^M` at the end of the lines in the SDK. This is due to DOS line endings being used. UNIX does not use these, so you get control chars instead. It's safe to delete these. Beware that the `\^M` is actually a single char escape - if you paste in the two chars ^ and M you'll end up with a hard to track down error. I recommend removing the `\^M` from any line you edit just to be on the safe side!

Now we are going to test your install. Do this before moving onto the next step, it'll make like easier.

```shell script
cd ~/dev/nordic-sdk15.3.0/examples/peripheral/blinky/pca10040/blank/armgcc
make
```

You should see this output:
```shell script
mkdir _build
cd _build && mkdir nrf52832_xxaa
Assembling file: gcc_startup_nrf52.S
Compiling file: nrf_log_frontend.c
Compiling file: nrf_log_str_formatter.c
Compiling file: boards.c
Compiling file: app_error.c
Compiling file: app_error_handler_gcc.c
Compiling file: app_error_weak.c
Compiling file: app_util_platform.c
Compiling file: nrf_assert.c
Compiling file: nrf_atomic.c
Compiling file: nrf_balloc.c
Compiling file: nrf_fprintf.c
Compiling file: nrf_fprintf_format.c
Compiling file: nrf_memobj.c
Compiling file: nrf_ringbuf.c
Compiling file: nrf_strerror.c
Compiling file: nrfx_atomic.c
Compiling file: main.c
Compiling file: system_nrf52.c
Linking target: _build/nrf52832_xxaa.out
   text	   data	    bss	    dec	    hex	filename
   2072	    108	     28	   2208	    8a0	_build/nrf52832_xxaa.out
Preparing: _build/nrf52832_xxaa.hex
Preparing: _build/nrf52832_xxaa.bin
DONE nrf52832_xxaa
```

If you see that, your toolchain is working, and you can generate binaries with the SDK. Great job!

### Install NRF Command Line Tools

If the link in the wget below doesn't work, head to [Nordic](https://www.nordicsemi.com/Products/Development-tools/nRF-Command-Line-Tools/Download?lang=en#infotabs) and download the latest nRF Command Line Tools for Linux. To do that, switch the platform dropdown to "Linux x86 64", and download the `.deb` file provided. The one that's currently available is named `nrf-command-line-tools_10.24.2_amd64.deb`. Then move it to your installer directory and run the `sudo apt install` line below, changing the filename as necessary.

```shell script
cd ~/dev/installer
wget https://nsscprodmedia.blob.core.windows.net/prod/software-and-other-downloads/desktop-software/nrf-command-line-tools/sw/versions-10-x-x/10-24-2/nrf-command-line-too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
sudo apt install -y --fix-broken ./nrf-command-line-tools_10.24.2_amd64.deb
```

You should see something like this:
```shell script
Reading package lists... Done
Building dependency tree... Done
Reading state information... Done
Note, selecting 'nrf-command-line-tools' instead of './nrf-command-line-tools_10.24.2_amd64.deb'
The following NEW packages will be installed:
  nrf-command-line-tools
0 upgraded, 1 newly installed, 0 to remove and 1 not upgraded.
Need to get 0 B/91.7 MB of archives.
After this operation, 190 MB of additional disk space will be used.
Get:1 /home/<username>/dev/installer/nrf-command-line-tools_10.24.2_amd64.deb nrf-command-line-tools amd64 10.24.2 [91.7 MB]
Selecting previously unselected package nrf-command-line-tools.
(Reading database ... 174554 files and directories currently installed.)
Preparing to unpack .../nrf-command-line-tools_10.24.2_amd64.deb ...
Unpacking nrf-command-line-tools (10.24.2) ...
Setting up nrf-command-line-tools (10.24.2) ...

=============================================================
The J-Link SW and documentation package is required for nrf command line tools to work.
To install the version of J-Link that was tested and verified with nrf command line tools execute one of the following:
sudo apt install /opt/nrf-command-line-tools/share/JLink_Linux_V794e_x86_64.deb --fix-broken
```

Then run,
```shell script
sudo apt install -y --fix-broken /opt/nrf-command-line-tools/share/JLink_Linux_*.deb
```

Let's verify that both the `nrf-command-line-tools` and `jlink` Debian packages installed correctly:

```shell script
JLinkExe version
```

You should see, depending on version:
```shell script
SEGGER J-Link Commander V7.94e (Compiled Jan 15 2024 15:19:58)
DLL version V7.94e, compiled Jan 15 2024 15:19:33

Unknown command line option version.
```

Next, run:
```shell script
nrfjprog --version
```

You should see, depending on version:
```shell script
nrfjprog version: 10.24.2 external
JLinkARM.dll version: 7.94e
```

If you see that, you're good. You have everything you need to program your badge now, how about that?

With that done, go ahead and open VSCode.

You want to install the following plugins: `Cortex-Debug` by [marus25](https://github.com/Marus/cortex-debug.git), `C/C++` by [Microsoft](https://marketplace.visualstudio.com/items?itemName=ms-vscode.cpptools). You do that by pressing Ctrl+P then enter the following one at a time:

```
ext install marus25.cortex-debug
ext install ms-vscode.cpptools
```

Now let's open our badge code in VSCode. `File` -> `Open Folder` -> `Navigate to ~/dev` -> `Highlight BM-Badge` -> `Ok`

At this point, you should be able to build, clean, flash, and even debug with the Segger. Hurray!

# Test Build & Flash

### Badge Build

Here are the steps to compile the badge code for the physical Badge:

- From within VSCode, make sure that the badge code folder is open (if you've followed the steps above, it should be).
- Open a terminal (`Terminal` -> `New Terminal`)
- From within the terminal that appears, run the following (replace `8` with the number of cores your machine has):
```shell script
cd Software/GameEngine/
make cleanall
compiledb make EMBEDDED=1 -j8
```

You should now have everything compiled in the `~/dev/BM-Badge/Software/GameEngine/output` folder.

Let's flash it. Make sure you connect your badge to the J-Link Programmer and power on your badge.

From within the VSCode terminal:

```shell script
compiledb make flash EMBEDDED=1 -j8
```

This compiled and flashed the game engine your badge. You should now have the game running on your badge screen!

To debug you need to open the Run/debug menu on the left (`Ctrl+Shift+D`). It looks like it has a triangle and a bug symbol. At the top, make sure that the dropdown says "Debug (Linux)". Now let's connect the JLink to your Badge. In a new terminal run these commands:

```shell script
JLinkExe
```

You should see:
```shell script
SEGGER J-Link Commander V6.84a (Compiled Sep  7 2020 18:28:09)
DLL version V6.84a, compiled Sep  7 2020 18:27:57

Connecting to J-Link via USB...O.K.
Firmware: J-Link EDU Mini V1 compiled Jul 17 2020 16:25:21
Hardware version: V1.00
S/N:
License(s): GDB, FlashBP
VTref=1.043V

Type "connect" to establish a target connection, '?' for help
J-Link>connect
Please specify device / core. <Default>: NRF52840_XXAA
Type '?' for selection dialog
Device>nrf52
Please specify target interface:
  J) JTAG (Default)
  S) SWD
  T) cJTAG
TIF>s
Specify target interface speed [kHz]. <Default>: 4000 kHz
Speed>
Device "NRF52" selected.

Connecting to target via SWD
InitTarget() start
InitTarget() end
Found SW-DP with ID 0x2BA01477
DPIDR: 0x2BA01477
Scanning AP map to find all available APs
AP[2]: Stopped AP scan as end of AP map has been reached
AP[0]: AHB-AP (IDR: 0x24770011)
AP[1]: JTAG-AP (IDR: 0x02880000)
Iterating through AP map to find AHB-AP to use
AP[0]: Core found
AP[0]: AHB-AP ROM base: 0xE00FF000
CPUID register: 0x410FC241. Implementer code: 0x41 (ARM)
Found Cortex-M4 r0p1, Little endian.
FPUnit: 6 code (BP) slots and 2 literal slots
CoreSight components:
ROMTbl[0] @ E00FF000
ROMTbl[0][0]: E000E000, CID: B105E00D, PID: 000BB00C SCS-M7
ROMTbl[0][1]: E0001000, CID: B105E00D, PID: 003BB002 DWT
ROMTbl[0][2]: E0002000, CID: B105E00D, PID: 002BB003 FPB
ROMTbl[0][3]: E0000000, CID: B105E00D, PID: 003BB001 ITM
ROMTbl[0][4]: E0040000, CID: B105900D, PID: 000BB9A1 TPIU
ROMTbl[0][5]: E0041000, CID: B105900D, PID: 000BB925 ETM
Cortex-M4 identified.
J-Link>
```

To debug you need to open the Run/debug menu on the left (`Ctrl+Shift+D`). It looks like it has a triangle and a bug symbol. At the top, make sure that the dropdown says "Debug (Physical Badge)", and either click the green arrow or hit F5. You're debugging the hardware now!

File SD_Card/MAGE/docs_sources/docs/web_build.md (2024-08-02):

# Web Build

The web build of the Mage Game Engine (MGE) allows you to drag and drop a `game.dat` into your browser window to play test (or play!) any MGE scenario.

As of August 2024, the latest build for the chapter 2 engine is available here: [https://dc801.github.io/BM-Badge/](https://dc801.github.io/BM-Badge/). This may not include the latest `game.dat`, however, so download it from the Black Mage Game repo (or clone it locally) and drag it into the game window.

Save game data persists per `game.dat` file.

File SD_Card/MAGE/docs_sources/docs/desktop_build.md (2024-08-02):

# Desktop Build

The desktop build of the game is limited to Linux at the moment.

You can pull the repo and try to build it yourself, but note that we have prepared a [Linux VM](mge_vm) for your convenience (though it may be out of date).

::: tip Use the web build!
It is our strong recommendation that you use the [web build](web_build) for game testing (and playing) purposes. This is much easier to use!
:::

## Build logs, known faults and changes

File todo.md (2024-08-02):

# todo:

## Game Engine:
- [x] Add tile flipping to render function
- [x] Entities
	- [x] Determine which entity should be player character on map load
- [x] Handle player input
- [x] Add entity render ordering by coordinate of bottom edge
- [x] Add support for entity animation timing
	- [x] Make an array of uint16s that just hold the current frame for entities; it doesn't need to be hackable, just stateful
	- [x] Reset
- [x] Port over the sdl_toy_0 button & LED state emulation
	- [x] Start rendering the background graphic
	- [x] Collect the Button coordinates
	- [x] Render the Buttons
	- [x] Collect the LED coordinates
	- [x] Render the LEDs
	- [x] Handle all inputs for the buttons
	- [x] Toggle the button renderable states when buttons are down
	- [x] Toggle the LED/Boolean values when the buttons are pressed
- [x] Generate a bunch of different WAV files of different sample rates for Dovid
- [x] Port over the Hex Editor
	- [x] Build Monaco 9 as an AdaGFXFont because we need a good monospace font
	- [x] Start rendering the text for the byte grid
	- [x] Render byte selection cursor behind the text
	- [x] Arrows navigate cursor on byte grid when hex editor is open
	- [x] Pass states of currently selected byte to the LEDs
	- [x] Build the entity RAM <-> uint8_t array mapper/typecasting?
	- [x] Build hex ops handler functions
	- [x] Trigger swap of hex ops enum
	- [x] Build hex bit handler functions
	- [x] Trigger hex bit handler to change value of bits on selected byte
	- [x] Build MEM button handler functions
	- [x] Add ability to offset visible page of RAM by pages
	- [x] Render something on screen to see which RAM PAGE you're on
	- [x] Add PAGE handler; Hold page + arrows to jump pages of bytes?
	- [x] Start adding error handling for when indexing outside of supported types ROM data
- [x] Move functions for reading from the ROM into `mage_rom.cpp`
- [x] Create some `get_*_by_index` functions for validating hackable datas
	- [x] getValidEntityId
	- [x] getValidMapId
	- [x] getValidPrimaryIdType
	- [x] getValidTilesetId
	- [x] getValidTileId
	- [x] getValidAnimationId
	- [x] getValidAnimationFrame
	- [x] getValidEntityTypeId
	- [x] getValidEntityTypeAnimationId
	- [x] getValidEntityTypeDirection
- [x] In the ROM header, add a timestamp so we know if the game.dat should be replaced with SD card versions.
- [x] Make a list of some C functions we want scripts to be able to call
- [x] Decide on a common script function signature
- [x] Define an encoding format for scripts
- [x] Adjust entity animation system to allow for multiple actions that can be called from scripts
- [x] Make it so that maps denote a player entity by ID in the game.dat file, and only has ONE or ZERO players per map.
- [x] Change map reset keybind to be XOR+MEM3 and make it work even in dialogs and the hex editor
- [ ] Script system
	- [x] Binary Encoder parts
	- [x] Scripts
		- [x] What is a script?
			- [x] It's a length + sequence of Actions
			- [x] Scripts shouldn't be able to be called when the player has opened the hex editor, but scripts should be able to open the hex editor when called from elsewhere.
			- [x] We'll need entity-based state variables to track pathing and other transient values between ticks.
		- [x] Map
			- [x] onMapLoad(uint16_t scriptId); //called once when the map loads
			- [x] onMapTick(uint16_t scriptId); //called every tick, used for doors, other static events when moving around map.
		- [x] Entity
			- [x] onEntityTick(uint16_t scriptId, uint8_t entityId); //called every tick, entityId is the entity calling that script.
			- [x] onEntityInteract(uint16_t scriptId); //called when the player interacts with the entity
	- [ ] Actions (see mage_defines.h for structs detailing arguments for each action type below:)
		- [x] NULL_ACTION
		- [x] CHECK_ENTITY_NAME
		- [x] CHECK_ENTITY_X
		- [x] CHECK_ENTITY_Y
		- [x] CHECK_ENTITY_INTERACT_SCRIPT
		- [x] CHECK_ENTITY_TICK_SCRIPT
		- [x] CHECK_ENTITY_LOOK_SCRIPT
		- [x] CHECK_ENTITY_TYPE
		- [x] CHECK_ENTITY_PRIMARY_ID
		- [x] CHECK_ENTITY_SECONDARY_ID
		- [x] CHECK_ENTITY_PRIMARY_ID_TYPE
		- [x] CHECK_ENTITY_CURRENT_ANIMATION
		- [x] CHECK_ENTITY_CURRENT_FRAME
		- [x] CHECK_ENTITY_DIRECTION
		- [x] CHECK_ENTITY_GLITCHED
		- [x] CHECK_ENTITY_PATH
		- [x] CHECK_SAVE_FLAG
		- [x] CHECK_IF_ENTITY_IS_IN_GEOMETRY
		- [x] CHECK_FOR_BUTTON_PRESS
		- [x] CHECK_FOR_BUTTON_STATE
		- [x] CHECK_WARP_STATE
		- [x] RUN_SCRIPT
		- [x] BLOCKING_DELAY
		- [x] NON_BLOCKING_DELAY
		- [x] SET_ENTITY_NAME
		- [x] SET_ENTITY_X
		- [x] SET_ENTITY_Y
		- [x] SET_ENTITY_INTERACT_SCRIPT
		- [x] SET_ENTITY_TICK_SCRIPT
		- [x] SET_ENTITY_LOOK_SCRIPT
		- [x] SET_ENTITY_TYPE
		- [x] SET_ENTITY_PRIMARY_ID
		- [x] SET_ENTITY_SECONDARY_ID
		- [x] SET_ENTITY_PRIMARY_ID_TYPE
		- [x] SET_ENTITY_CURRENT_ANIMATION - Encoder needs to lookup animation NAME, not index
		- [x] SET_ENTITY_CURRENT_FRAME
		- [x] SET_ENTITY_DIRECTION
		- [x] SET_ENTITY_DIRECTION_RELATIVE
		- [x] SET_ENTITY_DIRECTION_TARGET_ENTITY
		- [x] SET_ENTITY_DIRECTION_TARGET_GEOMETRY
		- [x] SET_ENTITY_GLITCHED
		- [x] SET_ENTITY_PATH
		- [x] SET_SAVE_FLAG
		- [x] SET_PLAYER_CONTROL
		- [x] SET_MAP_TICK_SCRIPT
		- [x] SET_HEX_CURSOR_LOCATION
		- [x] SET_WARP_STATE
		- [x] SET_HEX_EDITOR_STATE
		- [x] SET_HEX_EDITOR_DIALOG_MODE
		- [x] SET_HEX_EDITOR_CONTROL
		- [x] LOAD_MAP
		- [x] SHOW_DIALOG
		- [x] PLAY_ENTITY_ANIMATION
		- [x] TELEPORT_ENTITY_TO_GEOMETRY
		- [x] WALK_ENTITY_TO_GEOMETRY
		- [x] WALK_ENTITY_ALONG_GEOMETRY
		- [x] LOOP_ENTITY_ALONG_GEOMETRY
		- [x] SET_CAMERA_TO_FOLLOW_ENTITY
		- [x] TELEPORT_CAMERA_TO_GEOMETRY
		- [x] PAN_CAMERA_TO_ENTITY
		- [x] PAN_CAMERA_TO_GEOMETRY
		- [ ] PAN_CAMERA_ALONG_GEOMETRY
		- [ ] LOOP_CAMERA_ALONG_GEOMETRY
		- [x] SET_SCREEN_SHAKE
		- [x] SCREEN_FADE_OUT
		- [x] SCREEN_FADE_IN
		- [x] MUTATE_VARIABLE
		- [x] MUTATE_VARIABLES
		- [X] COPY_VARIABLE
		- [x] CHECK_VARIABLE
		- [x] CHECK_VARIABLES
- [x] Geometry
	- [x] polygon(uint8_t count, x points[count])
	- [x] polyline(uint8_t count, x points[count])
	- [x] point(uint16_t x, uint16_t y)
	- [x] Geometry::inside_poly(point) collision detection function
	- [x] draw() renders geometry to screen
- [x] Collision System
	- [x] For Tiles
	- [!] For Entities
- [x] Dialog Data Type Implementation:
	- [x] Display Name - either stringId, or entityId
	- [x] The actual text to display, probably with line breaks hard coded in to keep things simple.
	- [x] byte to encode position (i.e. is the text on the top or bottom of the screen, is the portrait on the left or right side of the screen, should we display a portrait at all?, etc.).
		- [x] flags for position encoding byte:
			- [x] Top or Bottom
			- [x] Portrait on or off
			- [x] portrait left or right
	- [x] Portraits
		- [x] Encoder
			- [x] Needs new top-level protrait type
			- [x] Needs to store portrait on entityType
			- [x] Dialog
				- [x] Needs to store portrait not associated with entityType on dialog
				- [x] Manually specifyable even if not associated with any entity
				- [x] Needs to store flip_x
		- [x] Engine
			- [x] Should match current entityType of speaking entities
			- [x] Support Entity Hacked state
			- [x] look at dialog alignment, and if it's "RIGHT", toggle flip_x into the flags byte
	- [x] tilesetId and tileId for the portrait picture.
	- [x] Support for string templates that make use of hacked entity names
	- [x] Support for string templates that make use of numeric variables
	- [x] Please stop player walking when a dialog shows
	- [ ] display font
	- [ ] voice sound Id
	- [x] Dialog Responses:
		- [x] response TypeId:
			- [x] NO_RESPONSE = 0
			- [x] SELECT_FROM_SHORT_LIST = 1
			- [ ] SELECT_FROM_LONG_LIST = 2
			- [ ] ENTER_NUMBER = 2
			- [ ] ENTER_ALPHANUMERIC = 3
			- [ ] etc...
		- [ ] Player responses to dialog may be desired:
			- [ ] Assuming pop-up happens while dialog is still active:
				- [x] select from a list of options
				- [ ] enter a numerical value
				- [ ] enter an alphanumeric value (put on-screen keyboard over dialog? Cycle through all letter options like arcade name entry?)
			- [ ] new script and/or dialog to call depending on player response
				- [x] from a list of options
				- [ ] from a numerical value
				- [ ] from an alphanumeric value
		- [x] Show bouncing arrow at bottom of dialog to indicate that the player should press button to continue
	- [ ] Dialog editor:
		- [x] File selector
		- [x] List of Dialogs by name in file
		- [ ] Show the `dialog phases` in a dialog
			- [ ] Add `phase`
			- [ ] Delete `phase`
			- [ ] Preview/edit `phase`
				- [x] Preview message
				- [ ] Select current message
				- [ ] edit message
				- [ ] add message
				- [ ] delete message
				- [ ] text entry for entity name
				- [ ] text entry for entity portrait
- [x] Strings
	- [x] uint16_t Length
	- [x] char array with null termination Length bytes long
- [x] Save system with flags
	- [x] Player Name (12 bytes, like all other entities)
	- [x] On map init, replace player name into PlayerEntity
	- [x] Use bit flags in a specific region of the ROM chip to encode SAVE
- [ ] Allow upload of game.dat to ROM chip using nrfjprog
	- [ ] Convert game.daty into a game.hex file that writes data to address 0x12000000 and up on the ROM chip.
	- [ ] Use qcustominit.ini file added with this commit and the following command to upload:
		- `nrfjprog -f nrf52 --qspiini qcustominit.ini --program <filename>`
		- More info on nrfjprog: https://infocenter.nordicsemi.com/index.jsp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
- [x] Fix name not sticking to player when changing rooms
- [x] Look into why EtherNettles puzzle is not triggering
	- [x] it's probably a modulo issue on tileId and tilesetId
- [x] Make a new dialog tileset that is mostly transparent for the main menu
- [x] Make some background artwork for the main menu
- [ ] Create action for setBackground
- [x] Fix portrait from last conversation being used on dialogScreens that have none
- [x] Remove AnimationFrames to free enough ram to run on Hardware again
- [x] Fix Color palette corruption bug
	- [x] Add corruption detection and logging
	- [x] Now just reproduce it again - what could possibly have been causing this?
		- [x] Turns out it was something indexing into `entities[255]` and mutating that entity - but entities were only allocated to 64. Entities were allocated just before the ColorPalettes.

## Playtesting night notes:
- [x] Text changes: "No! Not Tuesday, T.U.E.S.D.A.Y.!"
- [x] People hit escape to close the hex editor, and it closes the program. Oops. Default it to Alt+F4.
- [ ] An idea: I didn't see anyone saving after completing puzzles. Perhaps after each puzzle is solved, show the save dialog, so nobody loses any progress. Perhaps show this after the TUESDAY cutscene as well.
- [x] We really need to rearrange the Elder's speeches "I'm X, and I do Y" so that it is outside of the lodge. Nobody talked with them out side of the lodge without direction.
- [x] People talk to a lot of objects in the greenhouse, but don't get interactions. Add more interactions there.
- [x] People talked to the quest board, and it said nothing. Oops. Add some dialog.
- [x] There is still a debug exa in the beatrice puzzle room. Oops.
- [ ] After switching delmar from to sheep to man, you can't talk with him. Player expected to talk with him.
- [x] Fix a bug where modulo on the animation always picks (whatever, mage walking north, blitzball) when the currentAnimation is cycled - it glitches across palettes.
	- [x] This is not actually a bug, because the byte changing was primaryIdType. This is expected behavior.
- [?] When you load from the main menu on desktop before you've created a save, it crashes.
- [x] NewGnu tried to set the corrupted byte on the Big Bad Name Book to uncorrupt the name. He was really fixated on learning about that.
	- [x] We should make it do a rot 13 of RED HERRING
- [x] Add Desvio to special thanks
- [x] Add AdwareHunter to special thanks
- [x] Add a book that mentions that you can press XOR and MEM3 to reset the map.
- [ ] Rax asks: Is there a place to snag a copy of the books outside of the game, other than to go parse the source code?
	- [ ] Me: Oh man. Not a bad idea! Perhaps we could release a little "Game Manual" with those! Perhaps a print out that's empty, and they player can fill in the values.
- [x] NewGnu found that if you set the onTick index to the save action, you can write every tick. FRY ROM STORAGE REAL QUICK
	- [x] Solution? Show a "Save completed" dialog after save completes, because then it can only burn through as fast as they can confirm the "Save completed" dialog.
- [ ] Desvio says that Bert should say something different if his name is changed to "Bart" or "Bort" - reference to Simpsons "Who would name a kid Bort" sketch
- [x] If player moves the flowers, Trekkie should yell at the player for uprooting the flowers, and then reset the position of all flowers.
- [x] Talking with the modem should cause the mage to say "Yup, looks like it's not connecting." or "Yay, it's connecting now!"
- [x] When loading a new map, put the hex cursor back at the player
- [x] There is a table tile that is on layer 3 in the inner sanctum, but the rest of them are below?
- [!] Possibly redesign the layout of the sheep quest so that the pen is not obscured by the old lady's house.
- [x] NewGnu tried to glitch the pipscat so it was in the where the cat construction crew was. Very reasonable. Should this be an alternate solution?
	- [x] I think that this should be countered with "When the cat is glitched off their stump, he should automatically walk back to the point where he started."
- [x] During CorfidBizna's playthrough, she triggered a "fade to black" script, and reloading the map didn't make things playable again.
	- [x] To fix, LoadMap should set fadeFraction to 0
- [x] Fix the ???Mystery Sink??? in the player's house?!?
- [x] Each of the members of the cat construction crew should say something different to the player when they are the PipsCat
- [x] The path leading north of the Library should take the player to an "UNDER CONSTRUCTION" zone, saying something about how it's not ready yet.
- [ ] The wrap-around at the bottom of the map should fade out and then in again
- [x] Re-do the handling of the right side buttons when in the HexEditor
	- [x] Create Clipboard system
		- [x] Create a buffer that is sizeof(MageEntity)
		- [x] A value to indicate the length of what's on the clipboard
		- [x] Display current clipboard value in header or footer, truncated to 4 bytes and '...'
		- [x] Copy method
		- [x] Paste method
			- [x] When your paste changes the entityType AND position, it doesn't move to the pasted location for the first tick because the "Did the tile size change this tick" entity jump protection kicks in
		- [x] Store the clipboard value + length into save file as well
	- [x] △ should increment the current byte's value by 1
	- [x] ◯ should copy the current byte's value into the copy buffer
		- [x] while holding ◯, moving the left/right arrows will select additional cells
	- [x] ✕ should decrement the current byte's value by 1
	- [x] ◻ should paste the copy buffer into the current byte's value
	- [x] The value +/- operations should be slowed down
	- [x] The "triangle to open on an entity + cooldown before normal hex operation" should actually restore normal hex control via "on release handler"
- [x] Add an action to enable/disable copy & paste. It's too powerful to start the game with; Perhaps it is granted by an artifact from a dungeon in 2021?
- [ ] Re-do the handling of the MEM buttons in the HexEditor
	- [x] Make the addresses stored relative to the currently selected entity
	- [x] How to set relative MEM addresses?
		- [x] Hold PAGE and press MEM* to set
		- [ ] Long-Hold MEM* to set?
	- [x] Press MEM* to move cursor there, both in and out of the editor
	- [x] Store your 4 MEM addresses into the save file as uint8_t, because MEMs are now relative
- [x] Prepare scenario data for bootloader's USB-C/magic drive update flavor
	- [x] `game.dat` gets a new header:
		- [x] `MAGEGAME`
		- [x] uint32_t CRC32 of the `game.dat` before the CRC32 is added
		- [x] uint32_t length of `game.dat`
	- [x] `save_[0,1,2].dat` gets a new header:
		- [x] `MAGESAVE`
		- [x] uint32_t CRC32 from `game.dat` (so we know if versions match)
		- [x] uint32_t length of the `save_[0,1,2].dat`
- [x] Improve the "Power on" experience of the hardware
	- [x] ROM _is_ valid,
		- [x] and SD _is not_ present, start game
		- [x] and SD _is_ present, hash is same, start game
		- [x] and SD _is_ present, hash is diff, show options
		- [x] and SD _is_ present, MEM3 is held, show options
	- [x] ROM _is not_ valid,
		- [x] and SD _is not_ present, engine panic with message about no rom
		- [x] and SD _is_ present, _do not_ show options and just copy
	- [x] Desktop build should also ENGINE_PANIC if ROM Magic is bad
- [ ] Entity "Action" animation continues playing during dialog but only sometimes
- [ ] Entities go to space when the duration of a walk path is less than the milliseconds per frame of the current fps
- [x] Hamster has a bug report. The save icon's background dialog tileset is missing.
- [x] Use entity property `is_debug` (true) to make certain entities "Debug mode only"
	- [x] Set the "Warp Fish" `is_debug` true
	- [x] Set the Exa `entity_type` property `is_debug` true by default
	- [x] Add kaitai `render_flags` type to entity instance direction help show what's up
	- [x] Make encoder set the `0b0100000` renderFlags so those entities can be filtered out at runtime
	- [x] In engine, implement runtime "show debug entities" mode
		- [x] Add `is_debug` for `0b0100000` bit on renderFlags
		- [x] Pick a key combination to toggle this mode
			- [x] Pressing the key combination reloads the current map and disables the filter
		- [x] Filter the entities by the `0b0100000` renderFlags, while tracking the original + filtered entityId
			- [x] Make an array that maps `mapLocalEntityId` to `filteredMapLocalEntityId`
			- [x] Change the getEntity* methods to use this
		- [x] Diligence:
			- [x] Review all usages of `MAX_ENTITIES_PER_MAP`
			- [x] Review all usages of `map.EntityCount()`
			- [x] Review all usages of `entities[`
			- [x] Review all usages of `entityRenderableData[` -> `getEntityRenderableDataByMapLocalId`
			- [x] Review all usages of `filteredMapLocalEntityIds`
			- [x] Review all usages of `mapLocalEntityIds`
			- [x] Review all usages of `playerEntityIndex`
			- [x] Review all usages of `cameraFollowEntityId`
			- [x] Make sure that entity hacking still doesn't jank the player
			- [x] Make sure that camera wiggle functions still work
			- [x] Test it on the hardware
- [x] Make a "Warp Zone" map that can take players to all of the debug maps
	- [x] Make the "Warp Fish" send the player the "Warp Zone"
	- [x] Add the "Warp Fish" fish to all the debug maps
- [x] Fix bug where loading an un-initialized save doesn't start with default values
- [x] In the Dialog, when there are choices, the cursor will loop to the top when you press the down arrow, but not when pressing up from the top item, but it should
- [x] Purge all the actions that didn't get implemented
	- [x] PAUSE_GAME
	- [x] PAUSE_ENTITY_SCRIPT
	- [x] PLAY_SOUND_CONTINUOUS
	- [x] PLAY_SOUND_INTERRUPT
	- [x] SET_HEX_BITS
	- [x] LOCK_HAX_CELL
	- [x] UNLOCK_HAX_CELL
	- [x] Now playtest the game
- [x] Add a proper encoder enum for property `button_id` so you can refer to buttons by name
- [x] Add support for the elusive `any key` to the button handlers
- [x] Change `CHECK_ENTITY_PATH` to use `geometry` instead of `expected_u2`

## Development VM TODO:
- [ ] Set the XFCE GUI "theme" to dark mode
- [ ] Set the VSCode default "debug" script to "Debug desktop"
- [ ] Add a few bookmarks to the browser
	- [ ] Github repo
	- [ ] ide.kaitai.io
		- [ ] pre-load the mage_game.ksy into kaitai

## Web Build TODO:
- [x] Get it to be playable in the browser, at all
- [x] Desktop build should be able to "ctrl-r/refresh" the `game.dat` from filesystem
- [x] Default `game.dat` should be cached between refreshes
- [x] User should be able to drag in a `game.dat` and play it
	- [x] Verify that the header of dragged file contains `MAGEGAME`
	- [x] Change of `game.dat` should call the `EngineInit` function and reload contents from virtual filesystem
	- [x] Reloading the page starts game fresh from original `game.dat` in IndexedDB
- [x] !!!CRITICAL!!! Make HTTP HEAD request for `game.dat` on server, compare size/modification to local, and re-download on change
- [ ] Fancy extra `game.dat` features
	- [ ] The dragged-in `game.dat` should be cached between refreshes
	- [ ] Should show the Path/CRC32/Length of each `game.dat`
	- [ ] Display a list of the available `game.dat` files, filenames + CRC32
		- [ ] Original
		- [ ] Each dragged version
		- [ ] Multiple endorsed scenarios(?)
	- [ ] Add ability to erase a dragged file from that list
- [x] Save files should persist between refreshes
- [ ] Add Web Build setup instructions to `EnvironmentSetup.md`
- [ ] Add Web Build env config to the public dev VM
- [x] Add public link to main `README.md`
- [ ] Add usage instructions to content authoring documentation
- [ ] Find a way to display the `ENGINE_PANIC` screens in Emscripten before we get into the main loop, otherwise the browser gets stuck in a broken infinite loading state where the screen doesn't display at all
- [ ] Add collision detection to the EngineWindowFrame so a player can click on GUI buttons
	- [ ] Implement easiest possible click + release of buttons
	- [ ] Add ability to start dragging off a button, and then on to trigger a "press"
	- [ ] Add ability to start dragging on a button, and then off to trigger a "release"
	- [ ] Add multi-touch support for phones

## Encoder TODO:
- [x] Throw error when > 1 entities have `is_player`
- [ ] Build a test map with no entities and make sure it does not crash
- [x] Fix bug where empty string for script on map or entity does not encode as null_script
- [ ] Music/SFX encoding in the binary asset encoder
- [ ] Error for missing json file at path in encoder is not explicit enough - should show which file it was not able to find

## Hardware TODO:

- [x] Get keyboard chip working and reliably updating button states
- [x] Get LED control chip working and update LED control functions
- [x] Update FrameBuffer.h to work with the new larger screen
- [x] Use SD card for testing game until ROM chip is functional
- [x] Get ROM chip read/write working reliably
- [x] Verify function of all desktop testing build features are working correctly on badge hardware
- [ ] Fix audio driver and initialize communication with audio chip

# MAJOR GAMEPLAY AND QUEST SPOILERS BELOW!

## Assets we need
- [x] More villagers
	- [!] One of the children's actions should be a sneeze
- [x] The other mystical artifacts, which do _not_ pick the mage
- [x] Ring Zero, spinning
- [ ] Chicken
- [ ] Sparkles that could be overlayed on anything to draw attention
- [x] Character Portraits for the Dialog system
	- [!] Mouth open, closed
- [x] The Quest Board tiles
- [x] The 9-slice image for "Quest List" screen
- [x] The 9-slice image for dialog borders
- [x] Tiles for the inside of village houses
- [ ] Tiles for Dungeons
- [x] Set Dressing
	- [x] Bed
	- [x] Flower Pots
	- [x] Windows
	- [x] Kitchen table
	- [x] Kitchen chairs at table
	- [x] Pots
	- [ ] Interior Doors for all 4 walls
	- [x] Fireplace
	- [x] Shelves with things on them
	- [ ] Fruits on table
	- [!] Fence Posts to paint, so we need 2 states
	- [ ] Dancy Flowers
	- [x] A rake, for the lake
- [!] A knob that has never turned, but must be turned to get the fountain to turn on again
- [!] A well, for Timmy to get stuck in
- [ ] Tiles for village elder's basement/dungeon
- [x] Bender + shiny metal ass

# 2022 big picture objectives
- [x] How to version the game.dat and the engine together?
	- [!] Programmatically? No, the security boundary of the browser `file://` path prevents us from reading the `mage_dat.ksy`
	- [x] Manually? Yes, just update the docs for "Adding new actions" to manually include a data file version in these places
		- kaitai
		- encoder
		- c code decoder
	- [x] Add data version to kaitai
	- [x] Add data version to encoder
	- [x] Throw error on mismatch in C
	- [x] Fix web build issues with infinite loop in the `ENGINE_PANIC` screen
	- [x] Add the docs to the actions update instructions
- [ ] New actions
	- [x] `SET_CONNECT_SERIAL_DIALOG` (serial_dialog_id)
	- [ ] `SHOW_SERIAL_DIALOG` (serial_dialog_id)
		- [x] Output text
		- [x] Sanitize & handle input
	- [ ] `INVENTORY_GET` (item_name)
	- [ ] `INVENTORY_DROP` (item_name)
	- [ ] `CHECK_INVENTORY` (item_name, expected_state, success_script)
	- [ ] `SET_MAP_LOOK_SCRIPT` (script_name)
	- [ ] `SET_ENTITY_LOOK_SCRIPT` (entity_name, script_name)
	- [ ] `SET_TELEPORT_ENABLED` (bool_value)
	- [ ] `CHECK_MAP` (map_name, expected_state, success_script)
	- [ ] `SET_BLE_FLAG` (flag_constant_name, bool_value)
	- [ ] `CHECK_BLE_FLAG` (flag_constant_name, expected_state, success_script)
	- [!] Don't implement because this introduces more state to track. Item use/look scripts will be stateless like the map go scripts
		- [!] `SET_ITEM_LOOK` (item_name, script_name)
		- [!] `SET_ITEM_USE` (item_name, script_name)
- [ ] Add numeric "constants" support to encoder
- [ ] Serial Dungeon
	- [ ] Create a new `maps.json`; Maps are named keys full of objects:
		- [x] `path` example "maps/map-main_menu.json"
		- [x] `on_tick` script
		- [x] `on_load` script
		- [x] `on_look` script
		- [ ] `items` is an array of strings that map to global item names
		- [x] `directions` is an object of `"direction_name": "script_name"`, so `go $DIRECTION` calls a script
			- JSON looks like:
				```
				directions: {
					north: 'go_main_hall_north',
					east: 'go_torii_gate',
					south: 'go_goat_room',
					west: 'go_west_room',
				}
				```
	- [x] Map struct changes
		- [x] `on_look` script
		- [x] `script_padding` 2 bytes
			- [x] Change the encoder to handle this new shape
			- [x] Update the kaitai struct
			- [x] Update the C
		- [x] `direction_count` uint8_t
		- [x] `directions` is an array, so `go $DIRECTION` calls a script
			- [x] `name` 12 bytes script ids,
			- [x] `script_id` 2 bytes
			- [x] `padding` 2 bytes to get us back into 16 alignment
	- [ ] Entity struct changes
		- [ ] `on_look` script, stored in bytes 30 & 31
	- [ ] Action `setEntityScript` needs some TLC and testing for setting look scripts
	- [ ] New Item struct - managed in `items.json`
		- [ ] There may not be more than 64 items in the whole universe
		- [ ] 16 of these items need to be held in ram because the scripts need to be mutable to allow branching
		- [ ] When you load map, loop through the `ItemLocationArray` and load items in the room, or in player inventory, into 1 of 16 slots in ram
		- [ ] Struct details
			- [ ] `name` 12 chars
			- [ ] The following script IDs are GLOBAL SCRIPT IDS because they can be run from ANY room!
				- [ ] `on_look` script ID
				- [ ] `on_use` script ID
	- [ ] New ItemLocationArray
		- [ ] Part of the save struct
		- [ ] It's an array of 64 long, matching the `items` limit
		- [ ] 2 bytes per item `current_location` value
			- [ ] 0x0000 means nowhere
			- [ ] 0x0001 0xFFFE means it's on a map
			- [ ] 0xFFFF means it's in the player's inventory
	- [ ] Web build should get a toggleable "console" area below the gameplay window, that basically looks like the `text_based_adventure_prototype`
	- [ ] Text based adventure
		- [ ] Player loses control over the joysticks and things are instead done over the serial CLI
		- [ ] Serial command processing system
			- [ ] Complete list of possible command formats
				- [ ] Verb: 'look', 'inventory' 'help'
				- [ ] Verb, Target: 'look flask', 'get flask', 'go north'
			- [ ] Verbs to implement
				- [ ] help - shows a list of available commands and their syntax
				- [ ] look - Without an argument, runs the current room's `on_look` script, or a fallback to "There is nothing here but sadness". If there is an argument, looks to the items in that room, and then the inventory to try and find an item with a matching name.
					- [x] Implement execution of `on_look` script
					- [x] Implement listing of available directions
					- [ ] Implement listing of items on map/in room
					- [ ] Implement running `on_look` for items
					- [ ] Implement running `on_look` for entities
					- [ ] If `teleport` is enabled, the `on_look` output is prefixed with the name of the room that the player is in
				- [x] go - Looks up the `directions` in the current room, and if there is one that matches the second argument, runs the script for going that direction
				- [ ] get/take
				- [ ] drop/yeet
				- [ ] inventory - Shows the names of current inventory items
				- [ ] use - runs the item's `on_use` script from any item in the current room, or your inventory
				- [ ] teleport - allows you to teleport to any room that you know the name of. This functions as a "fast travel" after you have built the server. Becomes enabled via a specific flag like the Hex Editor.
		- [ ] The tileset actually just looks like a Zelda MiniMap
			- [ ] https://nucloud.com/wp-content/uploads/2018/12/zelda-dungeon-maps.png
		- [ ] This dungeon can has an inventory system
		- [ ] What powers do the Serial artifact give you?
			- [ ] Having an inventory at all
			- [ ] Teleport - if you know the name of a room anywhere in the game, you can type `warp $ROOM_NAME`
		- [ ] The end goal of the Serial Dungeon + having inventory
		- [ ] We need an interactive character named PuTTY
			- [ ] It should be illustrated or described as a Morph suit like the PUTTYs from Power Rangers
	- [ ] You need to be able to build a ~~PC~~ Server from multiple components found in the Serial Dungeon
		- [ ] In the story, you need to build a server so that you can access/use the serial commands outside of the serial dungeon, and progress in the game by finding secret parts of rooms you've already been in with the `look` command.
		- [ ] You need a Case
		- [ ] You need a Motherboard
		- [ ] You need a Power Supply
		- [ ] You need a CPU
		- [ ] You need RAM
		- [ ] You need a Keyboard - but you can only find a Keytar, or a midi-enabled Button Accordion with a midi to USB keyboard adapter
		- [ ] There's a cat, and you need to convince it to give you its mouse
		- [ ] There's a Bitcoin Mine, and you need to convince them to stop burning down the planet and free the video cards
		- [ ] When you have all of the components are ready, the EXA says: `Now all we need is a Banana, and some Hope!`
			- [ ] Procure Banana
			- [ ] Procure Hope
			- [ ] In the end, the `hope` doesn't help, and you must resort to `percussive maintenance` to get the server to turn on
- [ ] Filesystem Dungeon
	- [ ] Figure out how to create a USB Mass Storage disk from of the contents of like 4KB of RAM.
		- [ ] Use a super tiny block size.
	- [ ] Serial command `mount` will cause Mass Storage device to mount
	- [ ] Serial command `open` will uhh... invoke a file on the virtual FS
		- [ ] Somewhere there should be a `sesame.sh`, and `open sesame.sh` should solve that puzzle
	- [ ] A chmod/chown puzzle.
		- [ ] Enemy dies. drops weapon on to the FileSystem.
		- [ ] Player can't pick up weapon because its permissions are wrong.
		- [ ] Chmod/chown that file/weapon. Now player can pick it up, enemy can't.
- [ ] Uhhh more Hex Dungeon
	- [ ] Change the layout of the dungeon from spelling `FF` to `0x` because that's more awesome.
	- [ ] Perhaps unlock/add more in-game memory than just the entity structs for the HexEditor?
- [ ] When the player approaches a puzzle that they have not seen before, we should blink the light on the board that corresponds to the interface used to solve that puzzle

### Story ideas
- [ ] After you have all of the artifacts, someone/something should steal them.
	- [ ] Hacking the save file to restore your artifacts
- [ ] When you are directed to go get the 3 artifacts, it is super easy to go get them.
	- [ ] Then when you give them to SPOILERS, everything goes terrible.
	- [ ] They are teleported back into the dungeons, but much deeper, and you have to go the long way to get them back

### Puzzle ideas
- [ ] There's an exit somewhere in a forest that you can't get to any way other than being in that room, but using serial to `go $SECRET_ROOM_NAME` when you're in there
- [ ] There's a sleeping Snorlax blocking your path in one of the forests.
	- [ ] You need the inventory system so that you can cary an otamatone to play music and wake him up.
- [ ] A floor might be on fire. The player has to turn off the "firewall" to cross that part.
- [ ] Liar'sville puzzle. Start unsolveable. Two black-hats
	- [ ] Must change one of the color of one of their hats so at least one tells truth
- [ ] You need to read a value from Bluetooth to open a certain door?

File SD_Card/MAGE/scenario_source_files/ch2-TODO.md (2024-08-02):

# TODOs #

## Brainstorming ##
**puns**
* "We all make mistakes but you just need to solder on"
* "I hate talking to ___ They always give me the cold solder."
* "go flux yourself."
* "Have you tried turning it off and turning it back on again?"
* "Hey you found a mouse, don't let it byte you"
* Favorite singer: "A Dell"
* Band name: 1023 megabytes, (they havent had a gig yet)
* gold phish (evil Mr. Tickles)
* characters who have been "poped off the stack"
* Refer to things as "fragmented" (maybe in filesystem dungeon)
* symlink pun (maybe they lost the symlinks for the doors?)
* BIOS
* TPM 2.0
* CMOS (seamoss) battery
* Weird Intel code names for sockets and such
* Its always DNS
* "If you don't think its DNS, its probably DNS."

**Ideas**
* Collect cpu cores in the dungeon
* SATA something something fire.
* Castle north bridge and south bridge
* Time is a problem

## Assets ##
- [ ] Cactus Cooler liquid cooler fan thing
- [ ] Install Wizard (Raccoon in cape)
- [ ] Castle IT people
- [ ] Soldering iron
- [x] Doritos Ram chips
- [ ] Computer mouse (rodent)
- [ ] Ram ram?
- [x] Rock band to steal keyboard from
- [ ] Other bad puns
- [x] Some kind of physical clock

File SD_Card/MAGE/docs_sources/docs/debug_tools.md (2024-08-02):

---
prev: mgs/advanced_syntax.md
---

# Debug Tools

## Debug Mode

Debug mode is triggered in-game by pressing `XOR` and `MEM1` (the top button on the left of the screen and the second button on the right) at the same time. On desktop: press `F1` and `F6` instead. This counts as a [map reload](map_loads).

Turn off debug mode in the same way.

### Debug Entities

Normally, the Mage Game Engine (MGE) omits [entities](entities) with the `is_debug` value of `true` when loading [maps](maps). Such entities effectively do not exist in "production mode," and therefore will not be included in the list of entities in the [hex editor](hex_editor), will not appear anywhere on the map, cannot be the target of [script](scripts), etc. (#verifyme) When debug mode is activated, however, the [current map is reloaded](map_loads) with `is_debug` entities included.

The chapter 1 version of the engine *must* use debug entities to trigger debug scripts, as the serial [terminal](terminal) was not implemented yet, and there was not yet an action to check whether debug mode is on.

::: tip Best Practice
When making debug entities, it helps a lot to give them dialog describing what they are doing to change the game state. Better still is putting the debug behavior behind a [multiple choice dialog](dialogs#options) so that the debug entity can be disengaged without making any changes in case it is ever engaged by accident.
:::

### Debug Scripting

With [CHECK_DEBUG_MODE](actions/CHECK_DEBUG_MODE), you can add additional behavior to your game that is easy to enable when play testing but hidden from players by default.

#### Debug Logging

The [`debug!()` macro](mgs/advanced_syntax#debug) was introduced to provide the same behavior but in a much briefer form:

```mgs{2,3,4,6}
script {
  if (debug mode is true) {
    show serial dialog { "DEBUG INFO!" }
  }
  // these are equivalent
  debug!("DEBUG INFO")
}
```

#### Debug Commands

You can register debug [commands](commands) in a map's [`on_load`](script_slots#on-load), and if you put these registrations behind a check for debug mode, they won't get in the way of a play tester's experience.

We've found it useful to include debug logging when such a command is registered — both the name and a brief description of what the command does — so you won't have trouble remember which commands you've prepared for a given map.

### Debug Techniques

#### Cutscene Skippers

When debugging later segments of the game, it's helpful to be able to trigger a script that bypasses otherwise-mandatory [cutscenes](techniques/cutscenes). Such debug scripts should carefully mirror their real counterparts in terms of [save flags](variables#save-flags) set and the like, or you might find yourself having to debug the debuggers.

#### Cutscene Restorers

Likewise, it sometimes helps to be able to play a cutscene over again. Or, if most or all [cutscenes](techniques/cutscenes) have been bypassed, it helps to turn on a specific one separately.

#### Clean Wipe

When using scripts to emulate a fresh game state, be sure you have a good list of the [save flags](variables#save-flags) and [integer variables](variables#integer-variables) (etc.) you have been using.

#### Puzzle Solvers

While some puzzles can be simplified to accelerate play testing (such as naming the main character "Bub" when they will later need to be named "Bob"), it's much faster to make scripts to solve puzzles for you.

By the end of game development of Chapter 1 of the Black Mage Game, there was a "Debug Exa" capable of solving or partially solving the majority of puzzles.

#### Choreography Controller

Whenever you have a small segment of choreography you want to polish, it helps to split the sequence into a separate script that you can trigger at will.

## Vector View

One of the in-game debug tools, triggered by pressing `XOR` and `MEM0` (the top two buttons on each side of the screen) at the same time. On desktop, press `F1` and `F5` instead.

NOTE: Currently, vector view cannot be toggled when [hex editor](hex_editor) [control](actions/SET_HEX_EDITOR_STATE) is off.

### Visible Vectors

#### Vector Objects

[Vector objects](vector_objects) include:

- vector paths
- vector shapes
- vector points (displayed as Xs)

These lines are green ordinarily, but will turn red if the player entity is "inside" them.

#### Entity Vectors

Entity hit boxes are half the length and half the height of the [entity](entities)'s tile size, and are positioned at the bottom-center of the sprite. This box is green by default, but the entity that was most recently [interacted](script_slots#on-interact) with (either with the interact button or hack button) will have a red hitbox instead.

The entity's position is considered to be the center of its hitbox as defined above, and is marked by a blue X.

#### Interaction Hitboxes

When the player presses the hack button or [interact](script_slots#on-interact) button, a rectangle is cast in front of the player entity. After a successful interaction, the hitbox will be blue, and will be yellow otherwise.

#### Collision Vectors

Tiles on the map will have their [vector collision shapes](tilesets#tile-collisions) drawn in green, unless the engine has determined they are close enough to the player that collision for that tile will need to be checked, after which they will be drawn in yellow. Red lines indicate a collision was detected on that tile.

The player's collision spokes (drawn in purple) are projected in front of the player entity. When they cross a tile's collision geometry, a collision is detected, and the corresponding knockback vector is drawn as a red line extending in the opposite direction.

#### Collision Details

In the upper-left corner of the screen is a more detailed view of the actual math behind the collision algorithm. Map makers creating original scenarios can safely ignore this part of vector view.

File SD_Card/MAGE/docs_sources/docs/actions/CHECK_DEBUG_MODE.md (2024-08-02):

# CHECK_DEBUG_MODE

Checks whether [debug mode](../debug_tools#debug-mode) is currently on.

## Example JSON

```json
{
  "action": "CHECK_DEBUG_MODE",
  "expected_bool": true,
  "success_script": "successScript"
},
{
  "action": "CHECK_DEBUG_MODE",
  "expected_bool": true,
  "jump_index": 12
}
```

## MGS Natlang

The [condition](../conditional_gotos) portion of this action can be used inside an [if](../mgs/advanced_syntax#if-and-else) condition statement, e.g.

```mgs
script {
  if (debug mode is true) {}
}
```

### Examples

```mgs
script {
  if debug mode is true then goto successScript;
  if debug mode is true then goto index 12;
  if debug mode is true then goto label labelName;
}
```

### Dictionary entries

```
if debug mode is $expected_bool:boolean
    then goto (script) $success_script:string (;)

if debug mode is $expected_bool:boolean
    then goto index $jump_index:number (;)

if debug mode is $expected_bool:boolean
    then goto label $jump_index:bareword (;)
```

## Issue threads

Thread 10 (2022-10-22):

Dialog label bug

alamedyang, 2022-10-22:
Dialog labels will appear to be blank for non-player entities if they are first in the entities array (in a map).

Issue can be found at this commit: f02bcddbc9ec696f455d45c041fc0f72f226b535

Using this configuration of entities (this is the state of the commit):

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

Yields this output:

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

Whereas this configuration:

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

Yields this:

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

alamedyang, 2024-01-29:
Fixed in commit 4641bd2c51feea8035b38bacffbae98243b9cab1

Closed 2024-01-29.

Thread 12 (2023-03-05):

Interlaced frames to improve performance

MooseTheGoose, 2023-03-05:
The Nordic nRF52840 has 32 MHz SPIM interfaces to communicate with the ILI9341 display, which requires us to send 16 (per color) * 320 (per pixel) * 240 (per row) bits. This means that, at minimum, updating the entire display takes

((16 * 320 * 240 bits) / (33554432 bps)) =  0.03662 seconds = 36.62 ms.

However, there is a trick called [Interlacing](https://en.wikipedia.org/wiki/Interlaced_video) that does not require us to only update half the screen. There's precedence for it being used in [video game consoles](http://nerdlypleasures.blogspot.com/2017/10/the-rise-of-interlacing-in-video-game.html) as well.

If you look at the links above, you'll see interlacing does not come without its problems, but the performance gains may be worth it, especially because we output video in real-time rather than still images. It would cut down frame update times from 36.62 to 18.31 ms.

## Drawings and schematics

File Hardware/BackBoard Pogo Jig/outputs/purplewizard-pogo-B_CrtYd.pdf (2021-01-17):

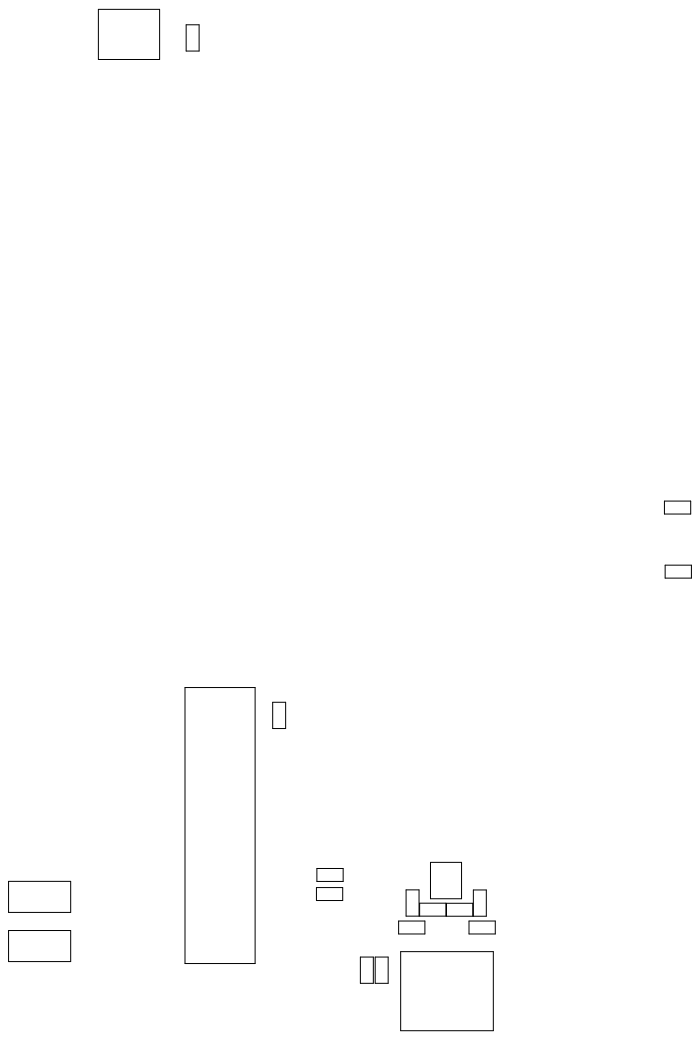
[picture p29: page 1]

@hamster and the dc801 badge team

codename purplewizard
D Date: 2021-01-15 KiCad E.D.A. kicad (5.1.9)-1
File: purplewizard-pogo.kicad_pcb Sheet: DC801

Id: 1/1 Title: DC801 Badge - BM Pogo Fixture

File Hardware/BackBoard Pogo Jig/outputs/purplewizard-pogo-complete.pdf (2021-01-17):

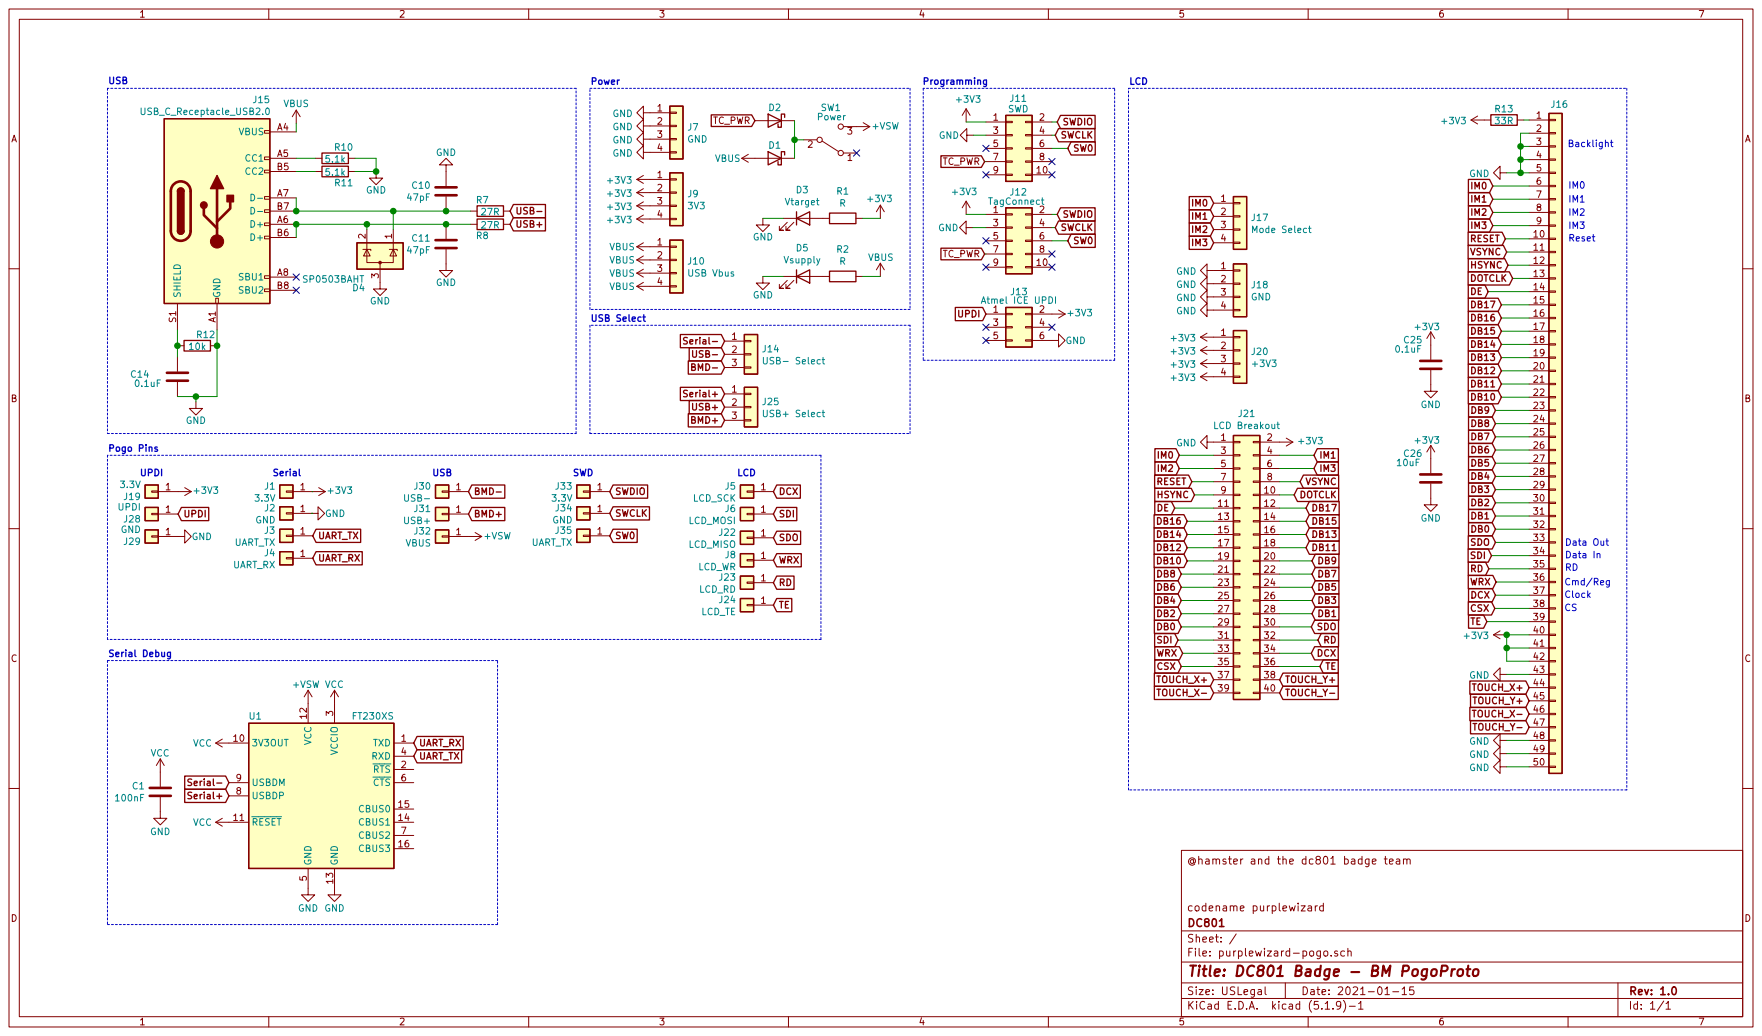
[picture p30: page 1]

J10 USB Vbus GND GND GND GND

@hamster and the dc801 badge team

codename purplewizard
File: purplewizard-pogo.sch Sheet: / DC801

Id: 1/1 Title: DC801 Badge - BM PogoProto


@hamster and the dc801 badge team

codename purplewizard
D Date: 2021-01-15 KiCad E.D.A. kicad (5.1.9)-1
File: purplewizard-pogo.kicad_pcb Sheet: DC801

Id: 1/1 Title: DC801 Badge - BM Pogo Fixture

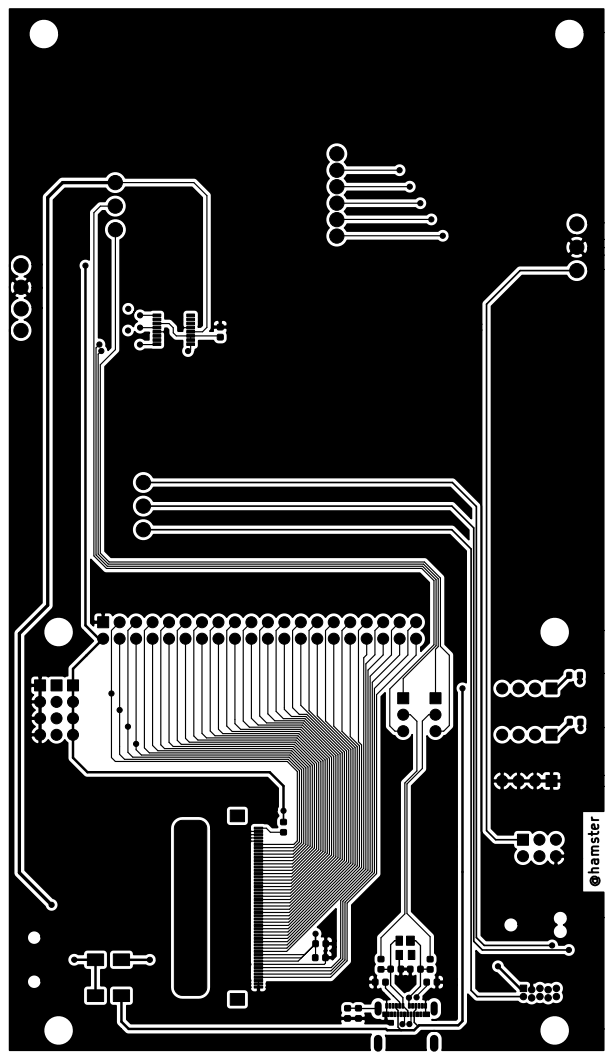
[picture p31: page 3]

@hamster and the dc801 badge team @hamster

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

Id: 1/1 Title: DC801 Badge - BM Pogo Fixture

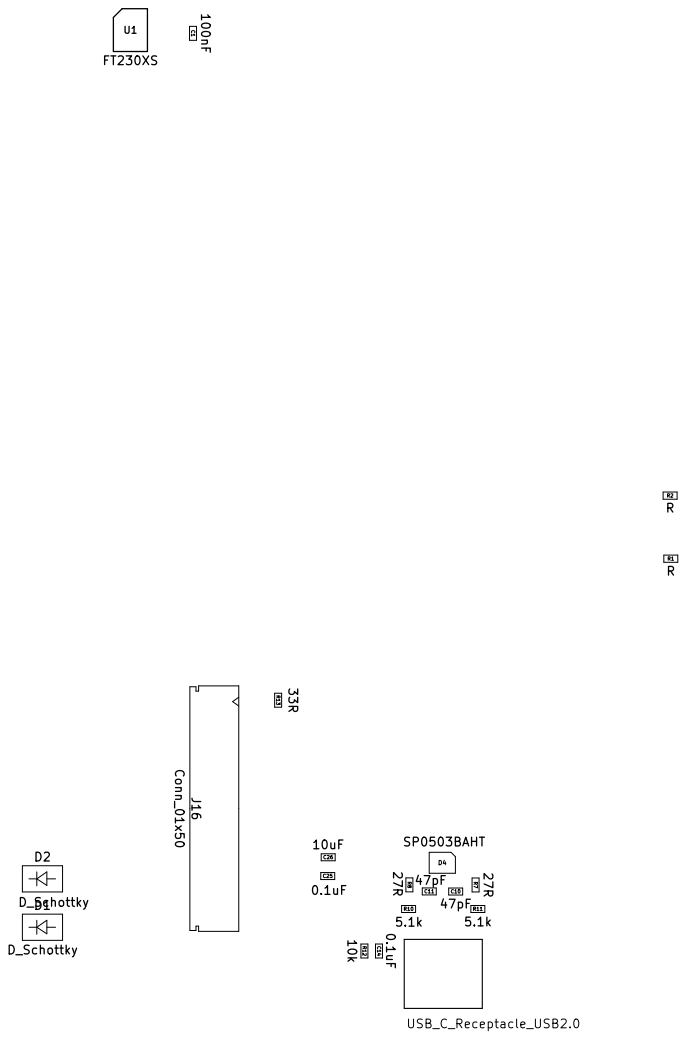
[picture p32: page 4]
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

Id: 1/1 Title: DC801 Badge - BM Pogo Fixture

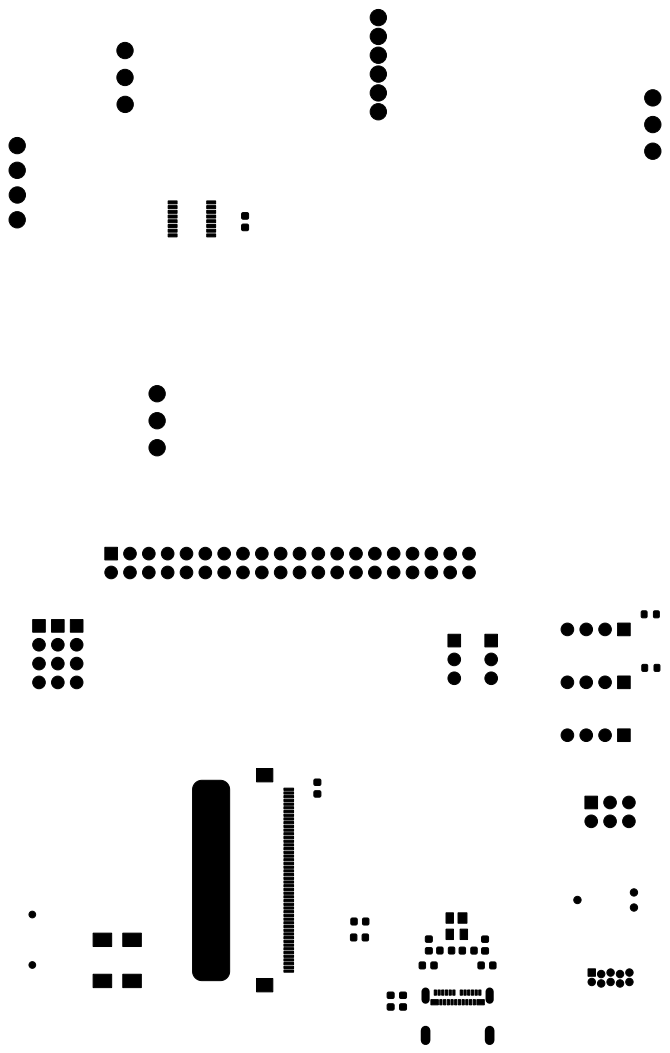
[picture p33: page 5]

@hamster and the dc801 badge team

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

Id: 1/1 Title: DC801 Badge - BM Pogo Fixture

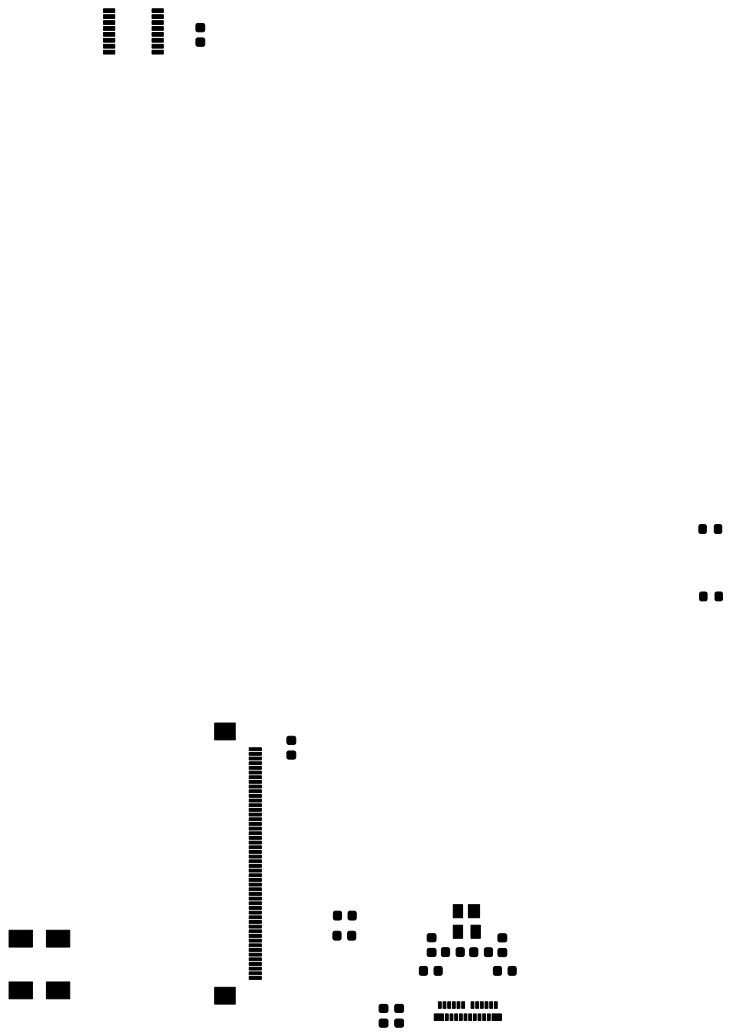
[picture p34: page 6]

@hamster and the dc801 badge team

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

Id: 1/1 Title: DC801 Badge - BM Pogo Fixture

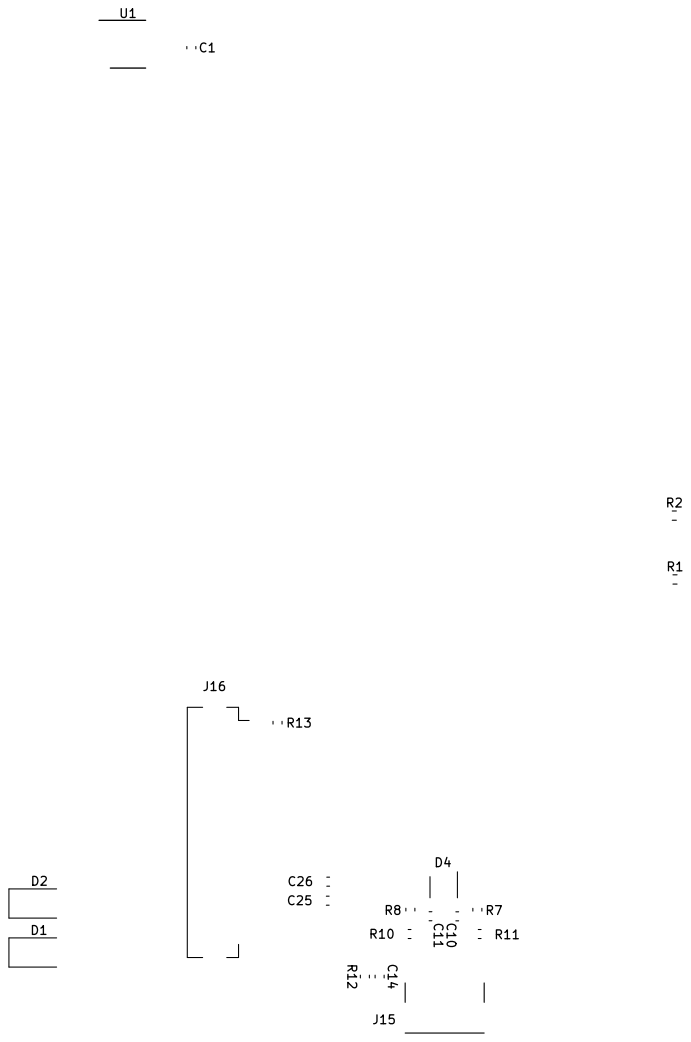
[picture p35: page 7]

@hamster and the dc801 badge team

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

Id: 1/1 Title: DC801 Badge - BM Pogo Fixture

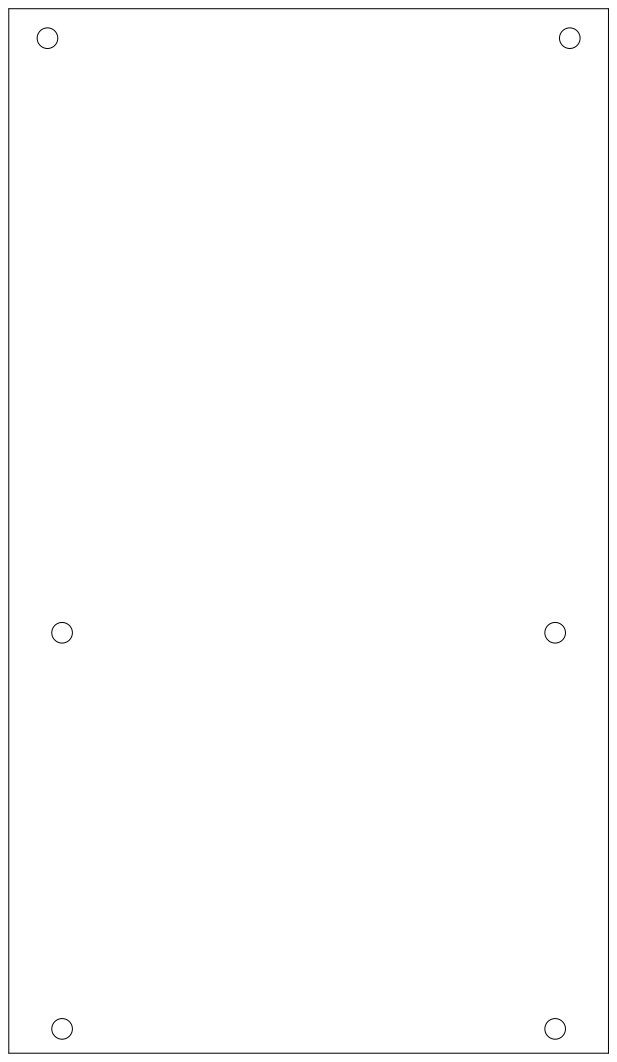
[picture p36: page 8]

@hamster and the dc801 badge team

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

Id: 1/1 Title: DC801 Badge - BM Pogo Fixture

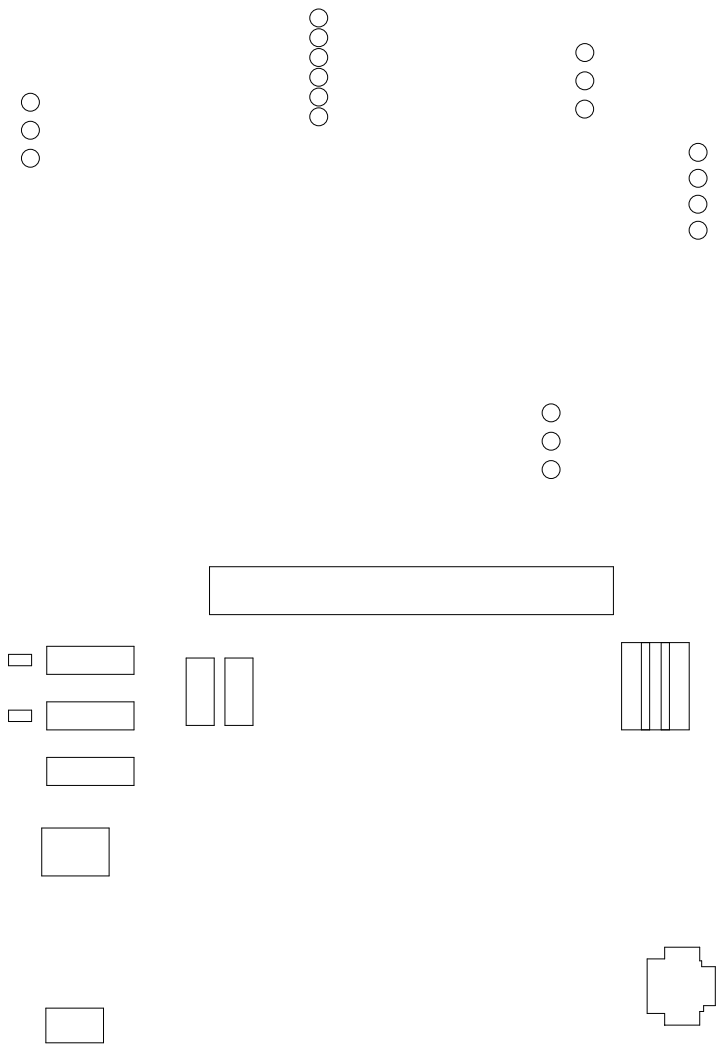
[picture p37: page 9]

@hamster and the dc801 badge team

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

Id: 1/1 Title: DC801 Badge - BM Pogo Fixture

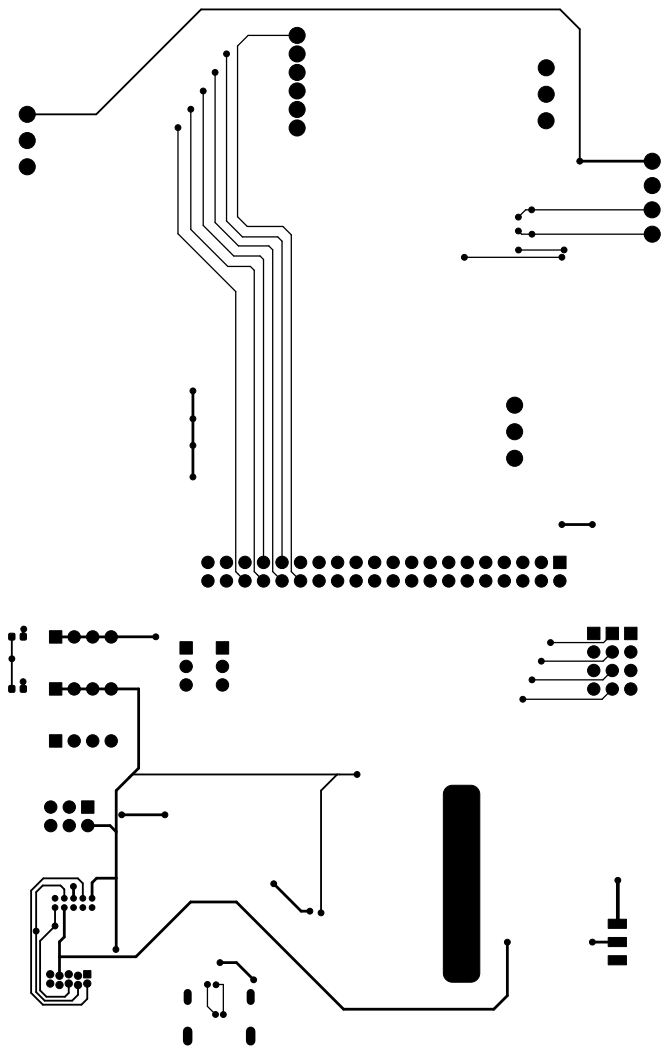
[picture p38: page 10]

@hamster and the dc801 badge team

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

Id: 1/1 Title: DC801 Badge - BM Pogo Fixture

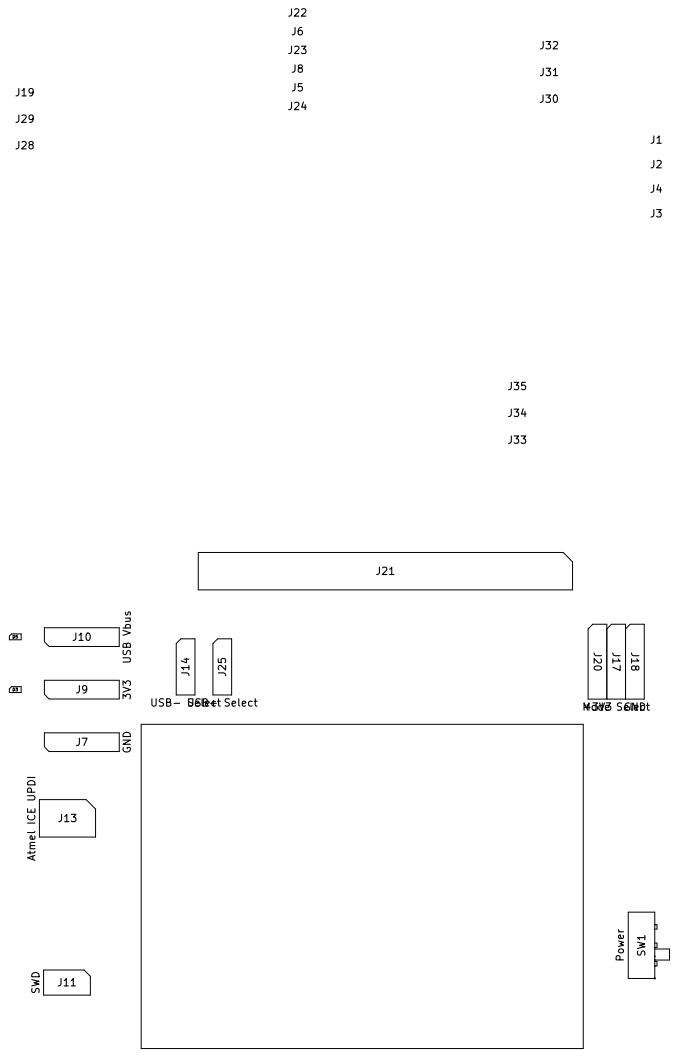
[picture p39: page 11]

@hamster and the dc801 badge team

codename purplewizard
File: purplewizard-pogo.kicad_pcb Sheet: DC801

Id: 1/1 Title: DC801 Badge - BM Pogo Fixture

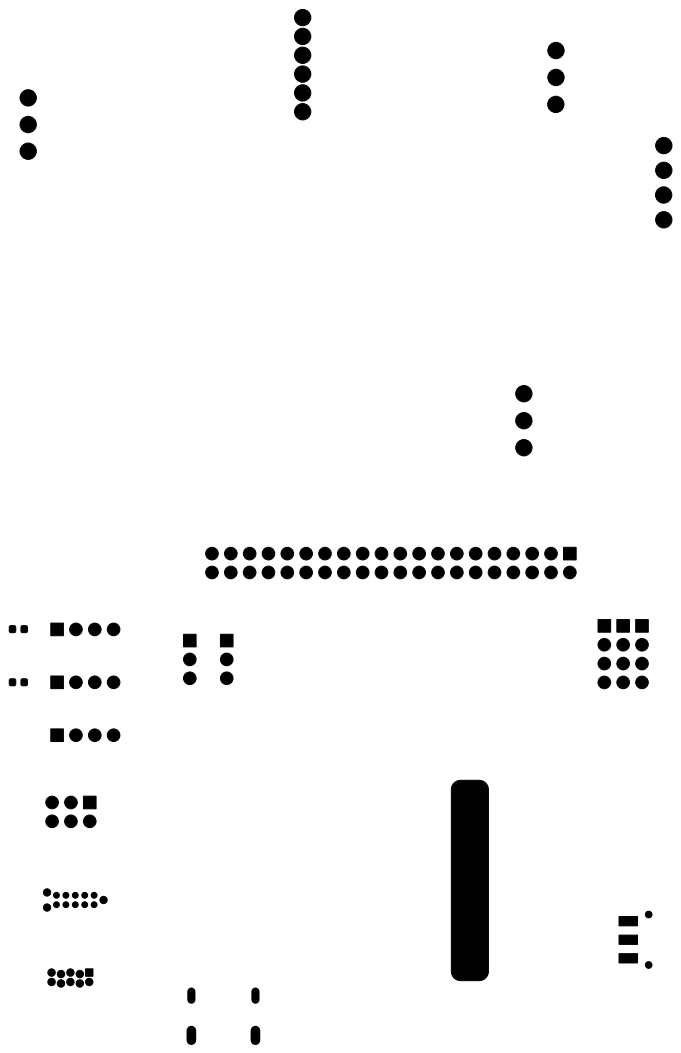
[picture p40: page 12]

@hamster and the dc801 badge team

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

Id: 1/1 Title: DC801 Badge - BM Pogo Fixture


@hamster and the dc801 badge team

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

Id: 1/1 Title: DC801 Badge - BM Pogo Fixture


J21 LCD Breakout D3 Vtarget D5 Vsupply
39 21 SWD SWD UPDI

@hamster and the dc801 badge team

codename purplewizard
File: purplewizard-pogo.kicad_pcb Sheet: DC801

Id: 1/1 Title: DC801 Badge - BM Pogo Fixture


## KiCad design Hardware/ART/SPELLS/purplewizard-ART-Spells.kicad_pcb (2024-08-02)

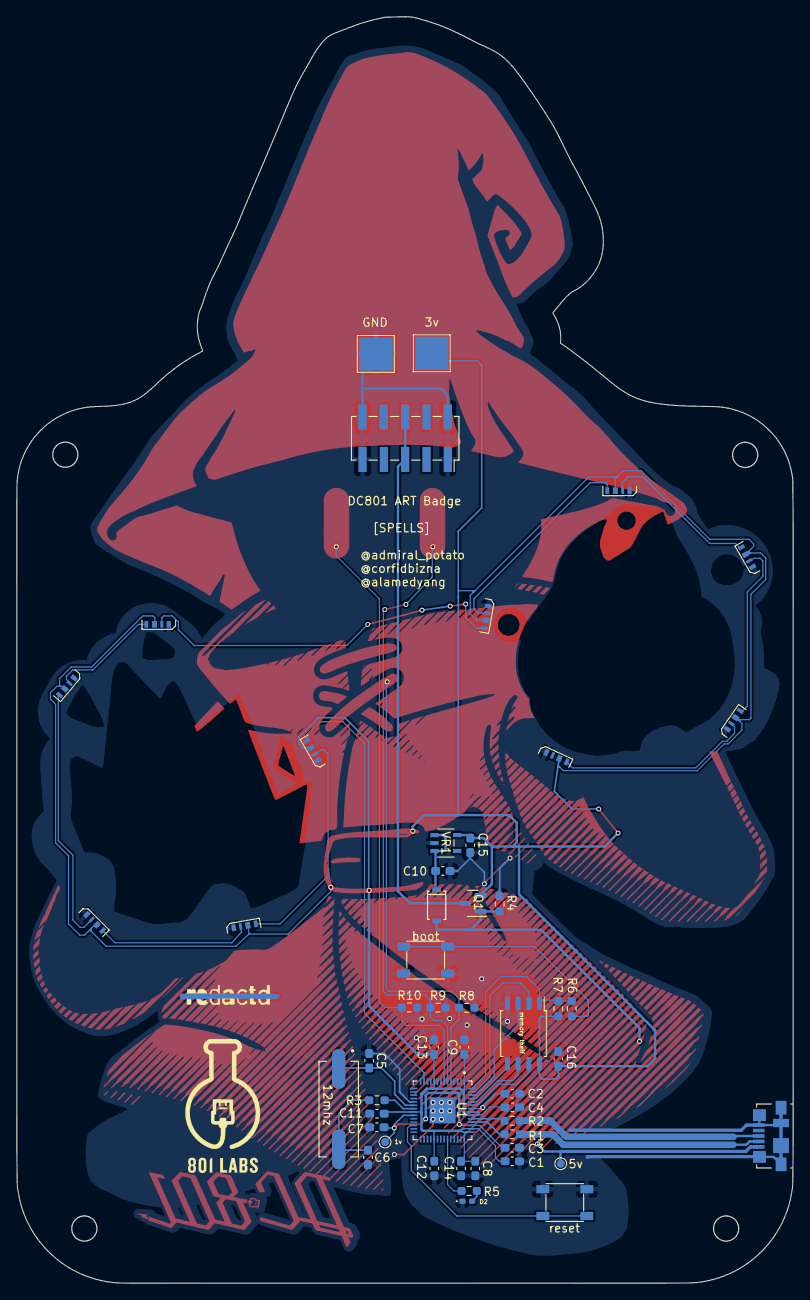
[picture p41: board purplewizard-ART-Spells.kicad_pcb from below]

Board: 2 copper layers, 92.5 x 151.0 mm, 52 parts (52 on the bottom side), 36 nets.

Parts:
1v: 1v; TestPoint_Pad_D1.0mm
3v: 3v3; TestPoint_Pad_4.0x4.0mm
5v: 5v; TestPoint_Pad_D1.0mm
12mhz: ABLS-12.000MHZ-B4-T; XTAL1140X470X420N
C1, C10, C15: 1uF; C_0603_1608Metric_Pad1.08x0.95mm_HandSolder
C2, C4, C7, C8, C9, C11, C12, C13, C14, C16: 100n; C_0603_1608Metric_Pad1.08x0.95mm_HandSolder
C3: 1u; C_0603_1608Metric_Pad1.08x0.95mm_HandSolder
C5, C6: 27pF; C_0603_1608Metric_Pad1.08x0.95mm_HandSolder
D1: D_Schottky; SM5819PL-TP
D2: LED; LED_0402_1005Metric_Pad0.77x0.64mm_HandSolder
D3, D4, D5, D6, D7, D8, D9, D10, D11, D12: LED_SK6812_4020_SIDE
GND: GND; TestPoint_Pad_4.0x4.0mm
J1: ART Expansion; PinSocket_2x05_P2.54mm_Vertical_SMD
J4: USB_B_Micro; USB_Micro-B_Molex_47346-0001
Q1: DMG2301L; SOT-23
R1, R2: 27; R_0603_1608Metric_Pad0.98x0.95mm_HandSolder
R3, R5, R6: 1k; R_0603_1608Metric_Pad0.98x0.95mm_HandSolder
R4, R7: 10k; R_0603_1608Metric_Pad0.98x0.95mm_HandSolder
R8, R9, R10: 1M; R_0603_1608Metric_Pad0.98x0.95mm_HandSolder
Ref**: Val**; redactd_copper_strike_v1
U1: RP2040; QFN40P700X700X90-57N
VR1: AP7366-33W5-7; AP7365-33WG-7
boot: SW_SPST; SW_SPST_PTS647
memory theif: W25Q32JVSS; SOIC-8_5.23x5.23mm_P1.27mm
reset: SW_SPST_PTS647

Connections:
+1V1: 1v.1, C2.1, C3.2, C7.1, U1.23 (DVDD), U1.45 (VREG_VOUT), U1.50 (DVDD)
+3.3VP: J1.5, J1.6, Q1.3 (D)
+3V3: 3v.1, C1.2, C4.1, C8.1, C9.1, C11.1, C12.1, C13.1, C14.1, C15.1, C16.1, D3.2 (VDD), D4.2 (VDD), D5.2 (VDD), D6.2 (VDD), D7.2 (VDD), D8.2 (VDD), D9.2 (VDD), D10.2 (VDD), D11.2 (VDD), D12.2 (VDD), Q1.2 (S), R7.1, U1.1 (IOVDD), U1.10 (IOVDD), U1.22 (IOVDD), U1.33 (IOVDD), U1.42 (IOVDD), U1.43 (ADC_AVDD), U1.44 (VREG_VIN), U1.48 (USB_VDD), U1.49 (IOVDD), VR1.5 (OUT), memory theif.8 (VCC)
D+: J4.3 (D+), R2.2
D-: J4.2 (D-), R1.2
GND: C1.1, C2.2, C3.1, C4.2, C5.1, C6.1, C7.2, C8.2, C9.2, C10.2, C11.2, C12.2, C13.2, C14.2, C15.2, C16.2, D2.1 (K), D3.4 (GND), D4.4 (GND), D5.4 (GND), D6.4 (GND), D7.4 (GND), D8.4 (GND), D9.4 (GND), D10.4 (GND), D11.4 (GND), D12.4 (GND), GND.1, J1.1, J1.2, J1.9, J1.10, J4.5 (GND), J4.6 (Shield), R4.2, R8.2, R9.2, R10.2, U1.19 (TESTEN), U1.57 (GND), VR1.2 (GND), boot.2 (B), memory theif.4 (GND), reset.2 (B)
GPIO25: R5.1, U1.37 (GPIO25)
NEO: D3.1 (DIN), U1.13 (GPIO10)
unnamed: 12mhz.2, C6.2, R3.2
unnamed: C10.1, D1.1 (K), VR1.1 (IN), VR1.3 (EN)
unnamed: D2.2 (A), R5.2
unnamed: D3.3 (DOUT), D4.1 (DIN)
unnamed: D4.3 (DOUT), D5.1 (DIN)
unnamed: D5.3 (DOUT), D6.1 (DIN)
unnamed: D6.3 (DOUT), D7.1 (DIN)
unnamed: D7.3 (DOUT), D8.1 (DIN)
unnamed: D8.3 (DOUT), D9.1 (DIN)
unnamed: D9.3 (DOUT), D10.1 (DIN)
unnamed: D10.3 (DOUT), D11.1 (DIN)
unnamed: D11.3 (DOUT), D12.1 (DIN)
unnamed: R1.1, U1.46 (USB_DM)
unnamed: R2.1, U1.47 (USB_DP)
QSPI_SCLK: U1.52 (QSPI_SCLK), memory theif.6 (CLK)
QSPI_SD0: U1.53 (QSPI_SD0), memory theif.5 (DI(IO0))
QSPI_SD1: U1.55 (QSPI_SD1), memory theif.2 (DO(IO1))
QSPI_SD2: U1.54 (QSPI_SD2), memory theif.3 (IO2)
QSPI_SD3: U1.51 (QSPI_SD3), memory theif.7 (IO3)
QSPI_SS: R6.1, R7.2, U1.56 (QSPI_CSN), memory theif.1 (~CS)
RUN: U1.26 (RUN), reset.1 (A)
TOUCH1: R8.1, U1.5 (GPIO3)
TOUCH2: R9.1, U1.6 (GPIO4)
TOUCH3: R10.1, U1.7 (GPIO5)
USB_BOOT: R6.2, boot.1 (A)
VBUS: 5v.1, D1.2 (A), J4.1 (VBUS), Q1.1 (G), R4.1
XIN: 12mhz.1, C5.2, U1.20 (XIN)
XOUT: R3.1, U1.21 (XOUT)

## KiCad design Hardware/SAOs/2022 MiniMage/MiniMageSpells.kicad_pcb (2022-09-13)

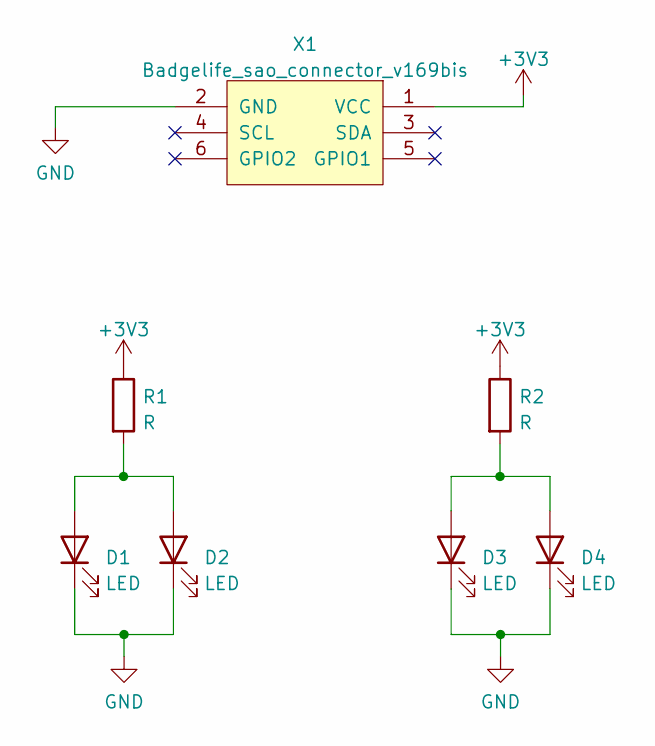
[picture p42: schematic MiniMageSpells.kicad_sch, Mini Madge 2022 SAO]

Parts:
D1, D2, D3, D4: LED; LED_0805_2012Metric
R1, R2: R; R_0805_2012Metric
X1: Badgelife_sao_connector_v169bis; PinHeader_2x03_P2.54mm_Vertical_SMD

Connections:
+3V3: R1.1, R2.1, X1.1 (VCC)
GND: D1.1 (K), D2.1 (K), D3.1 (K), D4.1 (K), X1.2 (GND)
unnamed: D1.2 (A), D2.2 (A), R1.2
unnamed: D3.2 (A), D4.2 (A), R2.2

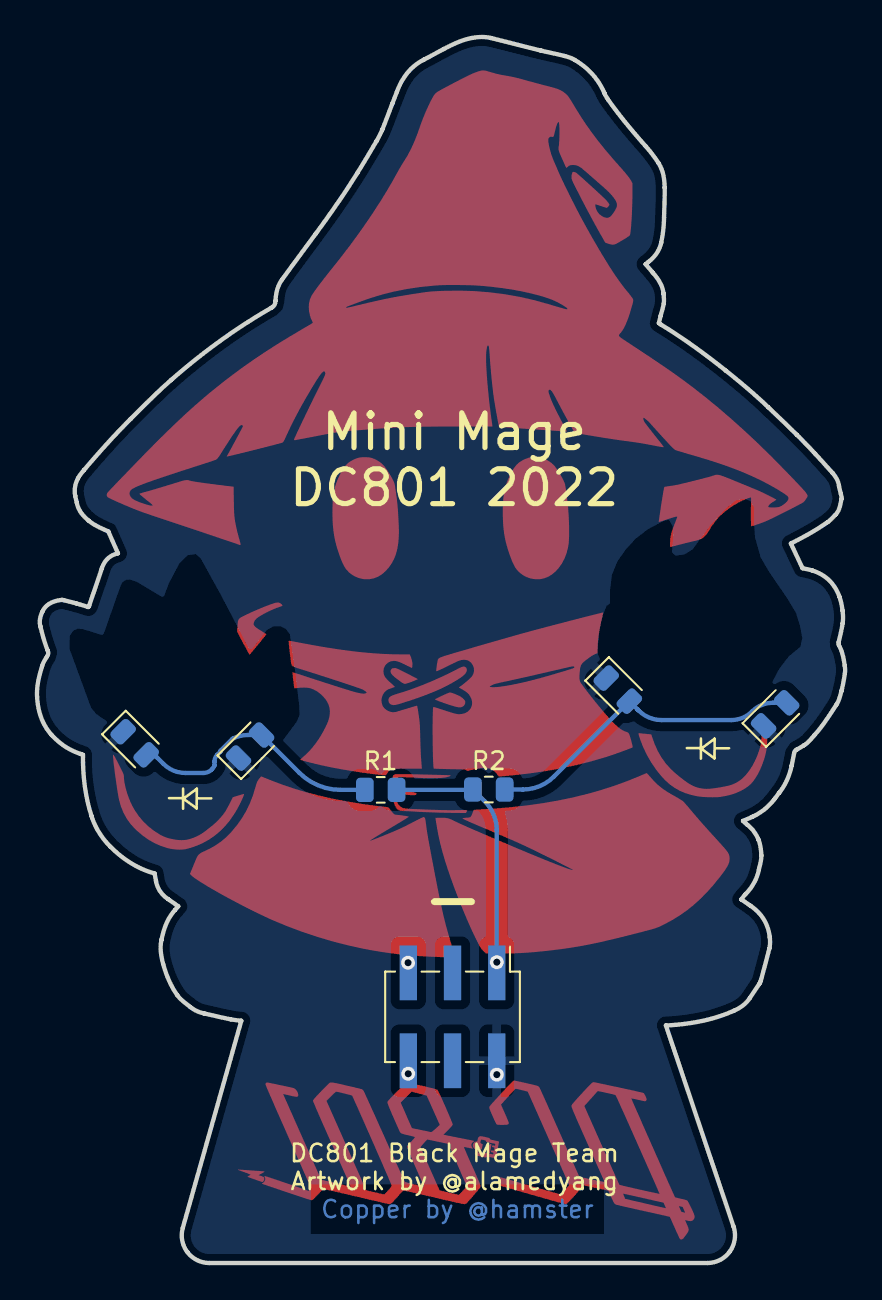
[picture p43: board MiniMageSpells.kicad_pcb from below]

Board: 2 copper layers, 46.4 x 70.4 mm, 7 parts (7 on the bottom side), 4 nets.

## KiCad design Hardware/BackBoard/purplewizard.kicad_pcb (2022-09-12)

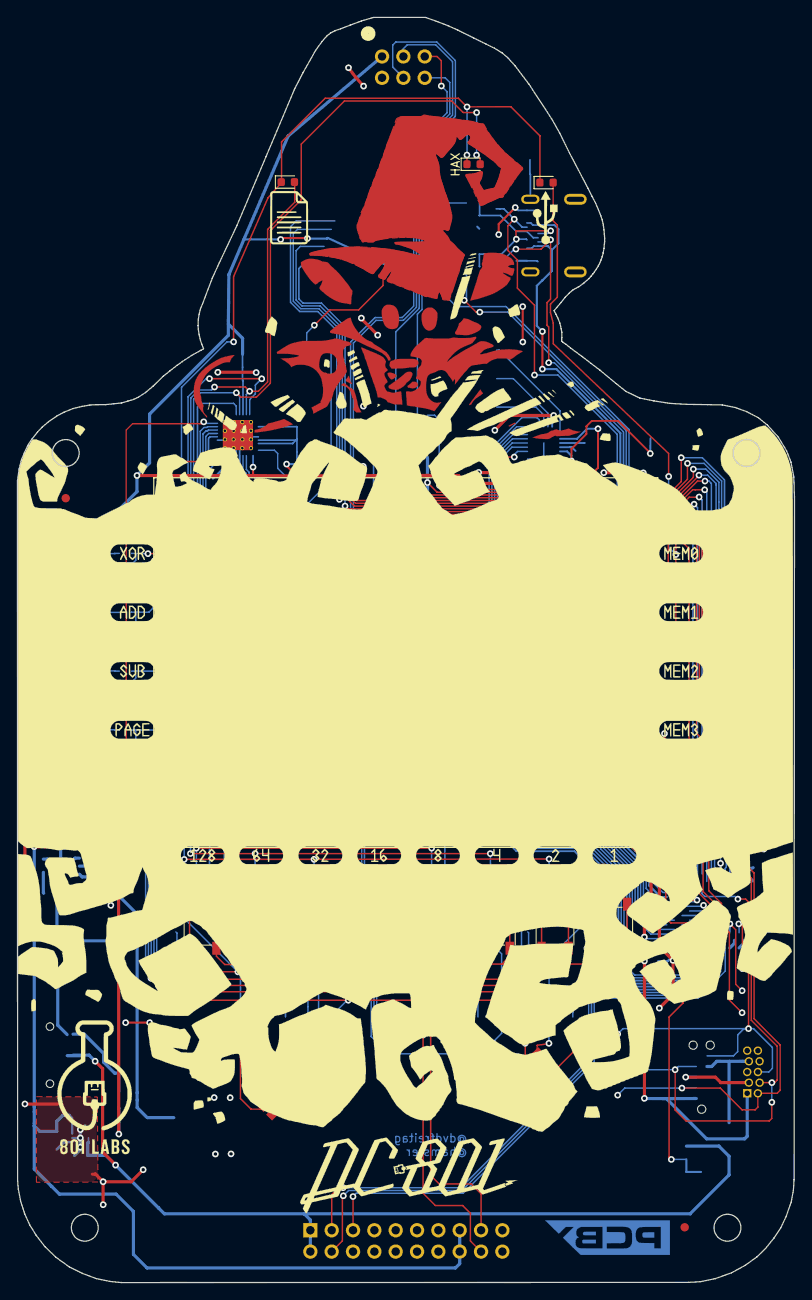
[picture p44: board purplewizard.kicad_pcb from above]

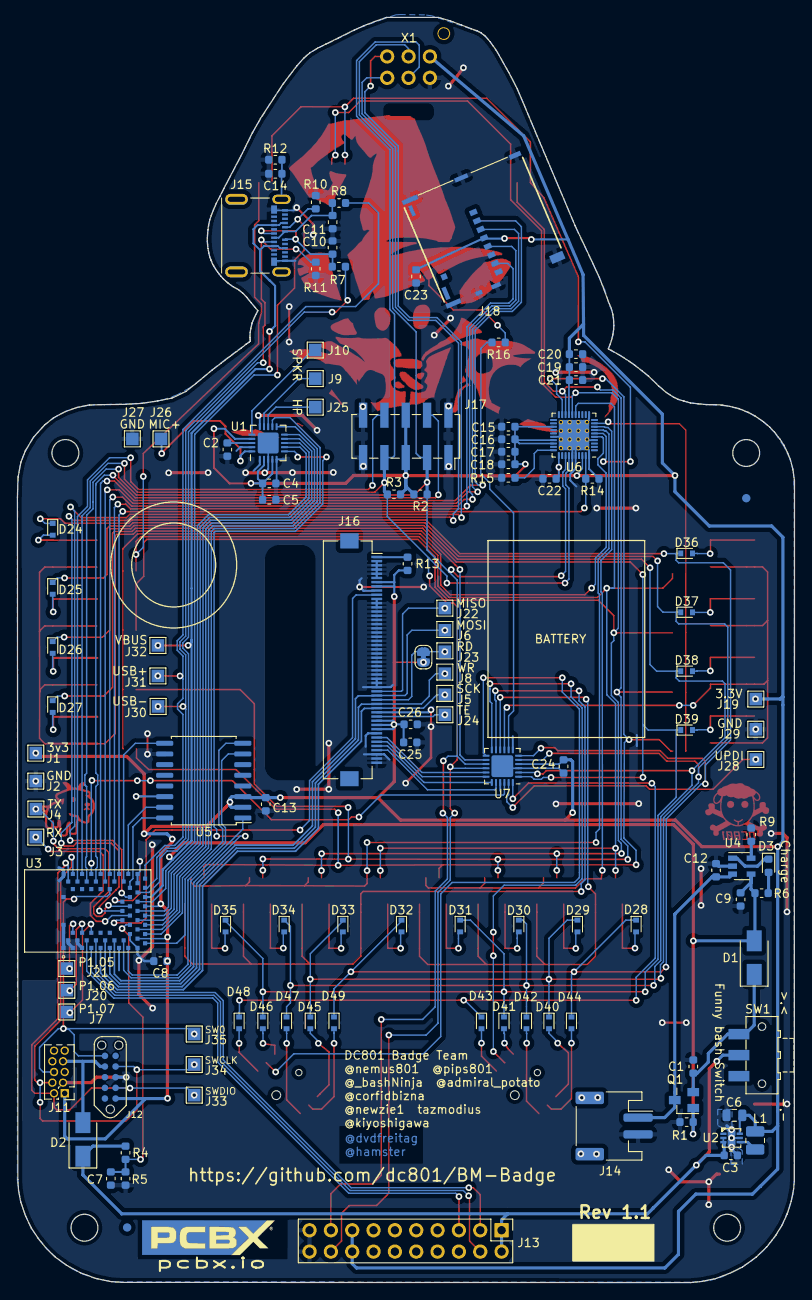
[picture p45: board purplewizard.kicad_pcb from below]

Board: 2 copper layers, 92.5 x 150.6 mm, 159 parts (118 on the bottom side), 121 nets.

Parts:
C1, C13, C14, C15, C17, C20, C23, C24, C25: 0.1uF; C_0603_1608Metric
C2, C4, C5, C8, C9, C12: 4.7uF; C_0603_1608Metric
C3, C26: 10uF; C_0603_1608Metric
C6: 22uF; C_0805_2012Metric
C7: 1nF; C_0603_1608Metric
C10, C11: 47pF; C_0603_1608Metric
C16, C18, C21, C22: 0.47uF; C_0603_1608Metric
C19: 22uF; C_0603_1608Metric
D1, D2: D_Schottky; D_SMA
D3: RED; LED_0603_1608Metric
D5: XOR; LED_0603_1608Metric
D6: MEM0; LED_0603_1608Metric
D7: BIT128; LED_0603_1608Metric
D8: BIT8; LED_0603_1608Metric
D9: USB; LED_0603_1608Metric
D10: ADD; LED_0603_1608Metric
D11: MEM1; LED_0603_1608Metric
D12: BIT64; LED_0603_1608Metric
D13: BIT4; LED_0603_1608Metric
D14: HAX; LED_0603_1608Metric
D15: SUB; LED_0603_1608Metric
D16: MEM2; LED_0603_1608Metric
D17: BIT32; LED_0603_1608Metric
D18: BIT2; LED_0603_1608Metric
D19: SD; LED_0603_1608Metric
D20: PAGE; LED_0603_1608Metric
D21: MEM3; LED_0603_1608Metric
D22: BIT16; LED_0603_1608Metric
D23: BIT1; LED_0603_1608Metric
D24, D25, D26, D27, D28, D29, D30, D31, D32, D33, D34, D35, D36, D37, D38, D39, D40, D41, D42, D43, D44, D45, D46, D47, D48, D49: D_ALT; D_SOD-523
FID1, FID2, FID3, FID4: Fiducial; Fiducial_1mm_Mask2mm
J1, J19: 3.3V; TestPoint_Pad_1.5x1.5mm
J2, J27, J29: GND; TestPoint_Pad_1.5x1.5mm
J3: UART_TX; TestPoint_Pad_1.5x1.5mm
J4: UART_RX; TestPoint_Pad_1.5x1.5mm
J5: LCD_SCK; TestPoint_Pad_1.5x1.5mm
J6: LCD_MOSI; TestPoint_Pad_1.5x1.5mm
J7: P1.07; TestPoint_Pad_1.5x1.5mm
J8: LCD_WR; TestPoint_Pad_1.5x1.5mm
J9: SPKR+; TestPoint_Pad_1.5x1.5mm
J10: SPKR-; TestPoint_Pad_1.5x1.5mm
J11: JTAG; PinHeader_2x05_P1.27mm_Vertical_Sneaky
J12: TagConnect; TC2050-NL_SMALL
J13: Minibadge Expansion; PinSocket_2x10_P2.54mm_Vertical
J14: Battery; JST_PH_S2B-PH-SM4-TB_1x02-1MP_P2.00mm_Horizontal
J15: USB_C_Receptacle_USB2.0; MOLEX_105450-0101
J16: Conn_01x50; Hirose_FH12-50S-0.5SH_1x50-1MP_P0.50mm_Horizontal
J17: Board to Board; PinSocket_2x05_P2.54mm_Vertical_SMD
J18: Micro_SD_Card; JAE_ST11S008V4HR2000
J20: P1.06; TestPoint_Pad_1.5x1.5mm
J21: P1.05; TestPoint_Pad_1.5x1.5mm
J22: LCD_MISO; TestPoint_Pad_1.5x1.5mm
J23: LCD_RD; TestPoint_Pad_1.5x1.5mm
J24: LCD_TE; TestPoint_Pad_1.5x1.5mm
J25: MOUT; TestPoint_Pad_1.5x1.5mm
J26: MIC+; TestPoint_Pad_1.5x1.5mm
J28: UPDI; TestPoint_Pad_1.5x1.5mm
J30: USB-; TestPoint_Pad_1.5x1.5mm
J31: USB+; TestPoint_Pad_1.5x1.5mm
J32: VBUS; TestPoint_Pad_1.5x1.5mm
J33: SWDIO; TestPoint_Pad_1.5x1.5mm
J34: SWCLK; TestPoint_Pad_1.5x1.5mm
J35: SWO; TestPoint_Pad_1.5x1.5mm
JP1: SolderJumper_2_Bridged; SolderJumper-2_P1.3mm_Bridged_RoundedPad1.0x1.5mm
L1: 1uH; L_1008_2520Metric
Q1: AO3409; SuperSOT-3
R1, R12: 10k; R_0603_1608Metric
R2, R3: 4.7k; R_0603_1608Metric
R4: 806k; R_0603_1608Metric
R5: 2M; R_0603_1608Metric
R6: 470R; R_0603_1608Metric
R7, R8: 27R; R_0603_1608Metric
R9: 2.0k; R_0603_1608Metric
R10, R11: 5.1k; R_0603_1608Metric
R13: 33R; R_0603_1608Metric
R14: 100k; R_0603_1608Metric
R15: 20k; R_0603_1608Metric
R16: 1k; R_0603_1608Metric
SW1: Power; SW_SPDT_CK-JS102011SAQN
SW2, SW3, SW4, SW5, SW6, SW7, SW8, SW9, SW10, SW11, SW12, SW13, SW14, SW15, SW16, SW17: TACTILE; SW_SPST_PTS647
SW18, SW19: SKRHABE010
U1: NAU8810; QFN-20-1EP_4x4mm_P0.5mm_EP2.5x2.5mm
U2: SC189ZULTRT
U3: BMD-340; RIGADO_BMD-340
U4: MCP73832-2-OT; SOT-23-5
U5: S25FL256S; SOIC-16W_7.5x10.3mm_P1.27mm
U6: IS31FL3736; QFN-40-1EP_5x5mm_P0.4mm_EP3.6x3.6mm_LargerThermalVias
U7: ATtiny1617-M; QFN-24-1EP_4x4mm_P0.5mm_EP2.6x2.6mm
X1: Badgelife_sao_connector_v169bis; Badgelife-Shitty-v1.69bis

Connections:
+3V3: C4.2, C5.2, C6.1, C8.1, C13.2, C15.1, C16.2, C17.1, C18.2, C19.1, C20.1, C21.2, C22.1, C23.2, C24.2, C25.2, C26.2, J1.1, J11.1, J12.1, J13.15, J13.16, J16.7, J16.8, J16.40, J16.41, J16.42, J17.5, J17.6, J18.4 (VDD), J19.1, JP1.2 (B), L1.2, R2.2, R3.2, R13.1, U1.2 (VDDA), U1.4 (VDDD), U1.17 (VDDSPK), U2.6 (OUT), U3.17 (Vcc), U3.65 (Vcch1), U5.2 (Vcc), U5.3 (~Reset), U5.14 (VIO), U6.17 (PVCC), U6.23 (PVCC), U6.27 (DVCC), U6.28 (AVCC), U6.31 (VIO), U6.38 (SDB), U7.4 (VCC), X1.1 (VCC)
+BATT: C12.2, J14.1, Q1.3 (D), U4.3 (Vbat)
+BATT_SW: C3.1, D2.1 (K), J13.1, J13.2, R4.2, SW1.2 (B), U2.2 (EN), U2.3 (Vin)
C0: SW2.2 (B), SW3.2 (B), SW4.2 (B), SW5.2 (B), U7.14 (PB2)
C1: SW6.2 (B), SW7.2 (B), SW8.2 (B), SW9.2 (B), U7.10 (PB6)
C2: SW10.2 (B), SW11.2 (B), SW12.2 (B), SW13.2 (B), U7.11 (PB5)
C3: SW14.2 (B), SW15.2 (B), SW16.2 (B), SW17.2 (B), U7.9 (PB7)
C4: SW18.5 (Common), U7.12 (PB4)
C5: SW19.5 (Common), U7.13 (PB3)
EXP1: J17.4, U3.38 (P0.20)
EXP2: J17.8, U3.42 (P0.24)
GND: C1.2, C2.1, C3.2, C4.1, C5.1, C6.2, C7.2, C8.2, C9.1, C10.1, C11.2, C12.1, C13.1, C14.2, C15.2, C16.1, C17.2, C18.1, C19.2, C20.2, C21.1, C22.2, C23.1, C24.1, C25.1, C26.1, J2.1, J11.3, J12.3, J13.19, J13.20, J14.2, J15.A1 (GND), J15.A12 (GND), J15.B1 (GND), J15.B12 (GND), J16.2, J16.3, J16.4, J16.5, J16.6, J16.9, J16.11, J16.12, J16.13, J16.14, J16.15, J16.16, J16.17, J16.18, J16.19, J16.20, J16.21, J16.22, J16.23, J16.24, J16.25, J16.26, J16.27, J16.28, J16.29, J16.30, J16.31, J16.32, J16.38, J16.43, J16.48, J16.49, J16.50, J17.1, J17.2, J17.9, J17.10, J18.6 (VSS), J18.9 (GND@1), J18.10 (GND@2), J18.11 (GND@3), J18.15 (GND@4), J18.16 (GND@5), J18.17 (GND@6), J18.18 (GND@7), J27.1, J29.1, R1.1, R5.1, R9.1, R10.2, R11.1, R12.2, R14.1, R15.1, U1.3 (VSSA), U1.5 (VSSD), U1.15 (VSSSPK), U2.5 (GND), U2.EP, U3.1 (GND1), U3.2 (GND1), U3.3 (GND1), U3.4 (GND1), U3.5 (GND1), U3.16 (GND1), U3.18 (GND1), U3.29 (GND1), U3.30 (GND1), U3.45 (GND1), U3.46 (GND1), U3.47 (GND1), U3.55 (GND1), U4.2 (Vss), U5.10 (Vss), U6.4 (PGND), U6.11 (PGND), U6.26 (AGND), U6.35 (ADDR1), U6.36 (ADDR2), U6.40 (GND), U6.41 (TGND), U7.3 (GND), U7.25 (GND), X1.2 (GND)
I2S_LRCK: U1.8 (LRCK), U3.64 (P1.15)
I2S_MCK: U1.10 (MCK), U3.63 (P1.14)
I2S_SCK: U1.9 (SCK), U3.21 (P0.05/AIN3)
I2S_SCL: U1.11 (SCL), U3.19 (P0.03/AIN1)
I2S_SDA: U1.12 (SDA), U3.62 (P1.13)
I2S_SDIN: U1.6 (SDOUT), U3.12 (P0.31)
I2S_SDOUT: U1.7 (SDIN), U3.23 (P0.07)
KEY_INT: U3.39 (P0.18), U7.22 (PC5)
LC0: D5.2 (A), D6.2 (A), D7.2 (A), D8.2 (A), D9.2 (A), U6.15 (CS1)
LC1: D10.2 (A), D11.2 (A), D12.2 (A), D13.2 (A), D14.2 (A), U6.16 (CS2)
LC2: D15.2 (A), D16.2 (A), D17.2 (A), D18.2 (A), D19.2 (A), U6.18 (CS3)
LC3: D20.2 (A), D21.2 (A), D22.2 (A), D23.2 (A), U6.19 (CS4)
LCD_MISO: J16.33, J22.1
LCD_MOSI: J6.1, J16.34, U3.11 (P0.30)
LCD_RD: J16.35, J23.1, JP1.1 (A)
LCD_RESET: J16.10, U3.53 (P1.10)
LCD_SCK: J5.1, J16.37, U3.9 (P0.28)
LCD_TE: J16.39, J24.1
LCD_WR: J8.1, J16.36, U3.10 (P0.29)
LED_RESET: R14.2, U3.33 (P0.15/TRACEDATA[2]), U6.39 (IICRST)
LR0: D5.1 (K), D10.1 (K), D15.1 (K), D20.1 (K), U6.9 (SW8)
LR1: D6.1 (K), D11.1 (K), D16.1 (K), D21.1 (K), U6.5 (SW4)
LR2: D7.1 (K), D12.1 (K), D17.1 (K), D22.1 (K), U6.8 (SW7)
LR3: D8.1 (K), D13.1 (K), D18.1 (K), D23.1 (K), U6.7 (SW6)
LR4: D9.1 (K), D14.1 (K), D19.1 (K), U6.6 (SW5)
MB_MISO: J13.4, U3.7 (P0.26)
MB_MOSI: J13.3, U3.8 (P0.27)
MB_SCK: J13.5, U3.6 (P0.25)
MEM_CS: U3.15 (P0.02/AIN0), U5.7 (~CS)
MEM_IO0: U3.31 (P0.13), U5.15 (IO0)
MEM_IO1: U3.61 (P1.12), U5.8 (IO1)
MEM_IO2: U3.32 (P0.14), U5.9 (IO2)
MEM_IO3: U3.14 (P0.01/XTAL2), U5.1 (IO3)
MEM_SCK: U3.28 (P0.12), U5.16 (SCK)
unnamed: C1.1, D1.1 (K), Q1.2 (S), SW1.3 (C)
unnamed: C2.2, U1.18 (VREF)
unnamed: C10.2, J15.A7 (D-), J15.B7 (D-), R7.1
unnamed: C11.1, J15.A6 (D+), J15.B6 (D+), R8.1
unnamed: C14.1, J15.S1 (SHIELD), R12.1
unnamed: D3.1 (K), U4.1 (STAT)
unnamed: D3.2 (A), R6.2
unnamed: J7.1, U3.50 (P1.07)
unnamed: J9.1, U1.14 (SPKOUT+)
unnamed: J10.1, U1.16 (SPKOUT-)
unnamed: J16.1, R13.2
unnamed: J20.1, U3.49 (P1.06)
unnamed: J21.1, U3.48 (P1.05)
unnamed: J25.1, U1.13 (MOUT)
unnamed: J26.1, U1.20 (MIC+)
unnamed: L1.1, U2.4 (LX)
unnamed: R9.2, U4.5 (PROG)
unnamed: R15.2, U6.30 (RSET)
unnamed: R16.2, U7.8 (PA7)
unnamed: D24.2 (A), SW2.1 (A)
unnamed: D25.2 (A), SW3.1 (A)
unnamed: D26.2 (A), SW4.1 (A)
unnamed: D27.2 (A), SW5.1 (A)
unnamed: D28.2 (A), SW6.1 (A)
unnamed: D29.2 (A), SW7.1 (A)
unnamed: D30.2 (A), SW8.1 (A)
unnamed: D31.2 (A), SW9.1 (A)
unnamed: D32.2 (A), SW10.1 (A)
unnamed: D33.2 (A), SW11.1 (A)
unnamed: D34.2 (A), SW12.1 (A)
unnamed: D35.2 (A), SW13.1 (A)
unnamed: D36.2 (A), SW14.1 (A)
unnamed: D37.2 (A), SW15.1 (A)
unnamed: D38.2 (A), SW16.1 (A)
unnamed: D39.2 (A), SW17.1 (A)
unnamed: D40.2 (A), SW18.1 (A)
unnamed: D44.2 (A), SW18.2 (Center)
unnamed: D42.2 (A), SW18.3 (C)
unnamed: D41.2 (A), SW18.4 (B)
unnamed: D43.2 (A), SW18.6 (D)
unnamed: D45.2 (A), SW19.1 (A)
unnamed: D49.2 (A), SW19.2 (Center)
unnamed: D47.2 (A), SW19.3 (C)
unnamed: D46.2 (A), SW19.4 (B)
unnamed: D48.2 (A), SW19.6 (D)
R0: D24.1 (K), D28.1 (K), D32.1 (K), D36.1 (K), D44.1 (K), D49.1 (K), U7.6 (PA5)
R1: D25.1 (K), D29.1 (K), D33.1 (K), D37.1 (K), D40.1 (K), D45.1 (K), U7.5 (PA4)
R2: D26.1 (K), D30.1 (K), D34.1 (K), D38.1 (K), D42.1 (K), D47.1 (K), U7.2 (PA3)
R3: D27.1 (K), D31.1 (K), D35.1 (K), D39.1 (K), D41.1 (K), D46.1 (K), U7.1 (PA2)
R4: D43.1 (K), D48.1 (K), U7.24 (PA1)
S1_1: U3.26 (P0.10/NFC2), X1.5 (GPIO1)
S1_2: U3.54 (P1.11), X1.6 (GPIO2)
SCL: J13.18, J17.7, R3.1, U3.41 (P0.23), U6.34 (SCL), U7.16 (PB0), X1.4 (SCL)
SDA: J13.17, J17.3, R2.1, U3.40 (P0.22), U6.33 (SDA), U7.15 (PB1), X1.3 (SDA)
SD_CS: J18.2 (DAT3/CD), U3.37 (P0.19)
SD_MISO: J18.7 (DAT0), U3.34 (P0.16/TRACEDATA[1])
SD_MOSI: J18.3 (CMD), U3.36 (P0.21)
SD_SCK: J18.5 (CLK), U3.35 (P0.17)
SW0: J11.6, J12.6, J35.1, U3.56 (TRACEDATA[0]/SW0/P1.00)
SWCLK: J11.4, J12.4, J34.1, U3.43 (SWCLK)
SWDIO: J11.2, J12.2, J33.1, U3.44 (SWDIO)
TC_PWR: D2.2 (A), J11.7, J12.7
TOUCH_X+: J16.44, U7.17 (PC0)
TOUCH_X-: J16.46, U7.19 (PC2)
TOUCH_Y+: J16.45, U7.18 (PC1)
TOUCH_Y-: J16.47, U7.20 (PC3)
UART_RX: J4.1, U3.24 (P0.08)
UART_TX: J3.1, U3.22 (P0.06)
UPDI: J28.1, U7.23 (~RESET/PA0)
USB+: J31.1, R8.2, U3.68 (USB_D+)
USB-: J30.1, R7.2, U3.67 (USB_D-)
USB_CC1: J15.A5 (CC1), R10.1, U3.25 (P0.09/NFC1)
USB_CC2: J15.B5 (CC2), R11.2, U3.27 (P0.11)
VBAT_SENSE: C7.1, R4.1, R5.2, U3.20 (P0.04/AIN2)
VBUS: C9.2, D1.2 (A), J15.A4 (VBUS), J15.A9 (VBUS), J15.B4 (VBUS), J15.B9 (VBUS), J32.1, Q1.1 (G), R1.2, R6.1, U3.66 (Vbus), U4.4 (Vin)

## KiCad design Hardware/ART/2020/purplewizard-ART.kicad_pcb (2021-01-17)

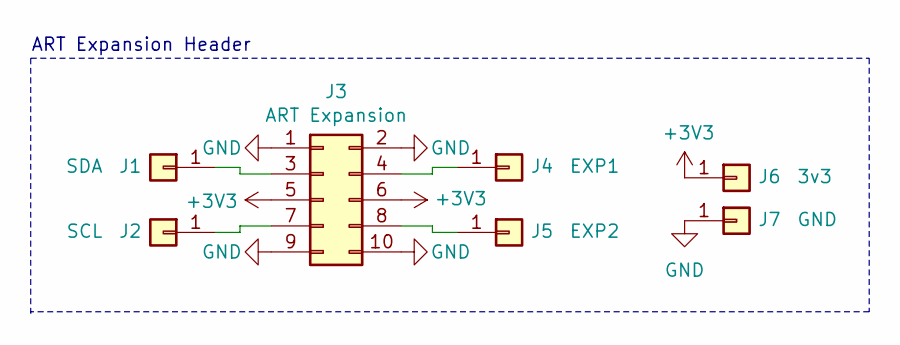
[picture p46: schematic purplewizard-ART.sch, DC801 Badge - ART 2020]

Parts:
J1: SDA; TestPoint_Pad_2.0x2.0mm
J2: SCL; TestPoint_Pad_2.0x2.0mm
J3: ART Expansion; PinSocket_2x05_P2.54mm_Vertical_SMD
J4: EXP1; TestPoint_Pad_2.0x2.0mm
J5: EXP2; TestPoint_Pad_2.0x2.0mm
J6: 3v3; TestPoint_Pad_4.0x4.0mm
J7: GND; TestPoint_Pad_4.0x4.0mm

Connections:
+3V3: J3.5, J3.6, J6.1
GND: J3.1, J3.2, J3.9, J3.10, J7.1
unnamed: J1.1, J3.3
unnamed: J2.1, J3.7
unnamed: J3.4, J4.1
unnamed: J3.8, J5.1

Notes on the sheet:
ART Expansion Header

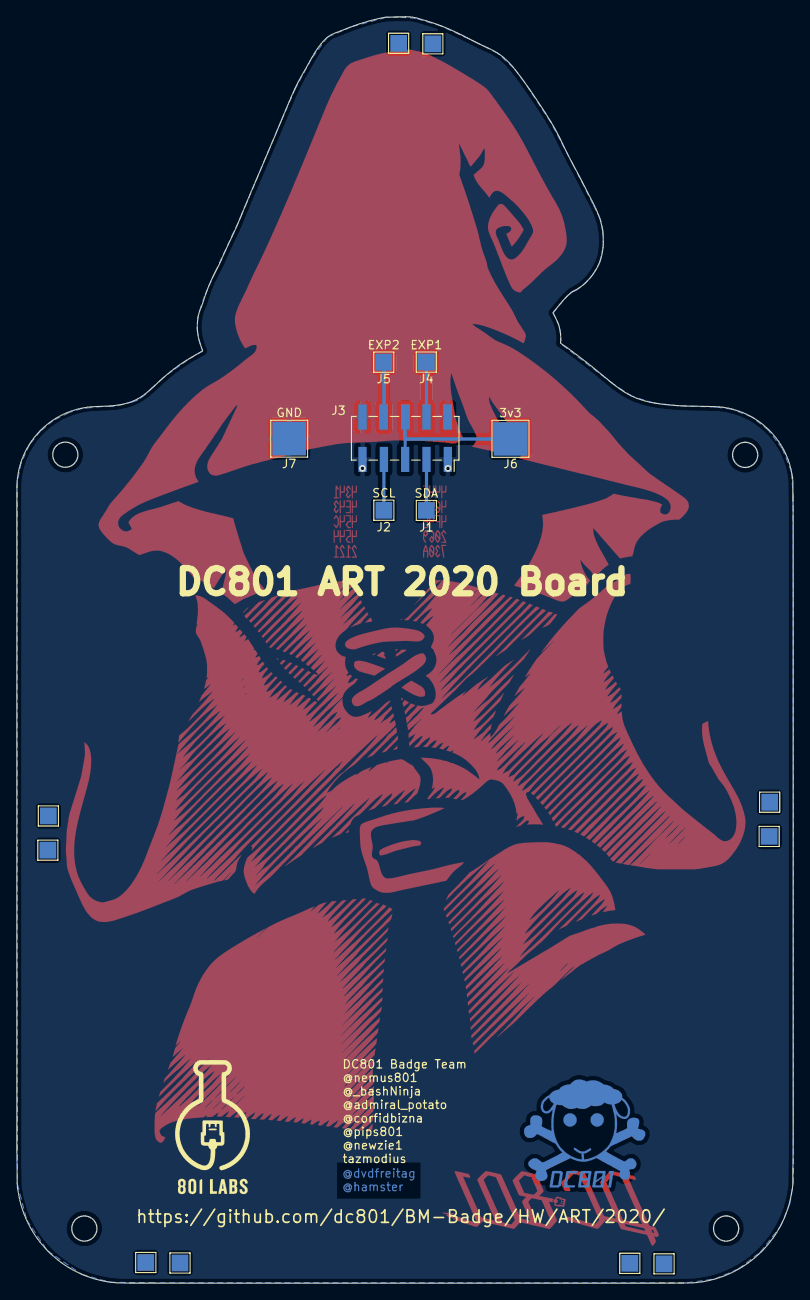
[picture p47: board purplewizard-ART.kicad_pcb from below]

Board: 2 copper layers, 92.5 x 151.0 mm, 7 parts (7 on the bottom side), 6 nets.

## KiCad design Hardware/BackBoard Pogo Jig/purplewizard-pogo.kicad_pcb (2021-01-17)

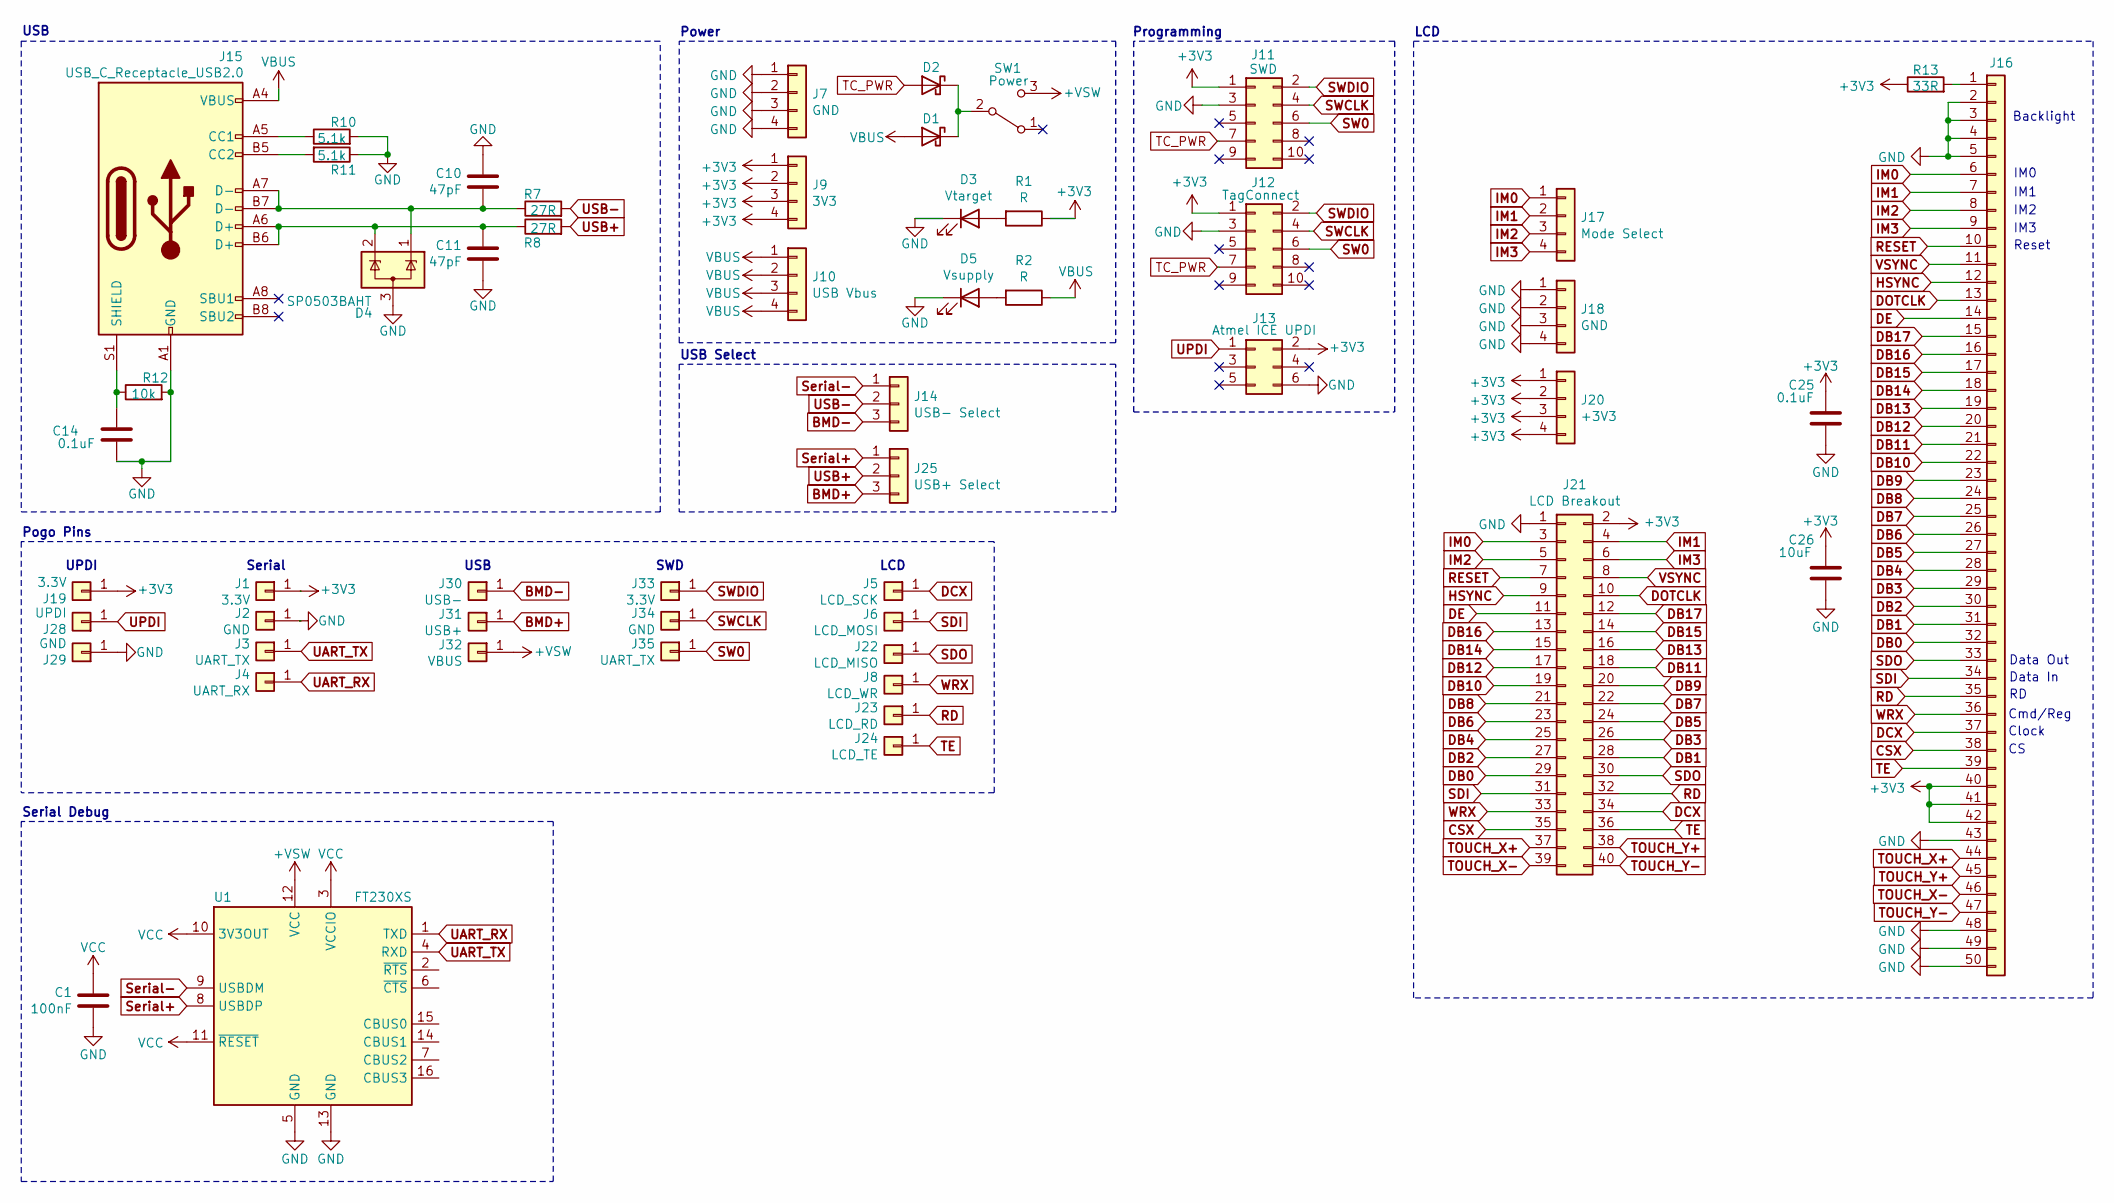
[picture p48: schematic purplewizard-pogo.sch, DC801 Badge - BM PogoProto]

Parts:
C1: 100nF; C_0603_1608Metric
C10, C11: 47pF; C_0603_1608Metric
C14, C25: 0.1uF; C_0603_1608Metric
C26: 10uF; C_0603_1608Metric
D1, D2: D_Schottky; D_SMA
D3: Vtarget; LED_0603_1608Metric
D4: SP0503BAHT; SOT-143
D5: Vsupply; LED_0603_1608Metric
J1, J19, J33: 3.3V; PogoSocket
J2, J29, J34: GND; PogoSocket
J3, J35: UART_TX; PogoSocket
J4: UART_RX; PogoSocket
J5: LCD_SCK; PogoSocket
J6: LCD_MOSI; PogoSocket
J7, J18: GND; PinHeader_1x04_P2.54mm_Vertical
J8: LCD_WR; PogoSocket
J9: 3V3; PinHeader_1x04_P2.54mm_Vertical
J10: USB Vbus; PinHeader_1x04_P2.54mm_Vertical
J11: SWD; PinHeader_2x05_P1.27mm_Vertical_Sneaky
J12: TagConnect; TC2050-NL_SMALL
J13: Atmel ICE UPDI; PinHeader_2x03_P2.54mm_Vertical
J14: USB- Select; PinHeader_1x03_P2.54mm_Vertical
J15: USB_C_Receptacle_USB2.0; MOLEX_105450-0101
J16: Conn_01x50; Hirose_FH12-50S-0.5SH_1x50-1MP_P0.50mm_Horizontal
J17: Mode Select; PinHeader_1x04_P2.54mm_Vertical
J20: +3V3; PinHeader_1x04_P2.54mm_Vertical
J21: LCD Breakout; PinHeader_2x20_P2.54mm_Vertical
J22: LCD_MISO; PogoSocket
J23: LCD_RD; PogoSocket
J24: LCD_TE; PogoSocket
J25: USB+ Select; PinHeader_1x03_P2.54mm_Vertical
J28: UPDI; PogoSocket
J30: USB-; PogoSocket
J31: USB+; PogoSocket
J32: VBUS; PogoSocket
R1, R2: R; R_0603_1608Metric
R7, R8: 27R; R_0603_1608Metric
R10, R11: 5.1k; R_0603_1608Metric
R12: 10k; R_0603_1608Metric
R13: 33R; R_0603_1608Metric
SW1: Power; SW_SPDT_CK-JS102011SAQN
U1: FT230XS; SSOP-16_3.9x4.9mm_P0.635mm

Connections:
+3V3: C25.2, C26.2, J1.1, J9.1, J9.2, J9.3, J9.4, J11.1, J12.1, J13.2, J16.40, J16.41, J16.42, J19.1, J20.1, J20.2, J20.3, J20.4, J21.2, R1.1, R13.1
+VSW: J32.1, SW1.3 (C), U1.12 (VCC)
BMD+: J25.3, J31.1
BMD-: J14.3, J30.1
CSX: J16.38, J21.35
DB0: J16.32, J21.29
DB1: J16.31, J21.28
DB2: J16.30, J21.27
DB3: J16.29, J21.26
DB4: J16.28, J21.25
DB5: J16.27, J21.24
DB6: J16.26, J21.23
DB7: J16.25, J21.22
DB8: J16.24, J21.21
DB9: J16.23, J21.20
DB10: J16.22, J21.19
DB11: J16.21, J21.18
DB12: J16.20, J21.17
DB13: J16.19, J21.16
DB14: J16.18, J21.15
DB15: J16.17, J21.14
DB16: J16.16, J21.13
DB17: J16.15, J21.12
DCX: J5.1, J16.37, J21.34
DE: J16.14, J21.11
DOTCLK: J16.13, J21.10
GND: C1.2, C10.1, C11.2, C14.2, C25.1, C26.1, D3.1 (K), D4.3 (A), D5.1 (K), J2.1, J7.1, J7.2, J7.3, J7.4, J11.3, J12.3, J13.6, J15.A1 (GND), J15.A12 (GND), J15.B1 (GND), J15.B12 (GND), J16.2, J16.3, J16.4, J16.5, J16.43, J16.48, J16.49, J16.50, J18.1, J18.2, J18.3, J18.4, J21.1, J29.1, R10.2, R11.1, R12.2, U1.5 (GND), U1.13 (GND)
HSYNC: J16.12, J21.9
IM0: J16.6, J17.1, J21.3
IM1: J16.7, J17.2, J21.4
IM2: J16.8, J17.3, J21.5
IM3: J16.9, J17.4, J21.6
unnamed: C10.2, D4.1 (K), J15.A7 (D-), J15.B7 (D-), R7.1
unnamed: C11.1, D4.2 (K), J15.A6 (D+), J15.B6 (D+), R8.1
unnamed: C14.1, J15.S1 (SHIELD), R12.1
unnamed: D1.1 (K), D2.1 (K), SW1.2 (B)
unnamed: D3.2 (A), R1.2
unnamed: D5.2 (A), R2.2
unnamed: J15.A5 (CC1), R10.1
unnamed: J15.B5 (CC2), R11.2
unnamed: J16.1, R13.2
RD: J16.35, J21.32, J23.1
RESET: J16.10, J21.7
SDI: J6.1, J16.34, J21.31
SDO: J16.33, J21.30, J22.1
SW0: J11.6, J12.6, J35.1
SWCLK: J11.4, J12.4, J34.1
SWDIO: J11.2, J12.2, J33.1
Serial+: J25.1, U1.8 (USBDP)
Serial-: J14.1, U1.9 (USBDM)
TC_PWR: D2.2 (A), J11.7, J12.7
TE: J16.39, J21.36, J24.1
TOUCH_X+: J16.44, J21.37
TOUCH_X-: J16.46, J21.39
TOUCH_Y+: J16.45, J21.38
TOUCH_Y-: J16.47, J21.40
UART_RX: J4.1, U1.1 (TXD)
UART_TX: J3.1, U1.4 (RXD)
UPDI: J13.1, J28.1
USB+: J25.2, R8.2
USB-: J14.2, R7.2
VBUS: D1.2 (A), J10.1, J10.2, J10.3, J10.4, J15.A4 (VBUS), J15.A9 (VBUS), J15.B4 (VBUS), J15.B9 (VBUS), R2.1
VCC: C1.1, U1.3 (VCCIO), U1.10 (3V3OUT), U1.11 (~RESET)
VSYNC: J16.11, J21.8
WRX: J8.1, J16.36, J21.33

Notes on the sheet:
Programming
Reset
Data In
Cmd/Reg
Clock
IM0
IM1
IM2
IM3
Data Out
LCD
Backlight
Pogo Pins
UPDI
Serial
USB
SWD
Power
Serial Debug
USB Select

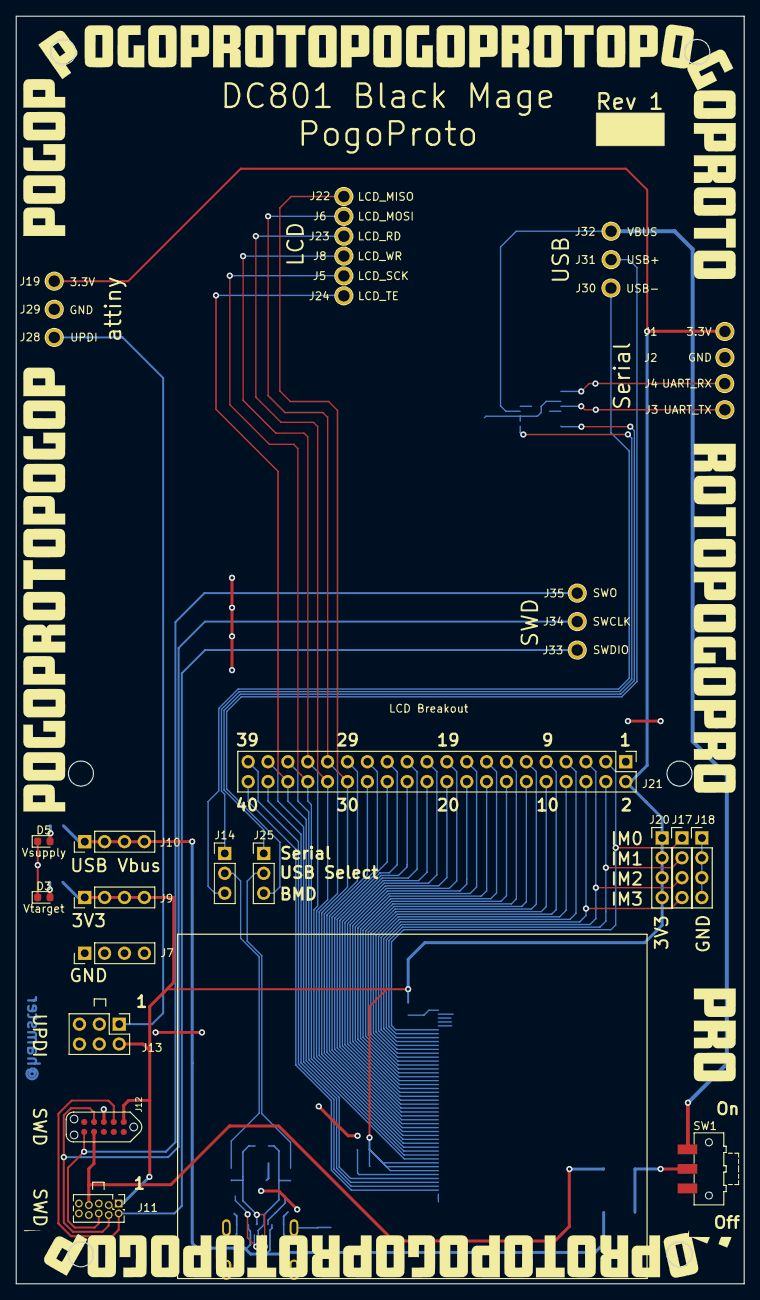
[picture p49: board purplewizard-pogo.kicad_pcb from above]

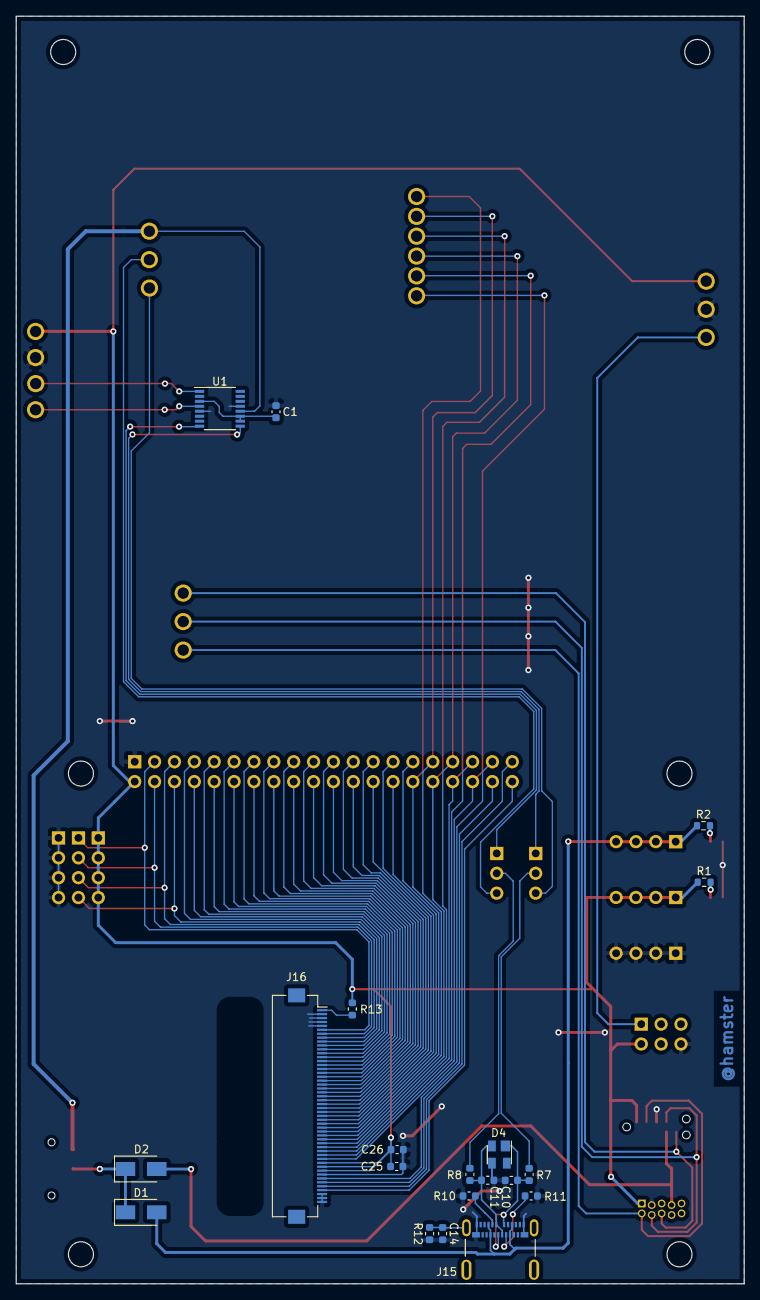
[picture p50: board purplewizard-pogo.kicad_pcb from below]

Board: 2 copper layers, 93.0 x 162.0 mm, 54 parts (20 on the bottom side), 65 nets.

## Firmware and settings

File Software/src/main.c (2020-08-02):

/**
 *
 * @file main.c
 *
 * @date May 24, 2017
 * @author hamster
 *
 * @brief This is the entry point for the DC801 DC26 party badge
 *
 */

#include <stdint.h>
#include "common.h"
#include "user.h"

#ifdef DC801_DESKTOP
#include<signal.h>

const int SCREEN_MULTIPLIER = 3;
const int SCREEN_WIDTH = WIDTH * SCREEN_MULTIPLIER;
const int SCREEN_HEIGHT = HEIGHT * SCREEN_MULTIPLIER;

SDL_Window* window = NULL;
SDL_Renderer* renderer = NULL;

volatile sig_atomic_t application_quit = 0;

void sig_handler(int signo)
{
    if (signo == SIGINT)
    {
        printf("received SIGINT\n");
        application_quit = 1;
    }
}

#endif

#define XVAL(x) #x
#define VAL(x)  XVAL(x)

/*
#pragma message ("TIMER_ENABLED=" VAL(TIMER_ENABLED))
#pragma message ("TIMER1_ENABLED=" VAL(TIMER1_ENABLED))
#pragma message ("NRFX_TIMER_ENABLED=" VAL(NRFX_TIMER_ENABLED))
#pragma message ("NRFX_TIMER1_ENABLED=" VAL(NRFX_TIMER1_ENABLED))
*/


volatile bool partyMode = false;
volatile bool sheepMode = false;

APP_TIMER_DEF(standby_animation_timer_id);

static void standby_animation_timeout_handler(void *p_context) {
    UNUSED_PARAMETER(p_context);

    p_canvas()->drawStop();
    // util_gfx_draw_raw_file_stop();
}

/**
 * Initialize the buttons
 */
static void button_init(void){
    // Setup the buttons
    #ifdef DC801_EMBEDDED
    nrf_gpio_cfg_input(USER_BUTTON_UP, NRF_GPIO_PIN_NOPULL);
    nrf_gpio_cfg_input(USER_BUTTON_DOWN, NRF_GPIO_PIN_NOPULL);
    nrf_gpio_cfg_input(USER_BUTTON_LEFT, NRF_GPIO_PIN_NOPULL);
    nrf_gpio_cfg_input(USER_BUTTON_RIGHT, NRF_GPIO_PIN_NOPULL);
    nrf_gpio_cfg_input(USER_BUTTON_A, NRF_GPIO_PIN_NOPULL);
    nrf_gpio_cfg_input(USER_BUTTON_B, NRF_GPIO_PIN_NOPULL);
    #else
    nrf_gpio_cfg_input(USER_BUTTON_UP, NRF_GPIO_PIN_PULLUP);
    nrf_gpio_cfg_input(USER_BUTTON_DOWN, NRF_GPIO_PIN_PULLUP);
    nrf_gpio_cfg_input(USER_BUTTON_LEFT, NRF_GPIO_PIN_PULLUP);
    nrf_gpio_cfg_input(USER_BUTTON_RIGHT, NRF_GPIO_PIN_PULLUP);
    nrf_gpio_cfg_input(USER_BUTTON_A, NRF_GPIO_PIN_PULLUP);
    nrf_gpio_cfg_input(USER_BUTTON_B, NRF_GPIO_PIN_PULLUP);
    #endif
}

/**
 * Initialize the speaker
 */
static void speaker_init(void){
    // Setup the beeper
    nrf_gpio_cfg_output(SPEAKER);
}

/**
 * Initialize the logging backend for logging over JTAG
 */
static void log_init(void){
    ret_code_t err_code = NRF_LOG_INIT(NULL);
    APP_ERROR_CHECK(err_code);

    NRF_LOG_DEFAULT_BACKENDS_INIT();
}

/**
 * Handler to show the LEDs during bootup animation
 * @param frame
 * @param p_data
 */
static void bootCallback(uint8_t frame, void *p_data){
    const int speed = 4;

    if (frame == 5) {
        ledOn(LED_COMPBAY);
        ledOn(LED_CARGO);
        ledOn(LED_DAMAGED);
        ledOn(LED_SHIELDS);
        ledOn(LED_DAMAGED);
        ledOn(LED_BRIDGE);
        ledShow();
    }
    else if (frame == 30) {
        ledOn(LED_GUN1);
        ledOn(LED_GUN2);
        ledOn(LED_GUN3);
        ledOn(LED_GUN4);
        ledShow();
    }
    else if (frame == 45) {
        ledOn(LED_WEAPONS1);
        ledOn(LED_WEAPONS2);
        ledShow();
    }
    else if (frame == 55) {
        ledOn(LED_COMM1);
        ledOn(LED_COMM2);
        ledShow();
    }
    else if (frame == 70) {
        ledOn(LED_HULL1);
        ledOn(LED_HULL2);
        ledOn(LED_HULL3);
        ledOn(LED_HULL4);
        ledShow();
    }
    else if (frame == 75) {
        ledOn(LED_ENGINE1);
        ledOn(LED_ENGINE2);
        ledOn(LED_ENGINEERING);
        ledShow();
    }
    else if (frame == 85) {
        ledOn(LED_LIFE1);
        ledShow();
    }
    else if (frame == 95) {
        ledOn(LED_LIFE2);
        ledShow();
    }
    else if (frame == 105) {
        ledOn(LED_LIFE3);
        ledShow();
    }
    else if (frame == 115) {
        ledOn(LED_LIFE4);
        ledShow();
    }
    else if (frame == 125) {
        ledOn(LED_LIFE5);
        ledShow();
    }
    else if ((frame == 145) || (frame == 155) || (frame == 165) || (frame == 175)) {
        ledOff(LED_COMPBAY);
        ledOff(LED_CARGO);
        ledOff(LED_DAMAGED);
        ledOff(LED_SHIELDS);
        ledOff(LED_DAMAGED);
        ledOff(LED_BRIDGE);
        ledOff(LED_ENGINE1);
        ledOff(LED_ENGINE2);
        ledOff(LED_ENGINEERING);
        ledOn(LED_PERSON_COMPBAY);
        ledOn(LED_PERSON_CARGO);
        ledOn(LED_PERSON_DAMAGED);
        ledOn(LED_PERSON_SHIELDS);
        ledOn(LED_PERSON_BRIDGE);
        ledOn(LED_PERSON_ENGINE);
        ledOn(LED_PERSON_ENGINEERING);
        ledShow();
    }
    else if ((frame == 140) || (frame == 150) || (frame == 160) || (frame == 170) || (frame == 180)) {
        ledOn(LED_COMPBAY);
        ledOn(LED_CARGO);
        ledOn(LED_DAMAGED);
        ledOn(LED_SHIELDS);
        ledOn(LED_DAMAGED);
        ledOn(LED_BRIDGE);
        ledOn(LED_ENGINE1);
        ledOn(LED_ENGINE2);
        ledOn(LED_ENGINEERING);
        ledOff(LED_PERSON_COMPBAY);
        ledOff(LED_PERSON_CARGO);
        ledOff(LED_PERSON_DAMAGED);
        ledOff(LED_PERSON_SHIELDS);
        ledOff(LED_PERSON_BRIDGE);
        ledOff(LED_PERSON_ENGINE);
        ledOff(LED_PERSON_ENGINEERING);
        ledShow();
    }
    else if (frame == 195) {
        ledPulse(LED_PERSON_ENGINEERING);
        ledShow();
    }
}

/**
 * Handler to show the LED blink during party mode
 * @param frame
 * @param p_data
 */
static void partyCallback(uint8_t frame, void *p_data){

}

typedef enum {
    item_games,
    item_extras,
    item_credits,
    NUM_MENU_MAIN_ITEMS
} MENU_MAIN;


MENU mainMenu[NUM_MENU_MAIN_ITEMS] = {
        { item_games, "Games" },
        { item_extras, "Extras"},
        { item_credits, "Credits" },
};

/**
 * @brief Main app
 * @return Not used
 */
int main(void){

    #ifdef DC801_DESKTOP

    signal(SIGINT, sig_handler);

    #endif

    // Setup the system
    log_init();
    button_init();
    speaker_init();


    // Timers
    app_timer_init();
    usb_serial_init();

    // BLE
    //gap_params_init();
    ble_stack_init();
    scan_start();

#ifdef DC801_EMBEDDED
    // Init the display
    st7735_init();
	st7735_start();
	util_gfx_init();
#endif

    // Init the random number generator
    nrf_drv_rng_init(NULL);

    // Setup the battery monitor
    adc_configure();
    adc_start();

    // Setup the UART
    uart_init();

    // Setup I2C
    twi_master_init();

    // Setup I2S
    i2s_master_init();

    // Setup LEDs
    ledInit();
    ledsOff();

    morseInit();

    if(!util_sd_init()){
        util_sd_error();
    }

#ifdef DC801_DESKTOP
    if(SDL_Init(SDL_INIT_VIDEO) < 0)
    {
        printf("SDL could not initialize! SDL_Error: %s\n", SDL_GetError());
        exit(1);
    }
    else
    {
        //Create window
        SDL_CreateWindowAndRenderer(SCREEN_WIDTH, SCREEN_HEIGHT, SDL_WINDOW_SHOWN, &window, &renderer);

        if( window == NULL )
        {
            printf("Window could not be created! SDL_Error: %s\n", SDL_GetError());
            exit(1);
        }
        else
        {
            SDL_RenderSetLogicalSize(renderer, SCREEN_WIDTH, SCREEN_HEIGHT);
        }
    }
#endif

    // Boot! Boot! Boot!
    printf("Booted!\n");
    // printf goes to the RTT_Terminal.log after you've fired up debug.sh

    EEpwm_init();

    // Init the WarGames game
    wg_Init();

    // Configure the systick
    sysTickStart();

    // Setup a timer for shutting down animations in standby
    app_timer_create(&standby_animation_timer_id, APP_TIMER_MODE_SINGLE_SHOT, standby_animation_timeout_handler);

    const char* ble_name = "TaSheep801"; // must be 10char
    printf("advertising user: %s\n", ble_name);
    advertising_setUser(ble_name);
    ble_adv_start();

#ifdef DC801_EMBEDDED
#pragma clang diagnostic push
#pragma clang diagnostic ignored "-Wmissing-noreturn"
#endif
    while(true) {

        #ifdef DC801_DESKTOP

        if (application_quit)
        {
            break;
        }

        #endif

        p_canvas()->clearScreen(COLOR_BLACK);
        // util_gfx_fill_screen(COLOR_BLACK);

        // HCRN();
        MAGE();
    }
#ifdef DC801_EMBEDDED
#pragma clang diagnostic pop
#endif

#ifdef DC801_DESKTOP
    SDL_DestroyWindow(window);
    SDL_Quit();

    printf("Exiting gracefully...\n");
    return 0;
#endif
}

/**
 * Show the standby screen
 * @param p_context
 */
void showStandby(void){

    uint16_t nearbyCounter = 0;
    uint16_t animationCounter = 0;
    uint8_t delayCount = 0;
    drawStandby();

    while(true){
        if(getButton(false)){
            // User pressed a button
            return;
        }
        nrf_delay_ms(25);

        if(partyMode){
            // PARTYYYY!
            p_canvas()->drawLoopImageFromFile(0, 0, WIDTH, HEIGHT, "EXTRAS/SHEEP6.RAW", partyCallback, NULL);
            // util_gfx_draw_raw_file("/EXTRAS/SHEEP6.RAW", 0, 0, GFX_WIDTH, GFX_HEIGHT, partyCallback, true, NULL);
        }

        if(sheepMode){
            // SHEEEEP
            do{
                uint8_t i;

                p_canvas()->drawImageFromFile(0, 0, WIDTH, HEIGHT, "EXTRAS/SHEEP1.RAW");
                // util_gfx_draw_raw_file("/EXTRAS/SHEEP1.RAW", 0, 0, GFX_WIDTH, GFX_HEIGHT, NULL, false, NULL);

                for(i = 0; i < 100; i++){
                    if(getButton(false)){
                        break;
                    }
                    nrf_delay_ms(25);
                }

                p_canvas()->drawImageFromFile(0, 0, WIDTH, HEIGHT, "EXTRAS/SHEEP2.RAW");
                // util_gfx_draw_raw_file("/EXTRAS/SHEEP2.RAW", 0, 0, GFX_WIDTH, GFX_HEIGHT, NULL, false, NULL);

                for(i = 0; i < 100; i++){
                    if(getButton(false)){
                        break;
                    }
                    nrf_delay_ms(25);
                }

                p_canvas()->drawImageFromFile(0, 0, WIDTH, HEIGHT, "EXTRAS/SHEEP3.RAW");
                // util_gfx_draw_raw_file("/EXTRAS/SHEEP3.RAW", 0, 0, GFX_WIDTH, GFX_HEIGHT, NULL, false, NULL);

                for(i = 0; i < 100; i++){
                    if(getButton(false)){
                        break;
                    }
                    nrf_delay_ms(25);
                }

                p_canvas()->drawImageFromFile(0, 0, WIDTH, HEIGHT, "EXTRAS/SHEEP4.RAW");
                // util_gfx_draw_raw_file("/EXTRAS/SHEEP4.RAW", 0, 0, GFX_WIDTH, GFX_HEIGHT, NULL, false, NULL);

                for(i = 0; i < 100; i++){
                    if(getButton(false)){
                        break;
                    }
                    nrf_delay_ms(25);
                }

                p_canvas()->drawImageFromFile(0, 0, WIDTH, HEIGHT, "EXTRAS/SHEEP5.RAW");
                // util_gfx_draw_raw_file("/EXTRAS/SHEEP5.RAW", 0, 0, GFX_WIDTH, GFX_HEIGHT, NULL, false, NULL);

                for(i = 0; i < 100; i++){
                    if(getButton(false)){
                        break;
                    }
                    nrf_delay_ms(25);
                }

                p_canvas()->drawImageFromFile(0, 0, WIDTH, HEIGHT, "EXTRAS/SHEEP6.RAW");
                // util_gfx_draw_raw_file("/EXTRAS/SHEEP6.RAW", 0, 0, GFX_WIDTH, GFX_HEIGHT, NULL, false, NULL);

                for(i = 0; i < 100; i++){
                    if(getButton(false)){
                        break;
                    }
                    nrf_delay_ms(25);
                }
            }while (!getButton(false));
        }

        if(animationCounter ++ > (15000 / 25)){
            // Show an animation

            uint8_t rand;
            nrf_drv_rng_rand(&rand, 1);

            char files[64][9];
            uint8_t numFiles = 0;

            memset(files, 0, sizeof(files));

            numFiles = getFiles(files, "/EXTRAS", 64);

            rand = rand % numFiles;

            app_timer_start(standby_animation_timer_id, APP_TIMER_TICKS(10000), NULL);

            char filename[21];
            snprintf(filename, 21, "/EXTRAS/%s.RAW", files[rand]);

            p_canvas()->drawLoopImageFromFile(0, 0, WIDTH, HEIGHT, filename);
            // util_gfx_draw_raw_file(filename, 0, 0, GFX_WIDTH, GFX_HEIGHT, NULL, true, NULL);

            animationCounter = 0;

            drawStandby();

        }

        if(nearbyCounter++ > (5000 / 25)){
            // Draw a shout
            uint8_t rand;
            nrf_drv_rng_rand(&rand, 1);

            bool haveBadge = false;
            BADGE_ADV badge;
            rand = rand % getBadgeNum();

            if(getBadge(rand, &badge)){

                if(getBadgeIconFile(badge.group) != NULL)
                {
                    p_canvas()->drawImageFromFile(0, 0, WIDTH, HEIGHT, getBadgeIconFile(badge.group));
                    // util_gfx_draw_raw_file(getBadgeIconFile(badge.group), 0, 0, GFX_WIDTH, GFX_HEIGHT, NULL, false, NULL);
                }
                else
                {
                    p_canvas()->drawImageFromFile(0, 0, WIDTH, HEIGHT, "GROUPS/MISSING.RAW");
                    // util_gfx_draw_raw_file("/GROUPS/MISSING.RAW", 0, 0, GFX_WIDTH, GFX_HEIGHT, NULL, false, NULL);

                    p_canvas()->fillRect(0, 0, WIDTH, 15, COLOR_BLACK);
                    // util_gfx_fill_rect(0, 0, GFX_WIDTH, 15, COLOR_BLACK);

                    // uint16_t w, h;
                    // util_gfx_get_text_bounds(groupName, 0, 0, &w, &h);

                    const char *groupName = getBadgeGroupName(badge.group);
                    bounds_t bounds = { 0 };
                    p_canvas()->getTextBounds(VeraMono5pt7b, groupName, 0, 0, &bounds);

                    char name[16];
                    snprintf(name, 16, "%s", groupName);

                    p_canvas()->printMessage(name, VeraMono5pt7b, COLOR_WHITE, 64 - (bounds.width / 2), 2);
                    // util_gfx_set_font(FONT_VERAMONO_5PT);
                    // util_gfx_set_cursor(64 - (w / 2), 2);
                    // util_gfx_print(name);
                }

                for(int i = 0; i < 10; i++){
                    if(i % 2 == 0) {
                        setPowerUpLEDs(POWERUP_4);
                        setLevelLEDs(LEVEL0);
                    }
                    else{
                        setPowerUpLEDs(POWERUP_0);
                        setLevelLEDs(LEVEL4);
                    }

                    delayCount = 0;
                    while(delayCount++ < 10) {
                        if(getButton(false)){
                            setPowerUpLEDs(POWERUP_0);
                            setLevelLEDs(LEVEL0);
                            return;
                        }
                        nrf_delay_ms(25);
                    }
                }
                setPowerUpLEDs(POWERUP_0);
                setLevelLEDs(LEVEL0);

                delayCount = 0;
                while(delayCount++ < 40) {
                    if(getButton(false)){
                        return;
                    }
                    nrf_delay_ms(25);
                }

                drawStandby();
            }

            nearbyCounter = 0;

        }
    }

}

typedef enum {
    game_invaders,
    game_snake,
    game_pips_the_et,
    game_tic_tac_toe,
    NUM_MENU_GAMES_ITEMS
} MENU_GAMES;


MENU gameMenu[NUM_MENU_GAMES_ITEMS] = {
        { game_invaders, "Invaders" },
        { game_snake, "Snake" },
        { game_pips_the_et, "Pips the ET" },
        { game_tic_tac_toe, "TicTacToe" }
};


/**
 * Show the games menu
 */
void games(void){

    drawScreenTemplate();

    int retScore = 0;
    int getGame;
    getGame = getMenuSelection(gameMenu, 25, ARRAY_SIZE(gameMenu) , 4, 15000, true);

    switch(getGame){
        case game_invaders:
            // Space invaders
            retScore = SpaceInvaders(normal, false, 0).score;
            break;
        case game_snake:
            // Snake run
            retScore = Snake();
            break;
        case game_pips_the_et:
            retScore = PipsTheET();
            break;
        case game_tic_tac_toe:
            retScore = TicTacToe();
            break;
        default:
            break;
    }


    // Figure out the score modifier
    retScore = retScore + (retScore * ((getTotalScoreModifier() / 100)));

    // Calculate the user's score
    if(user.score + retScore > 0){
        user.score += retScore;
    }
    else{
        user.score = 0;
    }

    //storeUser();
    //advertising_setScore(user.score);

}




typedef enum {
    extra_fun,
    extra_version,
    NUM_MENU_EXTRA_ITEMS
} MENU_EXTRA;


MENU extraMenu[NUM_MENU_EXTRA_ITEMS] = {
        { extra_fun, "Fun Stuff" },
        { extra_version, "Version" }
};

/**
 * Show the extras menu
 */
void extras(void)
{
    drawScreenTemplate();

    int getExtra = getMenuSelection(extraMenu, 25, ARRAY_SIZE(extraMenu), 4, 15000, true);

    switch(getExtra)
    {
        case extra_fun:
            extraFunBrowser();
            break;
        case extra_version:
            extraVersion();
            break;
        default:
            break;
    }
}

/**
 * Show the credits
 */
void credits(void)
{
    p_canvas()->drawImageFromFile(0, 0, WIDTH, HEIGHT, "CREDITS.RAW");
    // util_gfx_draw_raw_file("CREDITS.RAW", 0, 0, GFX_WIDTH, GFX_HEIGHT, NULL, false, NULL);

    while(true)
    {
        if(getButton(false))
        {
            // User pressed a button
            return;
        }
        nrf_delay_ms(10);
    }
}


void menu(void)
{
    p_canvas()->clearScreen(COLOR_BLACK);
    // util_gfx_fill_screen(COLOR_BLACK);

    drawScreenTemplate();

    int subMenu = getMenuSelection(mainMenu, 25, ARRAY_SIZE(mainMenu), 4, 15000, true);

    switch(subMenu)
    {
        case item_games:
            games();
            break;
        case item_extras:
            extras();
            break;
        case item_credits:
            credits();
            break;
        default:
            return;
    }
}

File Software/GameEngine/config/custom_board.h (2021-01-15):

/**
 *
 * @file custom_board.h
 *
 * @date May 24, 2017
 * @author hamster
 *
 * This is the custom board defines for the LEDs and etc on the DC25 badge
 *
 */

#ifndef DC801_H
#define DC801_H

#ifdef __cplusplus
extern "C" {
#endif

//Start address of ROM memoryu addressing
#define ROM_START_ADDRESS (0x12000000)

// Low is active
#define LEDS_ACTIVE_STATE    0

// Defines for preventing unused framebuffer functions from blowing up the compiler:
#define BUTTONS_NUMBER       0
#define BUTTONS_ACTIVE_STATE NRF_GPIO_PIN_SENSE_LOW
#define USER_BUTTON_NONE     0

// Keyboard config
#define KEYBOARD_ADDRESS    0x23
#define KEYBOARD_INT_PIN    18

//UART config:
#define RX_PIN_NUMBER       8
#define TX_PIN_NUMBER       6
#define CTS_PIN_NUMBER      NRF_UART_PSEL_DISCONNECTED
#define RTS_PIN_NUMBER      NRF_UART_PSEL_DISCONNECTED
#define HWFC                false

// LCD
#define LCD_SPIM_INSTANCE   3

#define ILI9341_SCK_PIN		28
#define ILI9341_MOSI_PIN	30
#define ILI9341_PIN_CS		31
#define ILI9341_PIN_DC		29
#define ILI9341_PIN_LED		0
#define ILI9341_PIN_RESET	32+10

#define LCD_WIDTH  			320
#define LCD_HEIGHT 			240
#define LCD_X_OFFSET		0
#define LCD_Y_OFFSET		0

// I2C configuration
#define I2C_INSTANCE        0

#define I2C_SCL_PIN         23
#define I2C_SDA_PIN         22

//I2S configuration
#define I2S_TWI_INST		1
#define I2S_SCL_M			3
#define I2S_SDA_M			32+13

#define I2S_SCK_M			5
#define I2S_LRCK_M			32+15
#define I2S_MCK_M			32+14
#define I2S_SDOUT_M			7

// SD card interface
#define SDC_SCK_PIN         17
#define SDC_MOSI_PIN        21
#define SDC_MISO_PIN        16
#define SDC_CS_PIN          19

//QSPI Configuration
#define BSP_QSPI_SCK_PIN   12
#define BSP_QSPI_CSN_PIN   2
#define BSP_QSPI_IO0_PIN   13
#define BSP_QSPI_IO1_PIN   12+32
#define BSP_QSPI_IO2_PIN   14
#define BSP_QSPI_IO3_PIN   1


// Clock
// Low frequency clock source to be used by the SoftDevice
// We're using the internal RC osc
#define NRF_CLOCK_LFCLKSRC      {.source        = NRF_CLOCK_LF_SRC_RC, \
                                 .rc_ctiv       = 16, \
                                 .rc_temp_ctiv  = 2, \
                                 .xtal_accuracy = NRF_CLOCK_LF_XTAL_ACCURACY_20_PPM}


#ifdef __cplusplus
}
#endif

#endif // DC801_H

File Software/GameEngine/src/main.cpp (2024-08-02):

/**
 *
 * @file main.c
 *
 * @date May 24, 2017
 * @author hamster
 *
 * @brief This is the entry point for the DC801 DC26 party badge
 *
 */

#include "main.h"
#include "games/mage/mage.h"
#include "FrameBuffer.h"
#include "EnginePanic.h"
#include "fonts/Monaco9.h"

#ifdef DC801_EMBEDDED
//only init QSPI if we're in embedded mode:
#include "qspi.h"
QSPI qspiControl;

#endif

#include "test.h"

#ifdef DC801_DESKTOP
#include <time.h>
#include "EngineWindowFrame.h"
volatile sig_atomic_t application_quit = 0;

void sig_handler(int signo)
{
	if (signo == SIGINT)
	{
		debug_print("received SIGINT\n");
		application_quit = 1;
	}
}

#endif

#define XVAL(x) #x
#define VAL(x)  XVAL(x)

/*
#pragma message ("TIMER_ENABLED=" VAL(TIMER_ENABLED))
#pragma message ("TIMER1_ENABLED=" VAL(TIMER1_ENABLED))
#pragma message ("NRFX_TIMER_ENABLED=" VAL(NRFX_TIMER_ENABLED))
#pragma message ("NRFX_TIMER1_ENABLED=" VAL(NRFX_TIMER1_ENABLED))
*/

/**
 * Initialize the speaker
 */
static void speaker_init(void){
	// Setup the nau8810 later -Tim
	//nrf_gpio_cfg_output(SPEAKER);
}

/**
 * Initialize the logging backend for logging over JTAG
 */
static void log_init(void){
	ret_code_t err_code = NRF_LOG_INIT(NULL);
	APP_ERROR_CHECK(err_code);
	NRF_LOG_DEFAULT_BACKENDS_INIT();
	NRF_LOG_INFO("--------------SYSTEM REBOOTED--------------");
	NRF_LOG_ERROR("Error Logging to hardware UART enabled.");
	NRF_LOG_INFO("Debug Logging to hardware UART enabled.");
}

/**
 * Initialize the QSPI ROM object
 */
static void rom_init(void){
	#ifdef DC801_EMBEDDED
	if(!qspiControl.init()){
		ENGINE_PANIC("Failed to init qspiControl.");
	}
	#endif
}

/**
 * @brief Main app
 * @return Not used
 */
int main(void){

	#ifdef DC801_DESKTOP
	EngineWindowFrameInit();
	signal(SIGINT, sig_handler);

	#endif

	// Setup the system
	log_init();

	// Timers
	app_timer_init();

#ifdef DC801_EMBEDDED

	//USB serial
	usb_serial_init();

	//keyboard controls all hardware buttons on this badge
	keyboard_init();

	//this function will set up the NAU8810 chip to play sounds
	//speaker_init();

	// BLE
	//gap_params_init();
	ble_stack_init();
	scan_start();

	// Init the display
	ili9341_init();
	ili9341_start();
	util_gfx_init();

	//Init the SD Card
	if(!util_sd_init()){
		//util_sd_error();
		debug_print("No SD card present on boot.");
	}

	//QSPI ROM Chip
	rom_init();

	// Init the random number generator
	nrf_drv_rng_init(NULL);

	// Setup the battery monitor
	//adc_configure();
	//adc_start();

	// Setup the UART
	//uart_init();

	// Setup I2C
	twi_master_init();

	//EEpwm_init();

	const char* ble_name = "TheMage801"; // must be 10char
	debug_print("advertising user: %s", ble_name);
	advertising_setUser(ble_name);
	ble_adv_start();
#endif

	setUpRandomSeed();
	// Setup LEDs
	ledInit();
	ledsOff();

	//morse isn't used on this badge yet...
	//morseInit();

	// Configure the systick
	sysTickStart();

	// Boot! Boot! Boot!
	debug_print("Booted!\n");
	// printf goes to the RTT_Terminal.log after you've fired up debug.sh

#if defined(TEST) || defined(TEST_ALL)
	DC801_Test::Test();
	break;
#else
	MAGE();
#endif

#ifdef DC801_DESKTOP
	debug_print("Exiting gracefully...\n");
	EngineWindowFrameCleanup();
	return 0;
#endif

#ifdef DC801_EMBEDDED
	while (1)
	{
		// If we make it here - we shouldn't - but if, reset the badge
		NVIC_SystemReset();
	}
#endif
}

void setUpRandomSeed() {
#ifdef DC801_EMBEDDED
	//Set random seed with something from nordic sdk,
	//so as long as nrf_drv_rng_init() has been run,
	//this is actually pretty random, probably.
	uint32_t seed = (
		(nrf_rng_random_value_get() <<  0) +
		(nrf_rng_random_value_get() <<  8) +
		(nrf_rng_random_value_get() << 16) +
		(nrf_rng_random_value_get() << 24)
	);
#endif //DC801_EMBEDDED

#ifdef DC801_DESKTOP
	//Set random seed with number of seconds since
	//unix epoc so two desktops launched the same
	//second get the same rng, and that totally
	//doesn't matter. Good enough for a simple
	//dice roll for scripts.
	uint32_t seed = time(NULL);
#endif //DC801_DESKTOP
	srand(seed);
}

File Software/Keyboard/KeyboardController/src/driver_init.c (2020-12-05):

/**
 * \file
 *
 * \brief Driver initialization.
 *
 (c) 2020 Microchip Technology Inc. and its subsidiaries.

    Subject to your compliance with these terms,you may use this software and
    any derivatives exclusively with Microchip products.It is your responsibility
    to comply with third party license terms applicable to your use of third party
    software (including open source software) that may accompany Microchip software.

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
    IN NO EVENT WILL MICROCHIP BE LIABLE FOR ANY INDIRECT, SPECIAL, PUNITIVE,
    INCIDENTAL OR CONSEQUENTIAL LOSS, DAMAGE, COST OR EXPENSE OF ANY KIND
    WHATSOEVER RELATED TO THE SOFTWARE, HOWEVER CAUSED, EVEN IF MICROCHIP HAS
    BEEN ADVISED OF THE POSSIBILITY OR THE DAMAGES ARE FORESEEABLE. TO THE
    FULLEST EXTENT ALLOWED BY LAW, MICROCHIP'S TOTAL LIABILITY ON ALL CLAIMS IN
    ANY WAY RELATED TO THIS SOFTWARE WILL NOT EXCEED THE AMOUNT OF FEES, IF ANY,
    THAT YOU HAVE PAID DIRECTLY TO MICROCHIP FOR THIS SOFTWARE.
 *
 */

/*
 * Code generated by START.
 *
 * This file will be overwritten when reconfiguring your START project.
 * Please copy examples or other code you want to keep to a separate file
 * to avoid losing it when reconfiguring.
 */

#include "driver_init.h"
#include <system.h>

/* Configure pins and initialize registers */
void ADC_0_initialization(void)
{

	Xp_set_isc(PORT_ISC_INPUT_DISABLE_gc);
	Xp_set_pull_mode(PORT_PULL_OFF);

	Yp_set_isc(PORT_ISC_INPUT_DISABLE_gc);
	Yp_set_pull_mode(PORT_PULL_OFF);

	Xm_set_level(false);
	Xm_set_dir(PORT_DIR_OFF);
	Xm_set_pull_mode(PORT_PULL_OFF);
	Xm_set_inverted(false);
	Xm_set_isc(PORT_ISC_INTDISABLE_gc);
	
	Ym_set_level(false);
	Ym_set_dir(PORT_DIR_OFF);
	Ym_set_pull_mode(PORT_PULL_OFF);
	Ym_set_inverted(false);
	Ym_set_isc(PORT_ISC_INTDISABLE_gc);

	ADC_0_init();
}

void TIMER_0_initialization(void)
{

	TIMER_0_init();
}

/* configure pins and initialize registers */
void I2C_0_initialization(void)
{

	PB0_set_level(false);
	PB0_set_dir(PORT_DIR_OUT);
	PB0_set_pull_mode(PORT_PULL_OFF);
	PB0_set_inverted(false);
	PB0_set_isc(PORT_ISC_INTDISABLE_gc);

	PB1_set_level(false);
	PB1_set_dir(PORT_DIR_OUT);
	PB1_set_pull_mode(PORT_PULL_OFF);
	PB1_set_inverted(false);
	PB1_set_isc(PORT_ISC_INTDISABLE_gc);

	I2C_0_init();
}

/**
 * \brief System initialization
 */
void system_init()
{
	mcu_init();
	
	/* PORT setting on PA5 */

	R0_set_level(true);
	R0_set_dir(PORT_DIR_OUT);
	R0_set_pull_mode(PORT_PULL_OFF);
	R0_set_inverted(false);
	R0_set_isc(PORT_ISC_INTDISABLE_gc);

	/* PORT setting on PA4 */

	R1_set_level(true);
	R1_set_dir(PORT_DIR_OUT);
	R1_set_pull_mode(PORT_PULL_OFF);
	R1_set_inverted(false);
	R1_set_isc(PORT_ISC_INTDISABLE_gc);

	/* PORT setting on PA3 */

	R2_set_level(true);
	R2_set_dir(PORT_DIR_OUT);
	R2_set_pull_mode(PORT_PULL_OFF);
	R2_set_inverted(false);
	R2_set_isc(PORT_ISC_INTDISABLE_gc);

	/* PORT setting on PA2 */

	R3_set_level(true);
	R3_set_dir(PORT_DIR_OUT);
	R3_set_pull_mode(PORT_PULL_OFF);
	R3_set_inverted(false);
	R3_set_isc(PORT_ISC_INTDISABLE_gc);
	
	/* PORT setting on PA1 */

	R4_set_level(true);
	R4_set_dir(PORT_DIR_OUT);
	R4_set_pull_mode(PORT_PULL_OFF);
	R4_set_inverted(false);
	R4_set_isc(PORT_ISC_INTDISABLE_gc);

	/* PORT setting on PB2 */

	C0_set_level(false);
	C0_set_dir(PORT_DIR_IN);
	C0_set_pull_mode(PORT_PULL_UP);
	C0_set_inverted(false);
	C0_set_isc(PORT_ISC_INTDISABLE_gc);

	/* PORT setting on PB6 */

	C1_set_level(false);
	C1_set_dir(PORT_DIR_IN);
	C1_set_pull_mode(PORT_PULL_UP);
	C1_set_inverted(false);
	C1_set_isc(PORT_ISC_INTDISABLE_gc);

	/* PORT setting on PB5 */

	C2_set_level(false);
	C2_set_dir(PORT_DIR_IN);
	C2_set_pull_mode(PORT_PULL_UP);
	C2_set_inverted(false);
	C2_set_isc(PORT_ISC_INTDISABLE_gc);

	/* PORT setting on PB7 */

	C3_set_level(false);
	C3_set_dir(PORT_DIR_IN);
	C3_set_pull_mode(PORT_PULL_UP);
	C3_set_inverted(false);
	C3_set_isc(PORT_ISC_INTDISABLE_gc);

	/* PORT setting on PB4 */

	C4_set_level(false);
	C4_set_dir( PORT_DIR_IN);
	C4_set_pull_mode(PORT_PULL_UP);
	C4_set_inverted(false);
	C4_set_isc(PORT_ISC_INTDISABLE_gc);

	/* PORT setting on PB3 */

	C5_set_level(false);
	C5_set_dir(PORT_DIR_IN);
	C5_set_pull_mode(PORT_PULL_UP);
	C5_set_inverted(false);
	C5_set_isc(PORT_ISC_INTDISABLE_gc);

	/* PORT setting on PC5 */

	// Set pin direction to output

	KEY_INT_set_inverted(true);
	KEY_INT_set_level(false);
	KEY_INT_set_dir(PORT_DIR_OUT);

	CLKCTRL_init();

	Timer_init();

	ADC_0_initialization();

	TIMER_0_initialization();

	CPUINT_init();

	SLPCTRL_init();

	I2C_0_initialization();

	BOD_init();
}

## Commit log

2020-05-21 More Windows fixes for build system
    [jlink.cfg]
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2020-06-18 Fix desktop screen flicker
    [custom_board.h]
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2020-08-02 Support Map Tile X and Y flipping, Add Town Map
    [main.c]
2020-08-11 Initial commit of hardware files
    [purplewizard-ART-B_CrtYd.gbr, purplewizard-ART-B_Cu.gbl, purplewizard-ART-B_Fab.gbr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]
2020-08-12 Adding design files for the backboard
    [01_tactile_push_boton_B3S-1000_newark_52F3560.SLDPRT, 01_tactile_push_boton_B3S-1000_newark_52F3560.STEP, 1054500101.stp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]
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2020-09-03 Fix C vs C++ issues
    Anything using the framebuffer needs to be .cpp, even if it's actually C
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2020-09-03 Moved FrameBuffer.cpp to engine
    Moved FrameBuffer.cpp to engine and changed all necessary #include statements to point to it's new location.
2020-09-13 Updated to keep KeyInt high normally to prevent possible issue with holding the BMD340 in reset Fixed formatting in README.md
    [driver_init.c, main.c]
2020-09-13 Add mutex to i2c driver
    Since we are adding asynchronous I2C calls, the driver needs to have a mutex to prevent collisions with different asynchronous and synchronous calls
    [i2c.c]
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2020-09-19 Fix keyboard driver for desktop build
    [keyboard.c]
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2020-09-21 KEY_BIT* buttons start toggling LED_BIT* state
    - Move apply_input_to_player(uint8_t *data) into `mage_input.cpp`
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2020-09-25 Add Monaco9.h AdaFruit GFXfont
    - Also update Framebuffer.write_char to respect new screen size
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2020-09-27 HexEditor: Add Header & Pagination of Memory
    - Fix bug with FrameBuffer->printMessage to wrap X correctly on newline
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2020-10-21 Encoder: Fix duplication of 0th entityType
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2020-10-21 Added Quick-Press Page and Snap-To-Cursor When quickly pressing and releasing page button, advance 1 mem page. When on another page, moving cursor changes page to cursor's page.
2020-10-22 Buttons.rjoy_left triggers playerEntity "action"
    - While the action plays, all other player input is paused/suspended until action completes because allowing the player entity to keep sliding while the action plays looks terrible
    - Add a front-facing Goose tail-waggle animation because idle "animations" with only one frame cause the action animation to either 1: not play or 2: not repeat their action animation while the butto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
2020-10-22 Start on mem buttons, fixed hex editor logic bug
2020-10-22 Memory Buttons Now Working Press mem button in hex editor to save location to that register press mem button in game to swap to that address for live edits
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2020-10-25 Structs were dumb, switched to switch case runAction function will write argument values for each actionTypeId
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2020-10-28 Encoder: Fix Action:CHECK_FOR_BUTTON_PRESS
2020-10-29 Encoder: Fix Spaces -> Tabs, BAD EDITOR, BAD!
2020-10-29 Fixed button check bugs
2020-11-01 Encoder: Add Scripts for entity[onInteract/onTick]
    - Scripts become scoped to map local script IDs
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2020-11-02 Encoder: Fix bug in `SET_ENTITY_DIRECTION`
2020-11-02 Encoder: Fix actions should use mapLocalScriptIds
2020-11-04 Encoder: Fix mapLocalScriptIds with call scripts
2020-11-07 Encoder: Fix script call infinite loop
2020-11-08 Encoder: Scenario Scripts stored in own files
    - Also fixed bug where global null_script was not added to each map
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2020-11-09 Encoder: Unify Action encoding and sanitization
    - Add `%PLAYER%` = 253 special entity
    - Implement CHECK_IF_ENTITY_IS_IN_GEOMETRY
    - Implement WALK_ENTITY_TO_GEOMETRY
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2020-11-15 Removed broken legacy input code + affected files
    [custom_board.h, keyboard.c, main.cpp]
2020-11-15 Fixed framebuffer warnings
2020-11-15 Fixed i2c and LED modules, LEDs are now working
    [i2c.c, main.cpp]
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2020-11-15 Fixed LED Graphics on Desktop Frame
    [main.cpp]
2020-11-17 Fixed conflict between SD Card and NAU8810 pins
    [custom_board.h, main.cpp]
2020-11-17 Removed a bunch of code not currently in use We can restore these as needed in the future once the core of the badge game works.
2020-11-18 fixed draw_raw_async to work in chunks
    [main.cpp]
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2020-11-22 Backboard - Move LCD connector over .3mm for better fitment of ribbon - Fix audio chip missing exposed pad bond to ground - Remove nRESET signal from JTAG - Reuse freed pin above to run an interrupt 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
    [BOM.xlsx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]
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2020-11-23 Testing RAM Corruption Bug w/ Screen Printing
2020-11-28 Encoder: Add %ENTITY_PATH% Geometry value support
    - Action: walkEntityToGeometry now sets entity direction before moving entity
    - Add more EntityTypes to scenario.json
    - Baker
    - Marta
    - Tailor
2020-11-29 Action: Implement compareEntityName
    - Encoder: String serializer now explicitly adds a null termination byte
    - Update todo.md
2020-11-30 Encoder: `entities.json` -> `object_types.json`
    Now it matches the item in the menu in Tiled
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2020-12-01 Fixes for DESKTOP compiling on HW-test branch
    [main.cpp]
2020-12-02 SD Card Read Update for ~100x framerate increase* *Still only running at ~3 frames per minute
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2020-12-03 Major Directory Cleanup for Port to DC801 Github
    [01_tactile_push_boton_B3S-1000_newark_52F3560.SLDPRT, 01_tactile_push_boton_B3S-1000_newark_52F3560.STEP, 1050170001.stp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]
2020-12-05 Fix Encoder errors on 2020-12-04 Demo map/scripts
2020-12-05 Renamed Hardware to HW to match printed art badge
    [01_tactile_push_boton_B3S-1000_newark_52F3560.SLDPRT, 01_tactile_push_boton_B3S-1000_newark_52F3560.STEP, 1054500101.stp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]
2020-12-06 Action Overhaul Initial Setup and C Code Changes Removing generic actions like 'CHECK_ENTITY_BYTE' in favor of specific actions like 'SET_ENTITY_X' or 'CHECK_ENTITY_PRIMARY_ID_TYPE' Still need to fix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
2020-12-06 Action Overhaul: Encoder Update for Action Change
    Implemented remaining actions from first commit, game compiles and runs as well as before.
    Still need to do more testing of actions new and old to verify function.
2020-12-07 Encoder: Add `is_player` to entities, use on load
    - Add Doors to most maps to verify cross map entity `is_player` testing
    - Fix error UI and add loading indicator to Encoder
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2020-12-14 Encoder: Add dismiss/reset of success state too
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2020-12-24 Adding qspi driver Updated environment setup with the BM-Badge repo name Changed the output filename
2020-12-24 Fixed bug with desktop build not compiling
    [main.cpp]
2020-12-25 Various Formatting, Organizational, & Logic Fixes
    - Made EngineROM_Init return a bool instead of void
    - Made EngineROM_Verify return a bool instead of a uint32_t
    - Made #defines for various game.dat file properties
    - Fixed annoying int comparison warning in mage_dialog_control.cpp
    - Realized my test code wasn't successfully writing to the ROM, need to fix.
    - Made the SD card just print debug info instead of ENGINE_PANICing when an SD card is not found
    - Added debug print statement when no SD card is found during startup code sequence in util_sd_error()
    [main.cpp]
2020-12-25 Add code to check & write ROM but write is broken
    -QSPI::write does not return error, but ROM is not being written.
    -Logic is in place to verify ROM data, but without writes working it doesn't do much.
    -For now, the embedded build just gets stuck in a loop after the rom_test() function concludes.
    -Desktop build is still working as before.
    [main.cpp]
2020-12-27 Updated embedded logging to use hardware serial
    -ROM chip has a couple additional checks for erase/write finishes, but is still inconsistent
2020-12-27 VSCode: added 'launch' and 'attach' debug options
    -Launch option behaves like previous physical badge debug, resetting the board and attaching.
    -Attach option will attach the debugger to an already running board at the current execution point.
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2020-12-29 Encoder: Put image tiles in rows for fast read
    - Add workflow script `replace_dat_file_with_downloaded.sh`
    - Fix bug where Images were possibly being encoded duplicate per map
2020-12-30 Fixed Left-Up Swap on Hardware Input Buttons
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2021-01-01 All EngineROM_Read error messages moved internal
    [main.cpp]
2021-01-03 Add direct ROM addressing + misc speed fixes
    -QSPI::read no longer used to get ROM data, using XiP functionality for direct addressing.
    -Adjusted various #defines for better timing feel on embedded build
    [custom_board.h, main.cpp]
2021-01-05 Added basic memory usage checker function
    -Prints free RAM to debug_print() output
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2021-01-07 Encoder: Fix entityType.scenarioIndex for scripts
    - Also encode ALL EntityTypes deterministically based on order in `entity_types.json`
2021-01-11 Encoder: Fix Scripts endianness
2021-01-11 Memory chip Vio tied to Vcc
    [purplewizard-B_CrtYd.gbr, purplewizard-B_Cu.gbl, purplewizard-B_Fab.gbr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]
2021-01-15 Add pads for programming jig Add 3-up panel for finals
    [combined.gbl, combined.gbo, combined.gbp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]
2021-01-15 Updating modified pcb file, output options changed
    [purplewizard.kicad_pcb]
2021-01-15 Rename HW directory to more in line with the rename of the software directory
    [01_tactile_push_boton_B3S-1000_newark_52F3560.SLDPRT, 01_tactile_push_boton_B3S-1000_newark_52F3560.STEP, 1054500101.stp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]
2021-01-16 Adding PogoProto jig Fixed upper right hole being off 3/4 of a millimeter Added some pads for USB and added some vias to help pogo pin alignment
    [1054500101.stp, CK PTS647.SLDPRT, CK PTS647.STEP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]
2021-01-17 Geometry: Handle flipping for drawing & collision
    - Add/use RenderFlagsUnion in Geometry/FrameBuffer
2021-01-17 Updated ART board with upper right hole in the right place.
    [purplewizard-ART-B_CrtYd.gbr, purplewizard-ART-B_Cu.gbl, purplewizard-ART-B_Fab.gbr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]
2021-01-17 Final fab files for the PCBs
    [BOM.xlsx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]
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2021-02-15 Encoder: Throw error if map has too many entities
2021-02-15 MEM LEDS now indicate hexCursorLocation correctly
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2021-03-02 Use ideal FPS instead of deltaTime to fix walk jitter
2021-03-11 Bug fixes: doors are now holes in the walls
2021-03-11 Collision: Complete rewrite using "broom spokes"
    - Simplify out all flipping external to geometry instances, since geometry is now ephemeral, the geometry itself can be flipped
    - Project spokes out from player player center in the direction of their movement vector
    - Hold on to the point of earliest collision along each spoke for each line on all tiles that it crosses, and that is the length of pushback for that spoke
    - Average together all of the spoke pushbacks for a single pushback vector that is added to the player's velocity
2021-03-11 Dialog polish (triangle button, etc); tileset collision vector tuning
2021-03-18 Solved mysteries of haunted `ROM_ERASE_PAGE_SIZE`
    - Show more granular erase message, by the page
    - Only erase number pages to write new game.dat
    [main.cpp]
2021-03-20 Fix last frame of `action` playing for only 1 tick
2021-04-01 Dialog: Fix Encoder not storing `border_tileset`
2021-04-06 Encoder: Add CLI game.dat file build
    - Replace the bloated, broken and canvas-tainted `get-pixels` with `fast-png` & `omggif` for cross-system deterministic builds
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2021-04-08 HexEditor: Fix △/✕ +/- timing, Add BtnsDeactivated
2021-04-08 Update (ROM/Save) headers for bootloader UF2 mode
    - Check Save CRC32s versus game.dat CRC32
    - Check Save length versus MageSaveGame struct length
    - On mismatch, show error, but put a fresh save into RAM and run with that
    [main.cpp]
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2021-04-13 Edge case scripting/dialog; other stuff
    - Cat workers say different things if you're a cat
    - Catwork hint given if you talk to any of them as a cat
    - Sheep loiter consolidation
    - Watch scripts are on better on_tick slots
    - Baker timing no longer yeets him to space
    - Jackob now gives an different hackbook explanation if you've already won the demo
    - Set flags false exa debugging: toggling glitch flags also set glitch state, and correct interact script set on one branch
    - Trent Call added to portraits credits
    - Various animations now 120 millis instead of 135, where it was taking two frames
    - NO BOX OF PRE-INFLATED BALLOONS -- THAT'S RIDICULOUS
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2021-04-13 Desktop: ESC now toggles HexEditor, Alt+F4 quits
    - Add a few extra nice/intuitive mappings
    - Update controls docs table
2021-04-14 Set random seed so rand() is unique each game boot
    - De-duplicate `Cecil` from random name choices
    - Protect the mutateVariable(s) actions against division by zero from content author scripts
    - Correct order of SD/ROM hashes in game.dat update message
    [main.cpp]
2021-05-03 Add is_debug renderFlag, Filter entities at runtime
    - Press XOR and MEM1 to reload current map and toggle debug entities
2021-05-03 Fix entity filter id mapping?
2021-05-04 Encoder sorts debug entities last, fix ID mismatch
    - script system now treats entity IDs past the end of the `filteredEntityCountOnThisMap` as NO_PLAYER, meaning that scripts targeting filtered debug entities are far less likely to RUIN EVERYTHING
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2021-06-06 Hint system polish; misc other polish, including dialog for Yabbo
    - new script for detecting current hint category
    - new debug exa, Mr. Math, verifies that divisions round down
    - now a general hint (from Bert) won't override an advanced hint
    - fixed long delay in TUESDAY cutscene (not sure when that started)
    - fixed text wrap glitch in one of the books
2021-06-12 Updating code to hold the interrupt line high for 2 seconds if a key is pressed during the first ~2 seconds of uptime This is so that the BMD bootloader can more easily detect if it should go into bo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
2021-06-15 Moved the game engine code into a dedicated subdirectory
    [jlink.cfg]
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2021-06-19 Revert controller as the extended interrupt at bootup is no longer needed Move keyboard controller up a directory
    [adc.c, adc.h, adc_basic.c]
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2021-06-19 Scripts: Fix `(SET/CHECK)_ENTITY_PATH` actions
    - Encoder now uses `geometry` field for `(SET/CHECK)_ENTITY_PATH` actions
2021-06-19 Bender handler fix; can now skip splash with button press
2021-07-02 Web Build: Add static file loading paths
    - Still need to fix main loop. It is able to successfully render frames, but only when you pause in the debugger.
    - ![Game rendering in browser, paused on a breakpoint](https://cdn.discordapp.com/attachments/764260773471453226/860425208601772072/unknown.png)
2021-07-06 Web Build: Statically allocate romDataInDesktopRam
    - This will also make reloading the ROM file easier, when the ROM file size changes between content builds
    - Fix compile time error caused by `emcc` autogenerated compile flags trying to be too `smart` and setting an upper bound for allocatable memory that's smaller than ROM size, so force allocate about 48MB, that should be enough
    - Fix runtime crash in because `emcc` told the runtime it would never need more than 16MB, it was throwing errors if it tried
    - ENGINE_PANIC if ROM is so large it won't fit on ROM chip with room for saves
    - Browser now loads raw `game.dat` and frame graphics rather than merged `bm_badge.data`
    - Browser page gains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
2021-07-29 Improve mutex comment; fix printf bugs
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2021-08-22 Web Build: Fix `game.dat` caching issues
    Use HTTP HEAD request to check if remote assets have been modified since what's currently in LocalForage and decide if assets need to be re-downloaded
2021-09-21 Serial: Implement action showSerialDialog's output
    - Still to do: Implement script engine's ability to deal with globalJumpScriptId from showSerialDialog's response choice
    - Implement showSerialDialog's response parsing
    - Implement action: setConnectSerialDialog
    - Add action placeholders for: INVENTORY_GET, INVENTORY_DROP, CHECK_INVENTORY, SET_MAP_LOOK, SET_ENTITY_LOOK, SET_TELEPORT_ENABLED, CHECK_MAP, SET_BLE_FLAG, CHECK_BLE_FLAG
    - Fix bug where Map's on_load script didn't run before the first tick
    [mage_command_control.h]
2021-09-26 Serial: Fix last map directions show after loadMap
    - MageCommand gets a reset on map load
    - Fix some action names to be consistent
    - Also try and simplify script lifecycle a little?
    - Add some "directions" to the hub map
    [mage_command_control.h]
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2022-04-03 ScriptEditor: script renaming bug fix
    (old script names no longer haunt current script names)
2022-05-29 Fix: Encoder should not lowercase dialog options
2022-08-21 Encoder: Fix CLI build for Node > 16.7
2022-09-12 Uprev to 1.1 to support current parts availability Added solderpaste to USB connector through-pins
    [BOM.xlsx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]
2022-09-13 Adding panel for SAOs
    [MiniMageSpells-B_Cu.gbr, MiniMageSpells-B_Fab.gbr, MiniMageSpells-B_Mask.gbr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]
2022-09-13 Forgot to save changes
    [MiniMageSpells.kicad_pcb]
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2023-01-18 SPELLS board kicad
    [BOM.xls, Fab_BOM.csv, neopixel.kicad_sch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]
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2023-06-11 `go` effectively disabled before toot is finished
    - Resuming interrupted tutorial: formatting fix
    - Wizard emerges when a part is installed
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2023-06-12 fix: buttons swapped
2023-06-14 Move SDL types into EngineWindowFrame.h to fix hardware build
    Click handling for the buttons?!? Thanks @cedric-h! This should complete pull request #13
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2023-07-09 Serial: Duplicate verb registration replaces previous
    [mage_command_control.h]
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2023-10-15 Fix: Encoder should encode name of 0th entity
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2023-12-17 Bug fix: Lambda serial message being cut off
2023-12-31 Many minor bug fixes
    - Mousegame lights go back to normal before exit convo, not after
    - Removed a debug message for Simon says
    - Guest book no longer talks
    - `toot` debug command no longer doubles up parts on the map
    - Guardian Bob teleports into place before camera fade, not after
    - Marathon Bobs now face correct direction after being spoken to
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2024-07-11 Soldering no longer involves terminal
2024-08-03 Playtesting fixes
    - Concierge no longer gives verbal permission for needle early
    - Soldering station now appears on map after both halves acquired
    - Cutbug research begun
2025-03-07 add linker option --allow-multiple-definition to common.make
    (if this comes back to bite us, we will need to resolve this error that was showing:
    [ LD ] bm_badge.out
    /usr/share/gcc-arm-none-eabi-10-2020-q4-major/bin/../lib/gcc/arm-none-eabi/10.2.1/../../../../arm-none-eabi/bin/ld: /usr/share/gcc-arm-none-eabi-10-2020-q4-major/bin/../lib/gcc/arm-none-eabi/10.2.1/../../../../arm-none-eabi/lib/thumb/v7e-m+fp/hard/libstdc++_nano.a(math_stubs_long_double.o): in function `ceill':
    math_stubs_long_double.cc:(.text.ceill+0x0): multiple definition of `ceill'; /usr/share/gcc-arm-none-eabi-10-2020-q4-major/bin/../lib/gcc/arm-none-eabi/10.2.1/../../../../arm-none-eabi/lib/thumb/v7e-m+fp/hard/libm.a(lib_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
2025-03-10 switch order of libm and libstdc++ for the linker, resolving multiple definition errors
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2025-08-17 Encoder: Fix TreeSitter MGSParser dependency in CLI
2025-08-20 MGS parse errors now reported by CLI and web encoders
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

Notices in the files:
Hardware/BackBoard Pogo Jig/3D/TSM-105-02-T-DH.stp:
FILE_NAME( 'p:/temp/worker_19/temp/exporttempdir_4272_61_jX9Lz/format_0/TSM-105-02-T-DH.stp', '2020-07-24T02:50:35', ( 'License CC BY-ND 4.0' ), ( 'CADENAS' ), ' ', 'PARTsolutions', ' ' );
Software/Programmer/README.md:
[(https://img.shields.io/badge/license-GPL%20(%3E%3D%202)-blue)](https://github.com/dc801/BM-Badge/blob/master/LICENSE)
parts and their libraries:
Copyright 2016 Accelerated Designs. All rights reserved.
